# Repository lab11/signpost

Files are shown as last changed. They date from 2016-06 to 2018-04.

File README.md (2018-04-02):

Signpost
========



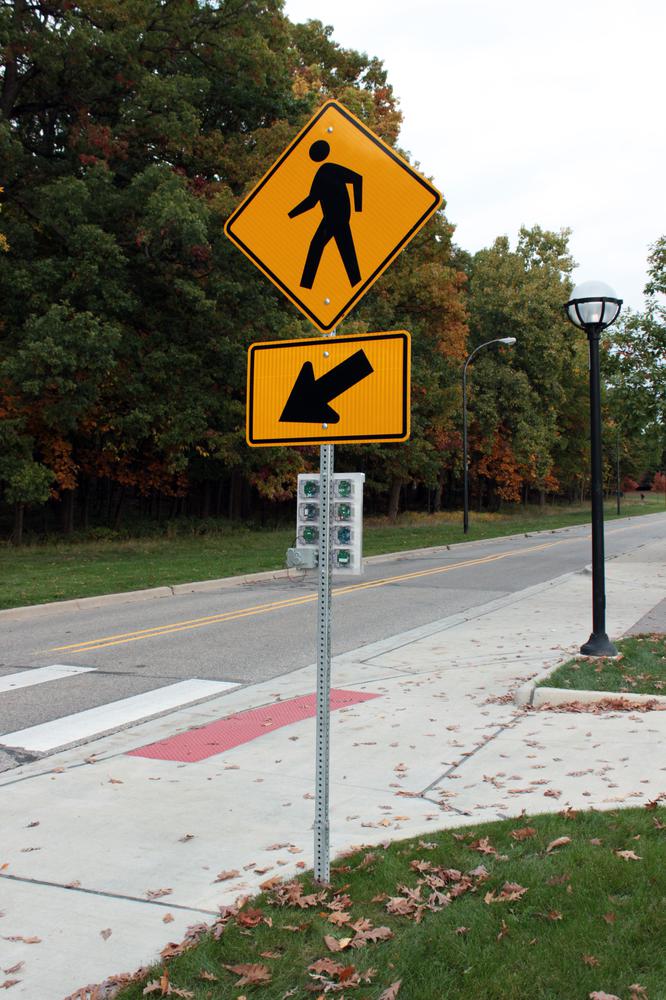
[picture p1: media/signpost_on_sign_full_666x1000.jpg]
Signpost

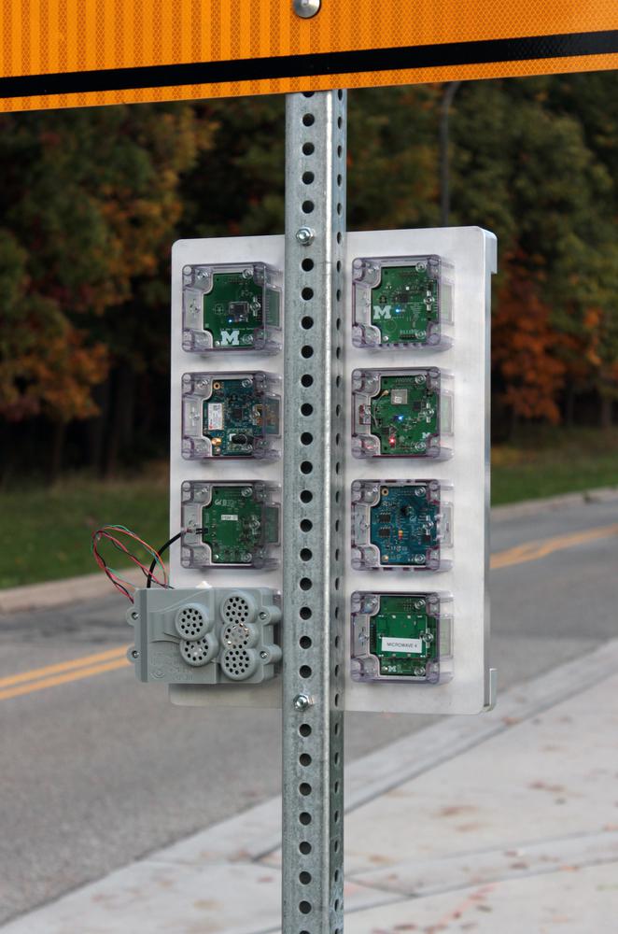
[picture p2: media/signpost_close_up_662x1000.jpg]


The Signpost project is a modular city-scale sensing platform that is designed 
to be installed on existing signposts. It is powered through solar energy harvesting, 
and provides six slots for generic sensing tasks. Modules have access to
a set of shared platform resources including power, communication, gps-based
location and time, storage, and higher-performance computation, and they
use a Signpost-specific software API that enables not only use of these
resources, but also supports the development of inter-module applications.

The project is driven by several core applications, but also strives to be
an upgradeable and adaptable platform that supports new applications
for scientists and cities. Modules can be added and removed from the platform
after deployment without disassembling the installed Signpost, reprogramming
the Signpost, or interrupting the other functions of the Signpost. Additionally,
by providing APIs to modules that support common operations, developing and
deploying a sensing application in a city is significantly streamlined. A focus
of this project is ensuring that domain scientists and researchers interested
in city-scale applications can effectively leverage this platform to accelerate
their projects.

<br />

Hardware Architecture
---------------------

Each Signpost platform includes a power supply that also meters energy usage, a controller that provides
storage and computation and manages the operation of the Signpost, and several module slots that support
extensible sensor modules for city-scale sensing applications. All modules are connected via an I2C bus,
and core system features (e.g. per-module energy metering) are on a SMBus network. For higher bandwidth
communication on the Signpost, each module is also attached to a USB 2.0 host.

Each module can be individually disconnected from the USB host and/or the I2C bus, as well as entirely
powered off.

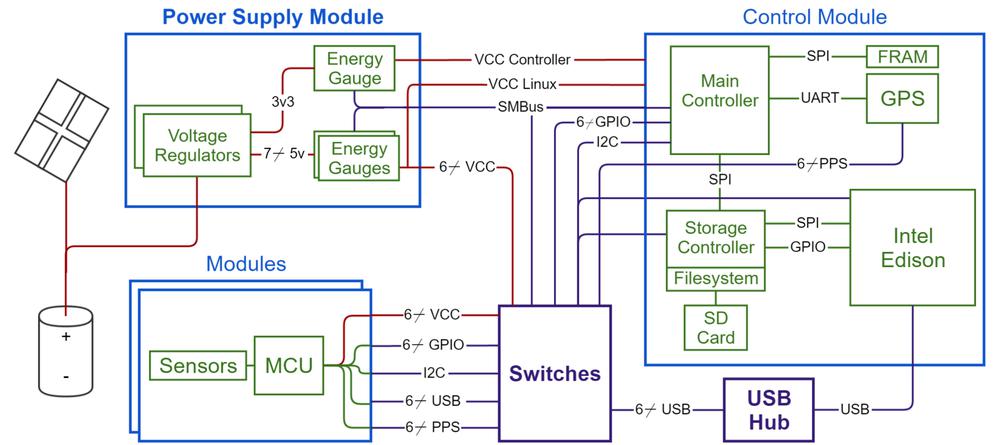
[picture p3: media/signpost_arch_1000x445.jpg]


Software Architecture
--------------------

Signpost sensor modules access platform resources through the Signpost API, which
is a library that sits between the user's applications and the Signpost I2C bus.
The API is easily ported, only requiring I2C master/slave, GPIO, and timers. It
currently is ported [Tock](https://github.com/helena-project/tock) and [ARM MBed-OS](https://mbed.com),
with a port coming soon for Arduino. 
Please see the [Signpost API documentation](https://github.com/lab11/signpost-software/blob/master/ApiGuide.md).

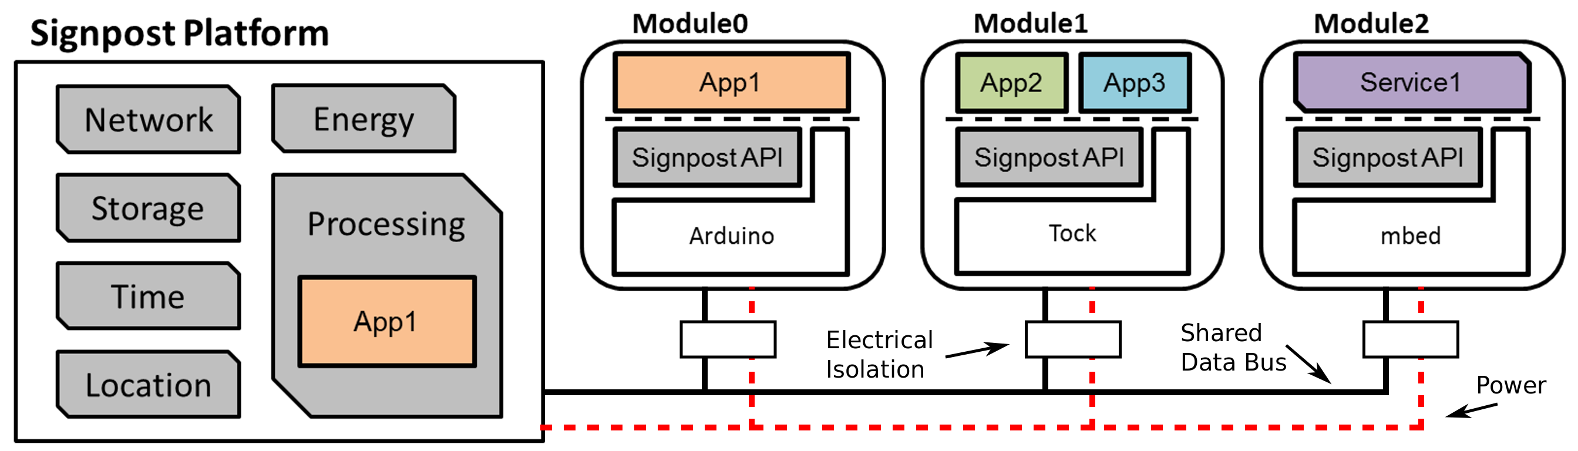
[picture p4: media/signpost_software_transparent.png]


Current Project Status
----------------------

Signposts are currently being deployed on campus at UC Berkeley. We have 5 Signposts
deployed and more than 20 built and awaiting deployment approval. On
these signposts we have modules sensing audio amplitude on seven spectrum bands, 
ambient environmental markers including temperature, pressure, and humidity, RF Spectrum
monitoring from 15-2700 MHz, and a microwave-radar based motion sensor. We are 
working to build applications such as distributed traffic monitoring on the
deployed platforms.

Signpost development kits have been designed to facilitate sensor module
and software development without requiring a full signpost platform. The
development kits have the ability to fully emulate a signpost including
energy metering and a Signpost radio module.

We are working to release version 1.0 of the Signpost Software API. 

Getting Involved
----------------

There are several ways to get involved with the Signpost Project! These
include building and deploying full signpost platforms, deploying new
sensor modules on our existing platforms, or deploying new applications on
existing sensor modules. If you would like to deploy city-scale sensing applications
using Signpost, please email <signpost-admin@eecs.berkeley.edu>.

Below are getting started guides for the Signpost platform.

 - [Creating a Sensor Module](https://github.com/lab11/signpost/blob/master/docs/Creating-Modules.md)
 - [Signpost API Guide](https://github.com/lab11/signpost-software/blob/master/docs/ApiGuide.md)

Roadmap
-------

Developing the Signpost platform is an ongoing effort with several primary
goals:

- Designing a programming model for running applications across a network of
Signposts. This should truly simplify creating interesting and useful applications,
and not discourage development by imposing unnecessary hurdles.
- Creating a HW/SW test framework for accelerating module development.
- Deploying several driving applications on the existing signpost deployment.
- Collaborating with other researchers to serve as a foundation for city-scale sensing
and wireless research.

### History

- **April 2018**: We are presenting the signpost paper and an associated demo at IPSN 2018 in Porto, Portugal.
- **February 2018**: The [signpost paper](https://arxiv.org/pdf/1802.07805.pdf) is released on the arXiv.
- **January 2018**: Signpost accepted to IPSN 2018!
- **November 2017**: Signpost demo at Sensys 2017!
- **Fall 2017**: 20 Signposts were built and deployed for the TerraSwarm Annual Review! 5 of these are still deployed
on UC Berkeley's campus, and we are awaiting approval to deploy the remaining 15 signposts. We successfully
collaborated with researchers from UIUC and UC San Diego to demonstrate audio event detection on Signposts
and high-fidelity data backhaul to a drone deployed upon event detection. Check out the [video](https://www.youtube.com/watch?v=CGQCMqiHP2c).
- **August 2017**: Signpost presentation at the Intel Secure Internet of Things Retreat. A Signpost was transported
and successfully deployed for the 48 hours of the retreat, becoming operational in less that five minutes.
- **Summer 2017**: The first Signposts are being deployed on UC Berkeley's campus!
- **Winter 2017**: Signpost v0.2 released for the
[TerraSwarm Signpost Workshop](https://www.terraswarm.org/urbanheartbeat/wiki/Main/SignpostWorkshop).
This workshop featured the release of the Debug Backplane, initial API
implementations for signpost modules, and tutorials for getting started with
the Signpost platform.
- **Fall 2016**: Signpost v0.1 presented at [TerraSwarm Annual Review](https://www.terraswarm.org/conferences/16/annual/).
The demo included six modules (ambient conditions, 2.4 GHz RF sensing, LoRa/BLE radios,
ambient audio level, microwave radar, and air quality sensing from UCSD), data communication
over LoRa to a gateway, and a real-time UI.
- **Summer 2016**: Discussions on physical design yield a prototype enclosure and module form factor.

Related Projects
----------------

City-scale sensing platforms are a growing area of research with several emerging
approaches:

- Chicago's [Array of Things](https://arrayofthings.github.io/)
- NYC's [SONYC](https://wp.nyu.edu/sonyc/)

We see Signpost as one part of the city-scale sensing ecosystem, and
we hope to eventually deploy dynamic applications that can be distributed
across high granularity energy-harvesting nodes (Signposts) and
powered nodes such as Array of Things. Hopefully applications
such as SONYC can lower the cost of deployment by running on
Signpost platforms.

License
-------

Licensed under either of

 * Apache License, Version 2.0
   ([LICENSE-APACHE](LICENSE-APACHE) or http://www.apache.org/licenses/LICENSE-2.0)
 * MIT license
   ([LICENSE-MIT](LICENSE-MIT) or http://opensource.org/licenses/MIT)

at your option.

### Contribution

Unless you explicitly state otherwise, any contribution intentionally submitted
for inclusion in the work by you, as defined in the Apache-2.0 license, shall be
dual licensed as above, without any additional terms or conditions.

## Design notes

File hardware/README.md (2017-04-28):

Signpost Hardware
=================

This folder collects all of the core hardware that makes up the signpost platform.
For modules made by Lab11, visit the [modules folder](../modules).

SMBus Addresses
---------------
_Private bus for controller / power / backplane_

### Backplane
| Thing | Part Number | Address (bin) | Address (hex) |
|---|---|---|---|
| GPIO Extender Mod0 | MCP23008 | 0100000 | 0x20 |
| GPIO Extender Mod1 | MCP23008 | 0100001 | 0x21 |
| GPIO Extender Mod2 | MCP23008 | 0100010 | 0x22 |
| GPIO Extender USB | MCP23008 | 0100011 | 0x23 |
| GPIO Extender Mod5 | MCP23008 | 0100101 | 0x25 |
| GPIO Extender Mod6 | MCP23008 | 0100110 | 0x26 |
| GPIO Extender Mod7 | MCP23008 | 0100111 | 0x27 |
| EEPROM ID | M24C01 | 1010001 | 0x51 |

### Power
| Thing | Part Number | Address (bin) | Address (hex) |
|---|---|---|---|
| SMBUS Switch 0 | PCA9544A | 1110000 | 0x70 |
| SMBUS Switch 1 | PCA9544A | 1110001 | 0x71 |
| SMBUS Switch 2 | PCA9544A | 1110001 | 0x72 |
| Battery Monitor Addr[000:0FF] | MAX17205 | 0110110 | 0x36 |
| Battery Monitor Addr[100:17F] | MAX17205 | 0001011 | 0x0B |
| Module Coulomb Counter (x8) | LTC2943 | 1100100 | 0x64 |
| Solar Coulomb Counter | LTC2943 | 1100100 | 0x64 |
| EEPROM ID | M24C01 | 1010000 | 0x50 |

Signpost I2C Network
--------------------
_The shared I2C bus that runs to each module_

### Controller
| Thing | Address(es) |
|---|---|
| Controller | 0x20 |
| Storage | 0x21 |

### Modules
| Thing | Address(es) |
|---|---|
| Radio Module | 0x22 |
| Scanner154 Module | 0x31 |
| Ambient Sensing Module | 0x32 |
| Audio Sensing Module | 0x33 |
| Radar Module | 0x34 |
| Air Quality Module (UCSD) | 0x35 |

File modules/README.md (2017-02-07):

Signpost Modules
================

Modules that plug into the signpost to do sensing and other applications.

This directory contains modules developed and supported by Lab11 for the signpost platform:

| Module | Capabilities
|---|---|
| Ambient | Environmental monitoring. Includes pressure, ambient light, humidity, motion detection, and temperature |
| Arduino | An Aruduino clone that allows you to load and run arduino sketches and plug in Ardunio shields |
| Audio Spectrum  | Real-time audio sampling capable of binning by frequency or computing on raw audio data |
| Microwave Radar | Passive motion detection that measure the velocity, proximity, rough size, and material estimation of nearby moving objects |
| RF Spectrum | A wide band spectrum monitor |
| Spectrum 15.4 | Sweeps and monitors all channels defined in the 802.15.4e, reporting the energy present in each channel |

Third-Party Modules
-------------------

| Contact | Module | Capabilities |
|---|---|---|
| [Michael Ostertag](mailto:mosterta@eng.ucsd.edu) | [UCSD Air Quality](https://bitbucket.org/mmenarini/metasensefirmwareble) | Air quality monitor with CO, VOC, NO2, O3 sensors |

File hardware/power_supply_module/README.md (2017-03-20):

Power Supply Module
===================

<!-- XXX A picture would be super nice here XXX _Neal_ XXX -->

The power module monitors and supplies energy for all signpost subsystems.
It tracks the amount of energy collected from the solar panel, the state of the
battery, and monitors the energy consumed by each module. The power module can
be configured to alert (via `!SMBALERT`) when a module or subsystem draws an
excess amount current or energy, however the controller must issue commands to cut
power if needed.  In extreme cases (i.e. shorts), the power module does include
power distribution switches that will limit power output to safe ranges.

Physical Layout
---------------
The Power Module has one header that it uses to interact with the Backplane: a 20-pin header on top.

| Description | Signal | Pin  | Pin  | Signal | Description |
|---|---|---|---|---|---|
| Ground | GND | `01` | `02` | VCC_Cont | VCC for Controller and Storage Master (5V)  |
| SMBus Data Line | SMBData | `03` | `04` | VCC_Linux  | VCC for Linux (5V) |
| SMBus Clock Line | SMBCLK | `05` | `06` | !SMBALERT  | SMBus Alert line |
| VCC for Module 0 (5V) | VCC_MOD0 | `07` | `08` | VCC_MOD1 | VCC for Module 1 (5V) |
| VCC for Module 2 (5V) | VCC_MOD2 | `09` | `10` | VCC_MOD5 | VCC for Module 5 (5V) |
| VCC for Module 6 (5V) | VCC_MOD6 | `11` | `12` | VCC_MOD7 | VCC for Module 7 (5V) |
| VCC for Backplane (3.3V) | VCC_BACK | `13` | `14` | _Reserved_ | |
| | _Reserved_ | `15` | `16` | !WATCHDOG  | Watchdog input (active low) |
| Positive connection from battery | VBATT+ | `17` | `18` | VBATT- | Negative connection from battery |
| Positive connection from solar panel | VSOL+ | `19` | `20` | VSOL- | Negative connection from solar panel |

Requirements / Assumptions
--------------------------

The power supply module expects a maximum battery voltage of 12.6V (three 4.2V
cells) and a lithium ion based chemistry. Subsystem power regulation is able to
handle higher voltages (up to 20V), but the battery monitor and charger are
configured for a 12.6V battery and a solar panel that outputs a maximum of
17.5V. The solar panel and battery monitor and charger circuits can be
reprogrammed with different resistor divider networks to accommodate different
battery and solar panel voltages.

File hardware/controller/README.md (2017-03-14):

Control Module
=================

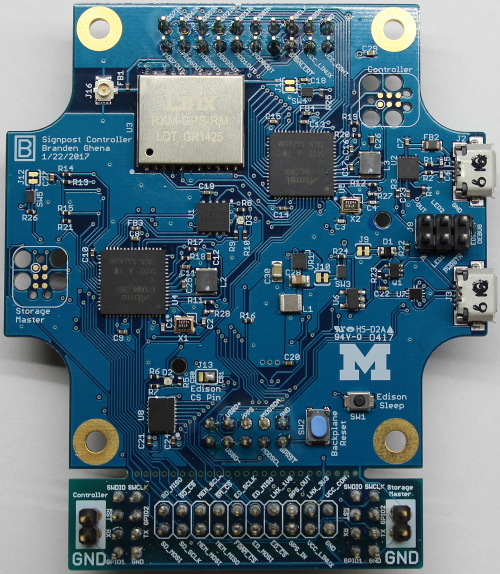
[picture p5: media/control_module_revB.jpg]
Control Module


The Control Module is the brains of the Signpost. It contains two logical
units: the Controller and the Storage Master. The Controller is in charge of
isolation, initialization, energy monitoring and API, and time and location
APIs. The Storage Master is in charge of the SD card and storage API, as well
as managing an Intel Edison also on the Control Module. While the Intel Edison
is highly capable, its energy needs are too great to sustain always-on
operation on the Signpost. Instead, the Edison is thought of as a co-processor,
capable of occasional batch processing of data.

Physical Layout
---------------

### Main Header Signals

The Control Module has two headers that it uses to interact with the Backplane:
a 20-pin header on top and a 10-pin header on bottom.

| Description | Signal | Pin | | Pin | Signal | Description |
|---|---|-----|---|-----|---|---|
| Ground | GND | 1 | | 2 | VCC_CONTROLLER | VCC for Controller and Storage Master (5V)  |
| SMBus Data Line | SMBDATA | 3 | | 4 | VCC_LINUX | VCC for Linux (5V) |
| SMBus Clock Line | SMBCLK | 5 | | 6 | !SMBALERT | SMBus Alert line (active low) |
| Watchdog output (active low) | !WATCHDOG | 7 | | 8 | Reserved | |
| Digital output to Module 0 | MOD0_IN | 9 | | 10  | MOD0_IN | Digital input from Module 0 |
| Digital output to Module 1 | MOD1_IN | 11  | | 12  | MOD1_IN | Digital input from Module 1 |
| Digital output to Module 2 | MOD2_IN | 13  | | 14  | MOD2_IN | Digital input from Module 2 |
| Digital output to Module 5 | MOD5_IN | 15  | | 16  | MOD5_IN | Digital input from Module 5 |
| Digital output to Module 6 | MOD6_IN | 17  | | 18  | MOD6_IN | Digital input from Module 6 |
| Digital output to Module 7 | MOD7_IN | 19  | | 20  | MOD7_IN | Digital input from Module 7 |

| Description | Signal | Pin | | Pin | Signal | Description |
|---|---|-----|---|-----|---|---|
| Ground | GND | 1 | | 2 | !BACKPLANE_RESET | Reset line for Backplane (active low) |
| I²C data line to Modules | MODULES_SDA | 3 | | 4 | MODULES_SCL | I²C clock line to Modules |
| Pulse per second from GPS | PPS | 5 | | 6 | Reserved | |
| USB data+ (to Backplane hub) | USB_D+ | 7 | | 8 | USB_D- | USB data+ (to Backplane hub) |
| | Reserved | 9 | | 10  | Reserved | |

### Debug Header Signals

The Control Module also has two headers used for debugging. These mate with the
Debug Backplane to enable easier development. There are two 8-pin headers: one
on the left for the Controller and one on the right for the Storage Master. The
pinout for each is identical.

| Description | Signal | Pin | | Pin | Signal | Description |
|---|---|-----|---|-----|---|---|
| | GND | 1 | | 2 | GPIO1 | Output line to control LED on development backplane |
| UART data from the module | TX | 3 | | 4 | RX | UART data to the module |
| Output line to control LED on development backplane | GPIO2 | 5 | | 6 | !Reset | Active-low reset for the module microcontroller |
| JTAG line for the module microcontroller | SWDCLK | 7 | | 8 | SWDIO | JTAG line for the module microcontroller |

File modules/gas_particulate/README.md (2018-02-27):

Plans for making a Gas and Particulate Sensor
=============================================

We have been theorizing about making a module that senses key indicators
of outdoor air quality through the duration of the project, and air quality
is a key motivator many of Signpost's potentially 'killer applications'.
These include dynamic rerouting of traffic to shift hot-spots for poor 
air quality and pedestrian routing around these locations along with simpler
long term, highly granular air quality measurement to test the hypothesis
that air quality can change the lives of city residents block-by-bock. 
We also had high particulate counts in Berkeley in the relatively
recent past due to the North Bay fires, and it would be nice to measure
how equally this air quality is impacting the city.

That being said, we have held off on creating an air quality sensor because
they are notoriously difficult to produce with high accuracy. 
[EPA and AQMD reports](http://www.aqmd.gov/aq-spec/sensors)
largely support our skepticism, with many air quality sensors less than $1000-$2000
being very poor indicators of the key metrics in the space. The desire to have
an air quality module hasn't subsided, however, and what follows is a high level
analysis of the potential sensors we can use to create an easy, cheap, and
relatively accurate air quality monitor for the platform. 

## What to Measure?
A survey of outdoor air quality sensors yielded:
 - Particulate (usually PM2.5)
 - Ozone (O<sub>3</sub>)
 - Nitrogen Dioxide (NO<sub>2</sub>)
 - Carbon Monoxide (CO)
 - Sulfur Dioxide (SO<sub>2</sub>)

Of these, EPA reports most focus on particulate matter, 
ozone, and nitrogen dioxide, with carbon monoxide and sulfur dioxide taking
less of a focus. This is not the most concrete scientific evidence for
choosing these gasses, but to effectively implement this module without
too much effort, the sensor should be limited to those which have clear and 
working examples.

### PM2.5 and  Other Particulate

PM2.5 sensors found in most cheaper air quality monitors are produced by
[Shinyei](http://www.shinyei.co.jp/stc/eng/optical/index.html). These
sensors seem to very greatly in accuracy, however some of them
prove to be rather accurate when compared to very expensive reference
sensors. Specifically, the [PPD60PV-T2](http://www.shinyei.co.jp/stc/eng/optical/main_ppd60pv.html)
used in the [AirBeam sensor](http://www.takingspace.org/aircasting/airbeam/)
and the [Air Quality Egg V2](https://airqualityegg.wickeddevice.com/)
has been shown 
[by](http://www.aqmd.gov/docs/default-source/aq-spec/field-evaluations/air-quality-egg-v2_pm---field-evaluation.pdf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) 
[several](https://www.atmos-meas-tech.net/9/5281/2016/amt-9-5281-2016-discussion.html) 
[authors](http://www.aqmd.gov/docs/default-source/aq-spec/field-evaluations/airbeam---field-evaluation.pdf?sfvrsn=4) 
to have a relatively good linear fit to FEM sensors, however it still seems
to be overly sensitive and in need of calibration. The EPA shows
several of the other sensors by Shinyei to perform 
[similarly](https://cfpub.epa.gov/si/si_public_record_report.cfm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).
The PPD42NJ, a similar sensor used in the Air Quality Egg V1 produces 
[embarrassingly bad results](http://www.aqmd.gov/docs/default-source/aq-spec/field-evaluations/air-quality-egg-v1---field-evaluation.pdf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),
and Shinyei has at least one new product out that has not been tested.

While the PPD60PV-T2 would probably fit our purposes well, it does not
fit in the Signpost module case. This isn't an absolute problem - we could
build an external enclosure, but it's not ideal. The new Shinyei sensor
would fit into the case, however we don't want to use an untested sensor given
that Shinyei's quality seems to be shaky.

The only other sensor that seems to disclose that they use an OEM module for
PM2.5 is the [PurpleAir](https://www.purpleair.com/). The purple air uses two
PMS5003 sensors, and performs very well for this class of sensor 
in both 
[field](http://www.aqmd.gov/docs/default-source/aq-spec/field-evaluations/purple-air-pa-ii---field-evaluation.pdf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) and 
[lab](http://www.aqmd.gov/docs/default-source/aq-spec/laboratory-evaluations/purple-air-pa-ii---lab-evaluation.pdf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) testing.
The first version of the PurpleAir used the PMS1003, and also performed well, but not as well as the updated version.

Luckily the PMS5003 is both small, can be ordered for a reasonable price, and has an integrated fan. It
also streams data about many particulate classes over UART, which makes it easy to integrated with an MCU.
This seems like the best option for a Signpost module. The inclusion of two sensors in the PurpleAir does make us
question its reliability, and we may consider the option of stacking two sensors into a module box.

### Ozone

[Several reports](https://www.epa.gov/air-sensor-toolbox/evaluation-emerging-air-pollution-sensor-performance) show that the MICS-2614 and MICS-2610 Ozone sensor perform well
under testing. Additionally, these Metal Oxide sensor are cheap, small and
relatively easy to use because they have a resistive response.

Unfortunately the company that made these sensors, e2v scientific, was acquired
by SGX Sensortech, and SGX stopped producing ozone sensors after the acquisition.

You can find knock-off version of the same sensor from Chinese suppliers, however
their performance is unclear, and after asking for quotes from many of these
suppliers, only one has the sensors in stock.

While we could use an electrochemical ozone sensor, there are not very many
on the market, and their ease of integration is questionable (electrochemical
sensors require analog front ends to convert and amplify the signal). Prebuilt
ozone detection modules that use semiconductor based technologies like the ones from [Aeroqual](http://www.gas-sensing.com/fixed-mount-monitors/aeroqual-sm-50.html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) have [shown to be accurate](https://www.atmos-meas-tech.net/9/5281/2016/amt-9-5281-2016-discussion.html),
however they are very expensive.

We don't have a good recommendation for an available and easy to integrate
ozone sensor at this time.

### Nitrogen Dioxide and Carbon Monoxide

Similar to Ozone, there are existing metal oxide sensors to measure both
[Nitrogen Dioxide and Carbon Monoxide](https://sgx.cdistore.com/Manufacturers/e2v/FP/metaloxide-gas-sensor/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). These have been shown to work pretty well, although not perfectly in 
[several](https://www.epa.gov/air-sensor-toolbox/evaluation-emerging-air-pollution-sensor-performance) 
[different](http://www.aqmd.gov/docs/default-source/aq-spec/field-evaluations/smart-citizen-kit---field-evaluation.pdf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),
scenarios, but the sensors may need to individually calibrated and could drift over time.

This seems like a reasonable choice for a low-cost gas sensor, however it's unclear the
actual impact that these measurements may have due to the potentially
for drifting baselines and low-reliability data.

### Sulfur Dioxide

The only cheaper sulfur dioxide sensor that we can find is the 
SPEC SO<sub>2</sub> sensor. Given the poor performance of the other spec sensors and lack
of testing we don't think it is worth trying to measure sulfur dioxide at this time.

## Conclusions
It seems that building a PM2.5 module out of the PMS5003 sensor could be a good
start to deploying low-cost, medium-reliability particle sensors on the Signpost platform, however
expanding to other sensors begins to go down a path of high difficulty for
potentially limited impact due to unreliable and untrusted data.

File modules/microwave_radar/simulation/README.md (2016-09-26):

Circuit simulation for microwave radar
===============

This folder contains all the files needed to recover the microwave radar simulation under Cadence Pspice. A student version would be sufficient to simulate the circuit.

To start, click on opj file and create a simulation. If you have any questions, please contact haoyifan@umich.edu

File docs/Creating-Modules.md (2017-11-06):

Creating Signpost Modules
=========================

To create a module for the signpost, it must conform to the module specification.

Physical Dimensions
-------------------

All in inches.

<a href="https://raw.githubusercontent.com/lab11/signpost/master/media/module_pcb_dimensions.png">
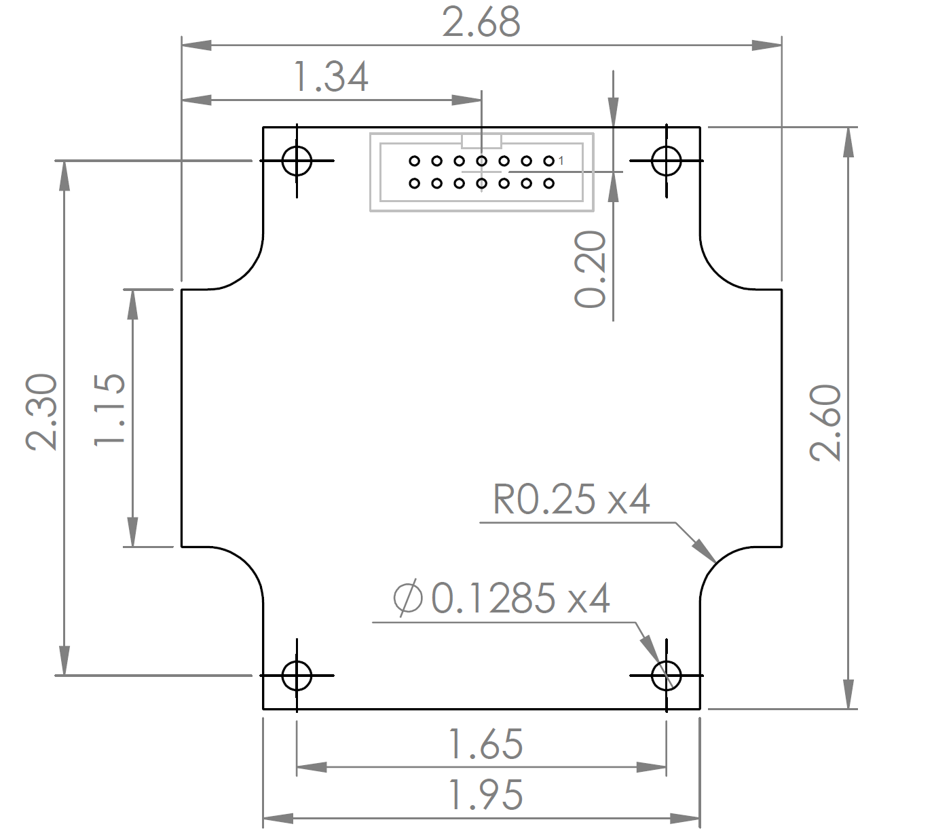
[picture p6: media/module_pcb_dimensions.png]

</a>

Header Signals
--------------

| Description | Signal | Pin | | Pin | Signal | Description |
|---|---|-----|---|-----|---|---|
| | GND | 1 | | 2 | 5V | |
| | Reserved | 3 | | 4 | VCCIO | I/O voltage the module uses. This must be fed by the module to set the I/O voltage. |
| I²C clock line. | SCL | 5 | | 6 | SDA | I²C data line. |
| Pulse per second from GPS. | PPS | 7 | | 8 | MOD_OUT  | Interrupt line to the controller. Allows modules to signal the controller. |
| | Reserved | 9 | | 10  | MOD_IN | GPIO from controller to module. |
| USB Data+ signal. | USB_D+ | 11  | | 12  | USB_D- | USB Data- signal. |
| USB bus voltage (5 V). | USB_VBUS | 13  | | 14  | GND | USB GND. |

Debug Header Signals
-------------------

Modules may choose to implement a Debug header as well. The Debug header will allow for easier interactions with modules while they are connected to the development version of the backplane.

| Description | Signal | Pin | | Pin | Signal | Description |
|---|---|-----|---|-----|---|---|
| | GND | 1 | | 2 | GPIO1 | Output line to control LED on development backplane |
| UART data from the module | TX | 3 | | 4 | RX | UART data to the module |
| Output line to control LED on development backplane | GPIO2 | 5 | | 6 | !Reset | Active-low reset for the module microcontroller |
| JTAG line for the module microcontroller | SWDCLK | 7 | | 8 | SWDIO | JTAG line for the module microcontroller |

Existing Hardware Libraries and References
-----------------------------------------

We have built sensor modules using both KiCAD and EAGLE. Generic
module libraries that include a reference outline and header location
are available in the [Signpost Eagle Library](https://github.com/lab11/signpost/blob/master/hardware/signpost.lbr).

All example sensor modules can be found in the [modules folder](https://github.com/lab11/signpost/tree/master/modules).

Tips 
----

We generally recommend using a processor supported by [Tock](https://github.com/helena-project/tock)
or [ARM Mbed](https://mbed.com).

Holes in the sensor modules that allow it to screw to the signpost
backplane should be plated and tied to ground.

Module Review
-------------

We are happy to provide guidance
on module creation! Feel free to reach out to us either through
an issue or email at <signpost-admin@eecs.berkeley.edu>

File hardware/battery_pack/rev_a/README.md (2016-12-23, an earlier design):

This is a first pass at a signpost battery pack.

It will be simple. Several li-ion cells with a protection IC.

I would like to have OV/UV/OT/UT protection.

In the future we may consider adding active temperature
compensation (such as a pcb heater under the batteries),
but this design will not include that feature.

I am planning on using the TIbq77904. This will protect
series li-ion cells. It will not balance them (and could 
therefore not get optimal pack lifetime) but it is a 
relatively simple first pass.

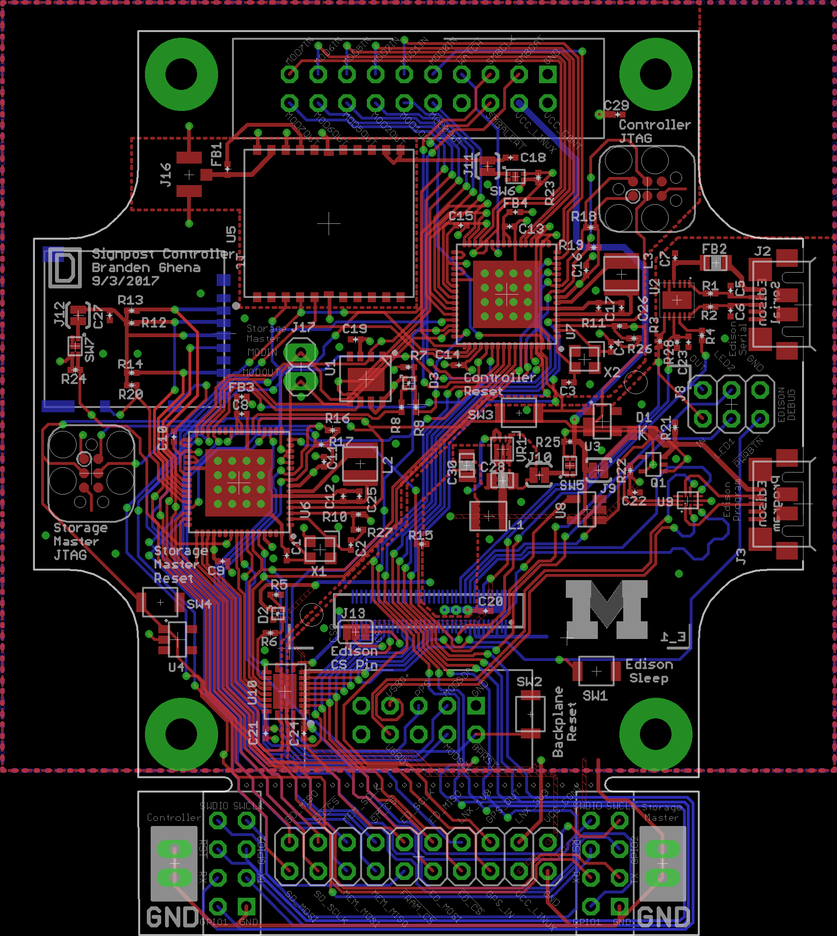
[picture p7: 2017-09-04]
hardware/controller/rev_d/controller_pcb.png

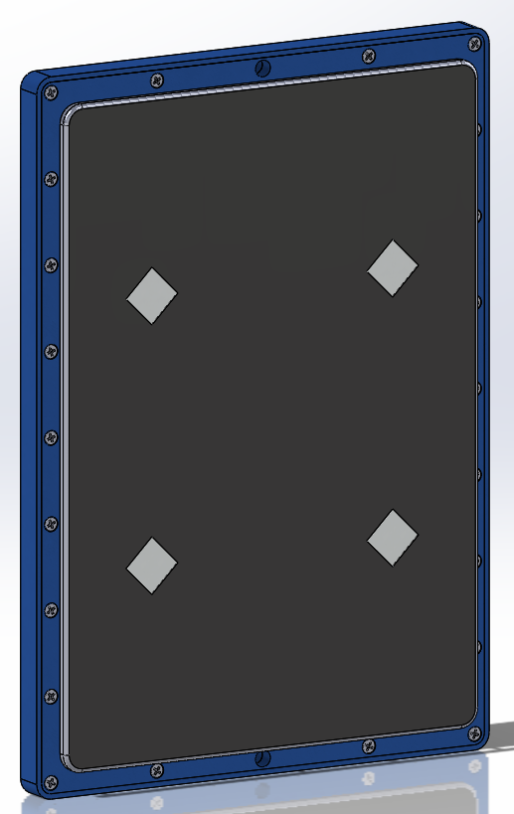
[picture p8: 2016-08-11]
media/signpost_case_with_panel_cad.png

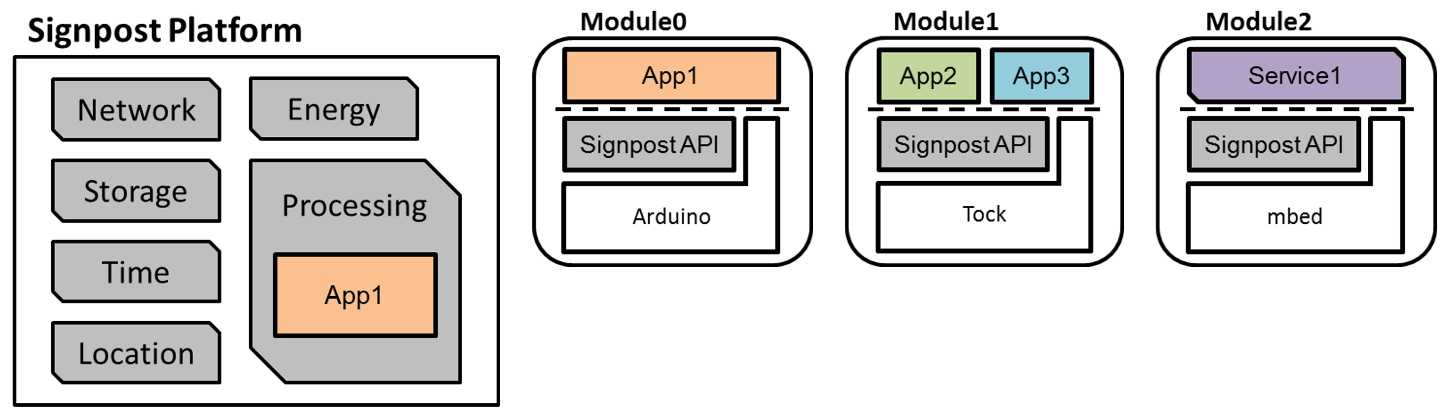
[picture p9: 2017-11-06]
media/signpost_software.png

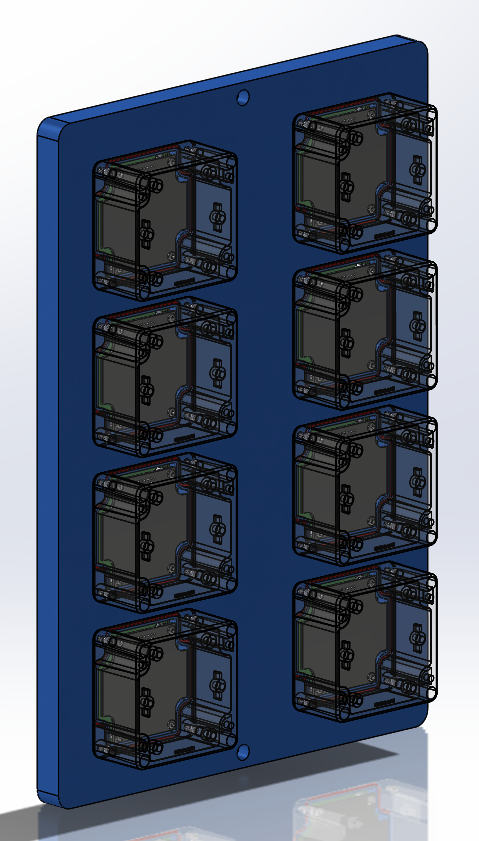
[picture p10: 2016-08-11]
media/signpost_case_cad.png

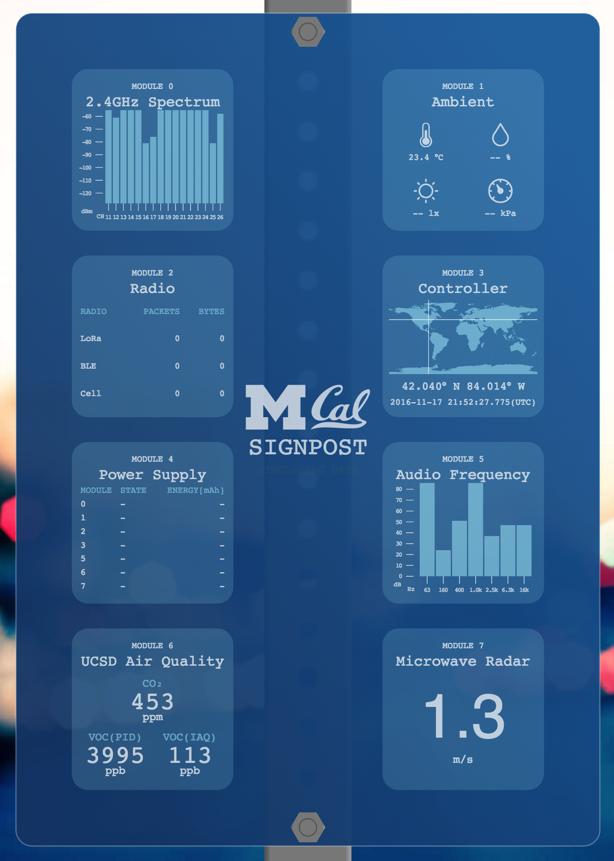
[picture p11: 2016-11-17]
media/signpost_demo_ui_2016.png

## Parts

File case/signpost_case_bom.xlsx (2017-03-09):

Quantity | Part | DigiKey | McMaster Carr | Amazon | Allied | Mouser | Newark | sign bracket store | Number to Order | Notes
1 | Signpost Case Cover
1 | Signpost Case Back
2 | Solar panel Mount
22 | Outside case screw |  | 91771A194 |  |  |  |  |  | 1 | 8-32x1/2 flat
4 | Corner Screw (through solar panel mount) |  | 91771A201 |  |  |  |  |  | 1 | 8-32x1-1/4 flat
20 | Backplane PCB screw |  | 91772A105 |  |  |  |  |  | 1 | 4-40x3/16
6 | Solar panel mount standoffs |  | 93330A435 |  |  |  |  |  | 6 | 4-40x1/2x0.25 OD
6 | Solar panel mount screws |  | 92196A109 |  |  |  |  |  | 1 | 4-40 x 7/16 Socket head cap
2 | Signpost attachment Bolts |  | 90128A636 |  |  |  |  |  | 1 | 3/8-16 x 3 socket head cap
2 | Signpost attachment Nuts |  | 97135A230 |  |  |  |  |  | 1 | 3/8-16 locknut
32 | Module case screw |  | 96710A218 |  |  |  |  |  | 1 | 4-40x3/8 torx
8 | Module case cover and screws | SRB33-TCBC-ND |  | https://www.amazon.com/Serpac-RB33-1TC1BC-Polycarbonate-Plastic-Enclosure/dp/B00DEQCX02 | Serpac RB33 - 1TBC |  |  |  | 8 | Clear plastic module box
5ft | O-ring material |  | 1177N11 |  |  |  |  |  | 5ft | 1/16 O-ring cord
32 | Module standoffs |  | 91780A531 |  |  | 761-2056-440-AL-7 |  |  | 32 | 4-40x7/16,3/16" hex standoff
64 | Module standoff screws |  | 90272A106 |  |  |  |  |  | 64 | 4-40x1/4 ss round head
2 | Waterproof cable entries (heyco) |  |  |  |  | 836-C2058 (http://www.mouser.com/ProductDetail/Heyco/C2058/) |  |  | 2 | 2-5mm waterproof cable entry
1 | battery case cable gland |  |  |  |  |  | 02M0334 (http://www.newark.com/lapp-kabel/52001880/cable-gland-brass-thrd-sz-m8/dp/02M0334)
2 | signpost adapter bracket (if pole is round) |  |  |  |  |  |  | http://www.hooksandlattice.com/street-brackets.html | 2

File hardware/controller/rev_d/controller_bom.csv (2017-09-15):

# Bill of Materials
# Converted from {}
# Generated by bom_to_text.py
#
Qty | Value | Device | Package | Parts | Description | Do Not Insert | Can Substitue? | Manufacturer Part Number | Manufacturer | Distributor | Digikey Part Number | Mouser Part Number | Notes
4 | 8pF; +/- 0.1 pF | CAPACITOR0402_CAP | 0402_CAP | C1, C2, C3, C4 | Capacitor |  | Y | GRM1555C1H8R0BA01D | Murata | Digikey | 490-8230-1-ND |  | Must be +/- 0.1 pF or better
2 | 47pF | CAPACITOR0402_CAP | 0402_CAP | C5, C6 | Capacitor |  | Y | GRM1555C1H470FA01D | Murata | Digikey | 490-6241-1-ND
1 | 10nF | CAPACITOR0402_CAP | 0402_CAP | C7 | Capacitor |  | Y | GRM155R61A103KA01D | Murata | Digikey | 490-6296-1-ND
17 | 100nF | CAPACITOR0402_CAP | 0402_CAP | C8, C9, C10, C11, C12, C13, C14, C15, C16, C17, C18, C19, C20, C21, C22, C23, C24 | Capacitor |  | Y | GRM155R71A104JA01D | Murata | Digikey | 490-10777-1-ND
3 | 4.7uF | CAPACITOR0402_CAP | 0402_CAP | C25, C26, C27 | Capacitor |  | Y | ZRB15XR61A475KE01D | Murata | Digikey | 490-13252-1-ND
1 | 10uF | CAPACITOR0805_CAP | 0805_CAP | C28 | Capacitor |  | N | GRM21BR71A106ME51L | Murata | Digikey | 490-8316-1-ND
1 | 10uF | CAPACITOR0402_CAP | 0402_CAP | C29 | Capacitor |  | Y | GRM155R60J106ME44D | Murata | Digikey | 490-13811-1-ND
1 | 22uF | CAPACITOR0805_CAP | 0805_CAP | C30 | Capacitor |  | N | GRM21BR60J226ME39L | Murata | Digikey | 490-1719-1-ND
1 | DIODE | SCHOTTKY DIODE | 0805_DIODE | D1 |  |  | Y | SD0805S020S1R0 | AVX | Digikey | 478-7800-1-ND |  | Forward Voltage (Max) must be 450mV or less at 1A
2 | SML-LX0404SIUPGUSB | SML-LX0404SIUPGUSB | 1MM_SQ_4PAD | D2, D3 | 1mm^2 RGB LED |  | N | SML-LX0404SIUPGUSB | Lumex Opto/Components | Digikey | 67-2125-1-ND
1 | EDISON_CONNECTOR_SEGMENTED | EDISON_CONNECTOR_SEGMENTED | EDISON_DAUGHTER | E_1 |  |  | N | DF40HC(3.0)-70DS-0.4V(51) | Hirose | Mouser |  | 798-DF40HC3070DS4V51
1 | 300Ohm | FERRITE_BEAD0402 | 0402_CAP | FB1 |  |  | Y | ACML-0402-301-T | Abracon | Digikey | ACML-0402-301-TCT-ND
1 | 600Ohm | FERRITE_BEAD0805 | 0805_CAP | FB2 |  |  | Y | MI0805K601R-10 | Laird Signal Integrity Products | Digikey | 240-2390-1-ND
2 | 1.5kOhm | FERRITE_BEAD0402 | 0402_CAP | FB3, FB4 |  |  | Y | CIM05J152NC | Samsung | Digikey | 1276-6395-1-ND
1 | DM3AT-SF-PEJM5 | DM3AT-SF-PEJM5 | DM3AT-SF-PEJM5 | J1 | CONN MICRO SD R/A PUSH-PUSH SMD |  | Y | DM3AT-SF-PEJM5 | Hirose | Digikey | HR1964CT-ND
2 | MICRO_USB_B_HIROSE_ZX62R-B-5P | MICRO_USB_B_HIROSE_ZX62R-B-5P | USB_MICRO_B-HIROSE-ZX62R-B-5P | J2, J3 | USB Micro B Connector |  | Y | ZX62R-B-5P(30) | Hirose | Digikey | H125274CT-ND
1 | MODULE_CONTROLLER | MODULE_CONTROLLER | MODULE_CONTROLLER | J4 | Controller module for signpost |  | Y | SBH11-PBPC-D10-ST-BK, SBH11-PBPC-D05-ST-BK, PRPC004DFBN-RC, PRPC004DFBN-RC | Sullins | Digikey | S9172-ND , S9169-ND , S2221EC-04-ND , S2221EC-04-ND |  | J4 is four physical parts
3 |  | PINHD-1X2 | 1X02 | J5, J6, J17 | PIN HEADER |  | Y | 5-146261-1 | TE Connectivity | Digikey | 5-146261-1
1 |  | PINHD-2X10 | 2X10 | J7 | PIN HEADER |  | Y | 9-146261-0-10 | TE Connectivity | Digikey | A34268-10-ND
1 |  | PINHD-2X3 | 2X03 | J8 | PIN HEADER |  | Y | 5-146261-3 | TE Connectivity | Digikey | A121473-ND
1 | U.FL-R-SMT | U.FL-R-SMT | U.FL_SMT | J16 | U.FL-R-SMT Antenna Connector |  | Y | U.FL-R-SMT-1(01) | Hirose | Digikey | H122041-ND
1 | 0.47uH | INDUCTORDFE322512C | DFE322512C | L1 | A very specific inductor |  | N | 1277AS-H-R47M=P2 | Murata | Digikey | 490-10596-1-ND | 81-1277AS-H-R47MP2
2 | 22uH | LHQ3NP | 1212 | L2, L3 | LHQ3NP Inductor |  | N | LQH3NPN220MJ0L | Murata | Digikey | 490-5350-1-ND
1 | DMN32D2LDF | DMN32D2LDF | SOT353 | Q1 | Common source dual n-channel mosfet |  | Y | DMN32D2LDF-7 | Diodes Incorporated | Digikey | DMN32D2LDF-7DICT-ND
2 | 27Ohm | RESISTOR0402_RES | 0402_RES | R1, R2 | Resistor |  | Y | RC1005F270CS | Samsung | Digikey | 1276-3907-1-ND
2 | 100Ohm | RESISTOR0402_RES | 0402_RES | R3, R4 | Resistor |  | Y | RC1005F101CS | Samsung | Digikey | 1276-3429-1-ND
5 | 1kOhm | RESISTOR0402_RES | 0402_RES | R5, R6, R7, R8, R9 | Resistor |  | Y | RC1005F102CS | Samsung | Digikey | 1276-3430-1-ND
6 | 10kOhm | RESISTOR0402_RES | 0402_RES | R10, R11, R12, R13, R14, R15 | Resistor |  | Y | RC1005F103CS | Samsung | Digikey | 1276-3431-1-ND
7 | 100kOhm | RESISTOR0402_RES | 0402_RES | R16, R17, R18, R19, R20, R21, R22, R28 | Resistor |  | Y | RC1005F104CS | Samsung | Digikey | 1276-3432-1-ND
3 | 1MOhm | RESISTOR0402_RES | 0402_RES | R23, R24, R25 | Resistor |  | Y | RC1005F105CS | Samsung | Digikey | 1276-3433-1-ND
2 | DNP | RESISTOR0402_RES | 0402_RES | R26, R27 | Resistor | X | - | RC1005F103CS | Samsung | Digikey | 1276-3431-1-ND
4 | B3U-1000P | B3U-1000P | B3U-1000P | SW1, SW2, SW3, SW4 | Switch |  | N | B3U-1000P | Omron | Digikey | SW1020CT-ND
3 | SIP3240X | SIP3240X | TDFN4 | SW5, SW6, SW7 | High power (2.4 A) high-side switch |  | N | SIP32402ADNP-T1GE4 | Vishay | Digikey | SIP32402ADNP-T1GE4CT-ND
1 | FM25CLXXB-DG | FM25CLXXB-DG | TDFN-8 | U1 | Cypress FRAM |  | N | FM25CL64B-DG | Cypress | Digikey | FM25CL64B-DGRA-ND
1 | FTDI234XD | FTDI234XD | DFN-12/3MM | U2 | FTDI234XD USB to UART Bridge in 3x3 DFN Package |  | N | FT234XD-R | FTDI | Digikey | 768-1178-1-ND | 895-FT234XD-R
2 | NCP301LSN30 | NCP301LSN30 | SOT23-5 | U3, U4 | Power-on-reset. LSN30 -> Fixed 3V (for 90% of 3.3V) detector. Fixed ~100us power_on -> deassert reset. 301 -> Open Collector !RST. |  | Y | NCP301LSN30T1G | On Semiconductor | Digikey | NCP301LSN30T1GOSCT-ND |  | Power-on-Reset with Open Collector output - 2.9-3.1V threshold okay
1 | RXM-GPS-RM-T | RXM-GPS-RM-T | RXM-GPS-RM-T | U5 | The RM Series GPS receiver module is a |  | N | RXM-GPS-RM-T | Linx Technologies | Digikey | RXM-GPS-RM-TCT-ND
2 | SAM4LC8BA | SAM4LC8BA | QFN-64-9MM | U6, U7 | SAM4L Microcontroller. 64QFN Package. 512 Flash. |  | N | ATSAM4LC8BA-MUR | Microchip Technology | Digikey | ATSAM4LC8BA-MURCT-ND
1 | SN74LVC1G125DBVR | SN74LVC1G125DBVR | SOT-23-5 | U8 | Single Bus Buffer Gate with 3-state output |  | N | SN74LVC1G125DBVR | Texas Instruments | Digikey | 296-11603-1-nd
1 | TS3USB30E | TS3USB30E | UQFN-10 | U9 | USB Mux with OE control and ESD |  | N | TS3USB30ERSWR | Texas Instruments | Digikey | 296-24684-1-ND
1 | TXS0108EVQFN20 | TXS0108EVQFN20 | R-PVQFN-N20 | U10 | TXS0108E 8-Bit Bi-directional Voltage Translator |  | N | TXS0108ERGYR | Texas Instruments | Digikey | 296-24806-1-ND
1 | TPS62086 | TPS62086 | RLT0007A | VR1 | Buck Switching Regulator IC Positive Fixed 3.3V 1 Output 3A 7-VFDFN |  | N | TPS62086RLTR | Texas Instruments | Digikey | 296-40831-1-ND
2 | 16MHz | FH1600015 | FHXXX | X1, X2 | Pericom Type FH 16 MHz 2.5 x 2.0 mm |  | N | FH1600015 | Diodes Incorporated | Digikey | FH1600015CT-ND
 |  |  |  |  |  |  | Note: Any part marked "Can Substitue" can be substituted for any equal size/value parts

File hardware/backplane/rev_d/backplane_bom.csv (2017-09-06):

# Bill of Materials
# Converted from {}
# Generated by bom_to_text.py
#
Qty | Part Reference | Do Not Insert | Can Substitue? | Value | Package | Description | Footprint | MPN | Manufacturer | DIGIKEY | DIGIKEY2 | MOUSER | NEWARK | NOTES
2 | C1, C2 |  | Y | 22pF, 5% tol | 0603_CAP | SMD Capacitor | SMD | CL10C220JB8NNNC | Samsung | 1276-1023-1-ND |  |  |  | Must be 5% or better
12 | C3, C4, C5, C6, C7, C8, C9, C10, C11, C12, C13, C14 |  | Y | 22pF | 0402_CAP | SMD Capacitor | SMD | GRM1555C1H220JA01D | Murata | 490-5868-1-ND
75 | C15, C16, C17, C18, C19, C20, C21, C22, C23, C24, C25, C26, C27, C28, C29, C30, C31, C32, C33, C34, C35, C36, C37, C38, C39, C40, C41, C42, C43, C44, C45, C46, C47, C48, C49, C50, C51, C52, C53, C54, C55, C56, C57, C58, C59, C60, C61, C62, C63, C64, C65, C66, C67, C68, C69, C70, C71, C72, C73, C74, C75, C76, C77, C78, C79, C80, C81, C82, C83, C84, C85, C86, C87, C88, C89 |  | Y | 100nF | 0603_CAP | SMD Capacitor | SMD | GRM188R71E104KA01D | Murata | 490-1524-1-ND
7 | C90, C91, C92, C93, C94, C95, C96 |  | Y | 4.7uF | 0603_CAP | SMD Capacitor | SMD | CL10B475KQ8NQNC | Samsung | 1276-2087-2-ND
6 | C97, C98, C99, C100, C101, C102 |  | Y | 150uF | C1206 | CAPACITOR, American symbol | SMD | GRM31CR60J157ME11L | Murata | 490-13969-1-ND
4 | D1, D2, D3, D4 |  | N | SN75240-TSSOP | TSSOP-8 | TVS Diodes [suggested for TI USB Hub] (2 array) | 8-TSSOP | SN75240PWR | Texas Instruments | 296-6596-1-ND
6 | J0, J1, J2, J5, J6, J7 |  | N | BACKPLANE_GENERIC_MODULE | BACKPLANE_MODULE_14PIN | Signpost generic module recepticle | PTH 14 pins | SFH11-PBPC-D07-ST-BK | Sullins Connector | S9195-ND
1 | J3 |  | N | BACKPLANE_CONTROLLER_MODULE | BACKPLANE_MODULE_20PIN_10PIN | Signpost controller recepticle | **2 Parts** PTH 20 pins + PTH 10 pins | SFH11-PBPC-D10-ST-BK and SFH11-PBPC-D05-ST-BK | Sullins Connector | S9197-ND | S9194-ND |  |  | J3 is two physical parts
1 | J4 |  | N | BACKPLANE_POWER_MODULE | BACKPLANE_MODULE_20PIN | Signpost power module recepticle | PTH 20 pins | SFH11-PBPC-D10-ST-BK | Sullins Connector | S9197-ND
2 | J8, J9 |  | Y | SCREW-TERMINAL_2_0.100 | CONN_BLOCK_2 | 2x 0.100 in screw terminal block | PTH 2 pins | 1725656 | Phoenix Contact | 277-1273-ND |  | 651-1725656 | 71C4107
18 | LED1001, LED1002, LED1003, LED1004, LED1005, LED1006, LED1007, LED1008, LED1009, LED1010, LED1011, LED1012, LED1013, LED1014, LED1015, LED1016, LED1017, LED1018 | X | - | DNP | LED-0603 | LED |  |  |  | DNP
12 | R1, R2, R3, R4, R5, R6, R7, R8, R9, R10, R11, R12 |  | Y | 27Ω | 0402_RES-HIGH_SPEED | Resistor | SMD | MCR01MRTJ270 | Rohm | RHM27CECT-ND
12 | R13, R14, R15, R16, R17, R18, R19, R20, R21, R22, R23, R24 |  | Y | 50Ω | 0603-RES | Resistor | SMD | MCR03ERTF49R9 | Rohm | RHM49.9CFCT-ND
3 | R25, R26, R27 |  | Y | 1.5kΩ | 0603-RES | Resistor | SMD | MCR03EZPFX1501 | Rohm | RHM1.50KHCT-ND
25 | R28, R29, R30, R31, R32, R33, R34, R35, R36, R37, R38, R39, R40, R41, R42, R43, R44, R45, R46, R47, R48, R49, R50, R51, R52 |  | Y | 10kΩ | 0603-RES | Resistor | SMD | MCR03EZPFX1002 | Rohm | RHM10.0KHCT-ND
14 | R53, R54, R55, R56, R57, R58, R59, R60, R61, R62, R63, R64, R65, R66 |  | Y | 15kΩ | 0603-RES | Resistor | SMD | MCR03ERTF1502 | Rohm | RHM15.0KCFCT-ND
18 | R67, R68, R69, R70, R71, R72, R73, R74, R75, R76, R77, R78, R79, R80, R81, R82, R83, R84 |  | Y | 10MΩ | 0603-RES | Resistor | SMD | ESR03EZPJ106 | Rohm | RHM10MDCT-ND
18 | R1001, R1002, R1003, R1004, R1005, R1006, R1007, R1008, R1009, R1010, R1011, R1012, R1013, R1014, R1015, R1016, R1017, R1018 | X | - | DNP | 0603-RES | Resistor |  |  |  | DNP
6 | S1, S2, S3, S4, S5, S6 |  | N | SIP3240X | TDFN4 | High power (2.4 A) high-side switch | 4-UFDFN Exposed Pad | SIP32402ADNP-T1GE4 | Vishay | SIP32402ADNP-T1GE4CT-ND
6 | S13, S14, S15, S16, S17, S18 |  | N | AP2401MP | MSOP-8EP | USB Power Switch | 8-TSSOP Exposed Pad | AP2401MP-13 | Diodes Incorporated | AP2401MP-13DICT-ND
6 | S7, S8, S9, S10, S11, S12 |  | N | NC7SZ157 | SC70-6 | MUX | 6-TSSOP | NC7SZ157P6X | Fairchild/ON Semiconductor | NC7SZ157P6XCT-ND
61 | TP1, TP2, TP3, TP4, TP5, TP6, TP7, TP8, TP9, TP10, TP11, TP12, TP13, TP14, TP15, TP16, TP17, TP18, TP19, TP20, TP21, TP22, TP23, TP24, TP25, TP26, TP27, TP28, TP29, TP30, TP31, TP32, TP33, TP34, TP35, TP36, TP37, TP38, TP39, TP40, TP41, TP42, TP43, TP1001, TP1002, TP1003, TP1004, TP1005, TP1006, TP1007, TP1008, TP1009, TP1010, TP1011, TP1012, TP1013, TP1014, TP1015, TP1016, TP1017, TP1018 |  | Y | TEST_POINT_0.040IN | TESTPOINT_0.040IN | 0.040in Test Point | PTH 1 pin | 5001 | Keystone Electronics | 5001K-ND
1 | U1 |  | N | TUSB2077A | LQFP-48 | Full Speed USB Hub - 7 Port | 48-LQFP | 296-37871-1-ND | Texas Instruments | 296-37871-1-ND
6 | U2, U3, U4, U5, U6, U7 |  | N | FXMA2102 | UMLP-8 | Dual Supply, 2-Bit Voltage Translator / Buffer / Repeater / Isolator for I2C | 8-UFQFN | FXMA2102UMX | Fairchild/ON Semiconductor | FXMA2102UMXCT-ND
6 | U20, U21, U22, U23, U24, U25 |  | N | TS3USB30E | UQFN-10 | USB Mux with OE control and ESD | 10-UFQFN | TS3USB30ERSWR | Texas Instruments | 296-24684-1-ND
7 | U26, U27, U28, U29, U30, U31, U32 |  | N | MCP23008QFN | QFN-20-4MM | GPIO Extender via I2C - 8 Pin | 20-VFQFN Exposed Pad | MCP23008-E/ML | Microchip | MCP23008-E/ML-ND
1 | U33 |  | Y | NCP301LSN30 | SOT23-5 | Power-on-reset. LSN30 -> Fixed 3V (for 90% of 3.3V) detector. Fixed ~100us power_on -> deassert reset. 301 -> Open Collector !RST. | 5-TSOP | NCP301LSN30T1G | ON Semiconductor | NCP301LSN30T1GOSCT-ND |  |  |  | Power-on-Reset with Open Collector output - 2.9-3.1V threshold okay
1 | U34 |  | N | M24C01WMN | SOIC-8 | 1K I2C™ Serial EEPROM | 8-SOIC | M24C01-WMN6TP | STMicroelectronics | 497-8631-1-ND
12 | U8, U9, U10, U11, U12, U13, U14, U15, U16, U17, U18, U19 |  | N | SN74LVC2T45 | VFSOP-8 | Bidirectional Buffer / Level Converter 2 Circuits | 8-VFSOP | SN74LVC2T45DCUR | Texas Instruments | 296-17014-1-ND
1 | Y1 |  | N | ABMM | ABMM | Low-Profile SMD crystal | SMD | ABMM-6.000MHZ-B2-T | Abracon LLC | 535-10156-1-ND
6 | JP1 JP2 JP3 JP4 JP5 JP6 | X |  |  |  | Fiducials
1 | SJ1 | X |  |  |  | Solder Jumper
 | Note: Any part marked "Can Substitue" can be substituted for any equal size/value parts

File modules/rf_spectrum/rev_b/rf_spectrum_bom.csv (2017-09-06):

Part | Value | Device | Package | Description | DIGIKEY | MANUFACTURER | MPN
A1 | U.FL-R-SMT | U.FL-R-SMT | U.FL_SMT | U.FL-R-SMT Antenna Connector | H122041-ND | Hirose | U.FL-R-SMT-1(01)
A2 | U.FL-R-SMT | U.FL-R-SMT | U.FL_SMT | U.FL-R-SMT Antenna Connector | H122041-ND | Hirose | U.FL-R-SMT-1(01)
A3 | U.FL-R-SMT | U.FL-R-SMT | U.FL_SMT | U.FL-R-SMT Antenna Connector | H122041-ND | Hirose | U.FL-R-SMT-1(01)
ADBG | MOLEX_73251-135X | MOLEX_73251-135X | SMA-J/PCB | SMA JACK SMT 50 OHM | WM9357-ND | Molex | 0732511350
C1 | 4.3pF | CAPACITOR0402_CAP | 0402_CAP | SMD Capacitor | 490-6243-1-ND | Murata | GRM1555C1H4R3BA01D
C2 | 4.3pF | CAPACITOR0402_CAP | 0402_CAP | SMD Capacitor | 490-6243-1-ND | Murata | GRM1555C1H4R3BA01D
C3 | 47pF | CAPACITOR0402_CAP | 0402_CAP | SMD Capacitor | 490-6241-1-ND | Murata | GRM1555C1H470FA01D
C4 | 47pF | CAPACITOR0402_CAP | 0402_CAP | SMD Capacitor | 490-6241-1-ND | Murata | GRM1555C1H470FA01D
C5 | 47pF | CAPACITOR0402_CAP | 0402_CAP | SMD Capacitor | 490-6241-1-ND | Murata | GRM1555C1H470FA01D
C6 | 220pF | CAPACITOR0402_CAP | 0402_CAP | SMD Capacitor | 490-1293-1-ND | Murata | GRM1555C1H221JA01D
C7 | 3.3nF | CAPACITOR0603_CAP | 0603_CAP | SMD Capacitor | 490-1503-1-ND | Murata | GRM188R71H332KA01D
C8 | 10nF | CAPACITOR0402_CAP | 0402_CAP | SMD Capacitor | 490-4516-1-ND | Murata | GRM155R71H103KA88D
C9 | 0.1uF | CAPACITOR0603_CAP | 0603_CAP | SMD Capacitor | 490-1532-1-ND | Murata | GRM188R71C104KA01D
C10 | 100nF | CAPACITOR0402_CAP | 0402_CAP | SMD Capacitor | 490-6328-1-ND | Murata | GRM155R71C104KA88J
C11 | 100nF | CAPACITOR0402_CAP | 0402_CAP | SMD Capacitor | 490-6328-1-ND | Murata | GRM155R71C104KA88J
C12 | 1uF | CAPACITOR0402_CAP | 0402_CAP | SMD Capacitor | 490-1320-1-ND | Murata | GRM155R60J105KE19D
C13 | 4.7uF | CAPACITOR0402_CAP | 0402_CAP | SMD Capacitor | 490-5915-1-ND | Murata | GRM155R60J475ME47D
C14 | 10uF | CAPACITOR0603_CAP | 0603_CAP | SMD Capacitor | 490-6405-1-ND | Murata | GRM188R60J106ME47J
C15 | 22uF | CAPACITOR0603_CAP | 0603_CAP | SMD Capacitor | 490-7611-1-ND | Murata | GRM188R60J226MEA0D
D1 | GREEN | LED0603 | LED-0603 | LED | 160-1446-1-ND | Lite-ON | LTST-C191KGKT
D2 | RED | LED0603 | LED-0603 | LED | 160-1447-1-ND | Lite-On | LTST-C191KRKT
J1 |  | M04PTH | 1X04 | Header 4 | WM8086-ND | Molex | 0901200764
J2 |  | M04PTH | 1X04 | Header 4 | WM8086-ND | Molex | 0901200764
J3 | SIGNPOST_DEBUG_HEADERSMT | SIGNPOST_DEBUG_HEADERSMT | SIGNPOST_DEBUG_HEADER_SMT | The 8 Pin signpost Debug Header | WM17450-ND | Molex | 0015912080
J4 | SIGNPOST_MODULE_HEADER | SIGNPOST_MODULE_HEADER | SIGNPOST_MODULE_HEADER | The 14 pin signpost module header | S9170-ND | Sullins Connector | SBH11-PBPC-D07-ST-BK
J5 | TC2030-JLINK-L | TC2030-JLINK-L | TC2030-IDC
L1 | 2.2uH | INDUCTORIHL | IHL-1212BZ-11 | A very specific inductor | 541-1322-1-ND | Vishay Dale | IHLP1212BZER2R2M11
Q1 | SI223DDS | SI223DDS | SOT23-3 | 6A SOT-23 P Fet | SI2333DDS-T1-GE3CT-ND | Vishay Siliconix | SI2333DDS-T1-GE3
R1 | DNP - 0 | RESISTOR0402_RES | 0402_RES | Resistor | 311-0.0JRCT-ND | Yageo | RC0402JR-070RL
R2 | 1k | RESISTOR0402_RES | 0402_RES | Resistor | 311-1.0KJRCT-ND | Yageo | RC0402JR-071KL
R3 | 1k | RESISTOR0402_RES | 0402_RES | Resistor | 311-1.0KJRCT-ND | Yageo | RC0402JR-071KL
R4 | 1k | RESISTOR0402_RES | 0402_RES | Resistor | 311-1.0KJRCT-ND | Yageo | RC0402JR-071KL
R5 | 10k | RESISTOR0402_RES | 0402_RES | Resistor | 311-1.0KJRCT-ND | Yageo | RC0402JR-071KL
R6 | 100k | RESISTOR0402_RES | 0402_RES | Resistor | 311-100KLRCT-ND | Yageo | RC0402FR-07100KL
R7 | 100k | RESISTOR0402_RES | 0402_RES | Resistor | 311-100KLRCT-ND | Yageo | RC0402FR-07100KL
R8 | 100k | RESISTOR0402_RES | 0402_RES | Resistor | 311-100KLRCT-ND | Yageo | RC0402FR-07100KL
R9 | 100k | RESISTOR0603_RES | 0603-RES | Resistor | 311-100KGRCT-ND | Yageo | RC0603JR-07100KL
R10 | 240k | RESISTOR0603_RES | 0603-RES | Resistor | 311-240KGRCT-ND | Yageo | RC0603JR-07240KL
R11 | 750k | RESISTOR0603_RES | 0603-RES | Resistor | 311-750KGRCT-ND | Yageo | 311-750KGRCT-ND
S1 | B3U-1000P | B3U-1000P | B3U-1000P | Switch | SW1020CT-ND | Omron | B3U-1000P
U1 | MWSUB3G | MWSUB3G | MWSUB3G | An RF Spectrum analyzer module |  | RFExplorer | MWSUB3G
U2 | SKY13317 | SKY13317 | XDFN-8 | 20-6000 MHZ SP3T RF Switch | 863-1056-1-ND | Skworks Solutions | SKY13317-373LF
U3 | STM32L432KC | STM32L432KC | UQFN-32 | Simple STM32 Cortex M4. Features include a fast 32bit timer, 2 spi, 2 i2c, 2usart, hardware aes and more. | 497-16578-ND | STMicroelectronics | STM32L432KCU6
U4 | TLV62130 | TLV62130 | TQFN-16/3MM | High Efficient 3A switching step-down regulator. 1V-5V out, 4V-17V in. | 296-35978-1-ND | Texas Instruments | TLV62130RGTR
X1 | ABS05-32.768KHZ-T | ABS05-32.768KHZ-T | ABS05 | 32.768kHz Crystal | 535-11899-1-ND | Abracon | ABS05-32.768KHZ-T

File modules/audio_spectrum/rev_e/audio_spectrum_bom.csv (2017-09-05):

Part | Value | Device | Package | Description | DIGIKEY | MANUFACTURER | MOUSER | MPN | NEWARK
!CS | TEST_POINT_0.040IN | TEST_POINT_0.040IN | TESTPOINT_0.040IN | 0.040in Test Point | 5001K-ND
C1 | 8pF | CAPACITOR0402_CAP | 0402_CAP | SMD Capacitor | 490-8230-1-ND | Murata |  | GRM1555C1H8R0BA01D
C2 | 8pF | CAPACITOR0402_CAP | 0402_CAP | SMD Capacitor | 490-8230-1-ND | Murata |  | GRM1555C1H8R0BA01D
C3 | 33pF | CAPACITOR0603_CAP | 0603_CAP | SMD Capacitor | 490-1415-1-ND | Murata |  | GRM1885C1H330JA01D
C4 | 33pF | CAPACITOR0603_CAP | 0603_CAP | SMD Capacitor | 490-1415-1-ND | Murata |  | GRM1885C1H330JA01D
C5 | 100pF | CAPACITOR0603_CAP | 0603_CAP | SMD Capacitor | 490-1427-1-ND | Murata |  | GRM1885C1H101JA01D
C6 | 100pF | CAPACITOR0603_CAP | 0603_CAP | SMD Capacitor | 490-1427-1-ND | Murata |  | GRM1885C1H101JA01D
C7 | 360pF | CAPACITOR0603_CAP | 0603_CAP | SMD Capacitor | 490-1440-1-ND | Murata |  | GRM1885C1H361JA01D
C8 | 360pF | CAPACITOR0603_CAP | 0603_CAP | SMD Capacitor | 490-1440-1-ND | Murata |  | GRM1885C1H361JA01D
C9 | 1nF | CAPACITOR0603_CAP | 0603_CAP | SMD Capacitor | 490-1494-1-ND | Murata |  | GRM188R71H102KA01D
C10 | 1nF | CAPACITOR0603_CAP | 0603_CAP | SMD Capacitor | 490-1494-1-ND | Murata |  | GRM188R71H102KA01D
C11 | 1nF | CAPACITOR0603_CAP | 0603_CAP | SMD Capacitor | 490-1494-1-ND | Murata |  | GRM188R71H102KA01D
C12 | 1.2nF | CAPACITOR0603_CAP | 0603_CAP | SMD Capacitor | 490-13298-1-ND | Murata |  | GCM1885C1H122JA16D
C13 | 1.2nF | CAPACITOR0603_CAP | 0603_CAP | SMD Capacitor | 490-13298-1-ND | Murata |  | GCM1885C1H122JA16D
C14 | 3.3nF | CAPACITOR0603_CAP | 0603_CAP | SMD Capacitor | 490-1503-1-ND | Murata |  | GRM188R71H332KA01D
C15 | 0.1uF | CAPACITOR0603_CAP | 0603_CAP | SMD Capacitor | 490-1532-1-ND | Murata |  | GRM188R71C104KA01D
C16 | 0.1uF | CAPACITOR0603_CAP | 0603_CAP | SMD Capacitor | 490-1532-1-ND | Murata |  | GRM188R71C104KA01D
C17 | 0.1uF | CAPACITOR0603_CAP | 0603_CAP | SMD Capacitor | 490-1532-1-ND | Murata |  | GRM188R71C104KA01D
C18 | 0.1uF | CAPACITOR0603_CAP | 0603_CAP | SMD Capacitor | 490-1532-1-ND | Murata |  | GRM188R71C104KA01D
C19 | 0.1uF | CAPACITOR0603_CAP | 0603_CAP | SMD Capacitor | 490-1532-1-ND | Murata |  | GRM188R71C104KA01D
C20 | 100nF | CAPACITOR0402_CAP | 0402_CAP | SMD Capacitor | 490-10777-1-ND | Murata |  | GRM155R71A104JA01D
C21 | 100nF | CAPACITOR0603_CAP | 0603_CAP | SMD Capacitor | 490-1532-1-ND | Murata |  | GRM188R71C104KA01D
C22 | 100nF | CAPACITOR0603_CAP | 0603_CAP | SMD Capacitor | 490-1532-1-ND | Murata |  | GRM188R71C104KA01D
C23 | 100nF | CAPACITOR0603_CAP | 0603_CAP | SMD Capacitor | 490-1532-1-ND | Murata |  | GRM188R71C104KA01D
C24 | 100nF | CAPACITOR0603_CAP | 0603_CAP | SMD Capacitor | 490-1532-1-ND | Murata |  | GRM188R71C104KA01D
C25 | 1uF | CAPACITOR0603_CAP | 0603_CAP | SMD Capacitor | 490-1536-1-ND | Murata |  | GRM188R61C105KA93D
C26 | 1uF | CAPACITOR0603_CAP | 0603_CAP | SMD Capacitor | 490-1536-1-ND | Murata |  | GRM188R61C105KA93D
C27 | 1uF | CAPACITOR0603_CAP | 0603_CAP | SMD Capacitor | 490-1536-1-ND | Murata |  | GRM188R61C105KA93D
C28 | 1uF | CAPACITOR0603_CAP | 0603_CAP | SMD Capacitor | 490-1536-1-ND | Murata |  | GRM188R61C105KA93D
C29 | 1uF | CAPACITOR0603_CAP | 0603_CAP | SMD Capacitor | 490-1536-1-ND | Murata |  | GRM188R61C105KA93D
C30 | 4.7uF | CAPACITOR0603_CAP | 0603_CAP | SMD Capacitor | 490-3297-1-ND | Murata |  | GRM188R60J475KE19D
C31 | 4.7uF | CAPACITOR0603_CAP | 0603_CAP | SMD Capacitor | 490-3297-1-ND | Murata |  | GRM188R60J475KE19D
C32 | 6.8uF | CAPACITOR0603_CAP | 0603_CAP | SMD Capacitor | 445-7484-1-ND | TDk |  | C1608X5R1A685K080AC
C33 | 10uF | CAPACITOR0603_CAP | 0603_CAP | SMD Capacitor | 490-6405-1-ND | Murata |  | GRM188R60J106ME47J
C34 | 22uF | CAPACITOR0603_CAP | 0603_CAP | SMD Capacitor | 490-13241-1-ND | Murata |  | GRM186R60J226ME15D
FB1 | 1.5k | FERRITE_BEAD0402 | 0402_CAP |  | 490-5216-1-ND | Murata |  | BLM18HE152SN1D
J1 | AUDIO-JACK-VERTICAL | AUDIO-JACK-VERTICAL | AUDIO-JACK-VERTICAL | A vertical audio jack |  | Kycon | 806-STX-3790-5N | STX-3790-5N
J2 | SIGNPOST_DEBUG_HEADER | SIGNPOST_DEBUG_HEADER | SIGNPOST_DEBUG_HEADER | The 8 Pin signpost Debug Header | S2221EC-04-ND | Sullins Connector |  | PRPC004DFBN-RC
J3 | SIGNPOST_MODULE_HEADER | SIGNPOST_MODULE_HEADER | SIGNPOST_MODULE_HEADER | The 14 pin signpost module header | S9170-ND | Sullins Connector |  | SBH11-PBPC-D07-ST-BK
J4 | TC2030-JLINK-L | TC2030-JLINK-L | TC2030-IDC
L1 | 2.2uH | INDUCTORIHL | IHL-1212BZ-11 | A very specific inductor | 541-1322-1-ND | Vishay Dale |  | IHLP1212BZER2R2M11
L2 | 22uH | LHQ3NP | 1212 | LHQ3NP Inductor | 490-5350-1-ND | Murata |  | LQH3NPN220MJ0L
LED1 | LED0603 | LED0603 | LED-0603 | LED | 160-1446-1-ND | Lite-On |  | LTST-C191KGKT
LED2 | LED0603 | LED0603 | LED-0603 | LED | 160-1447-1-ND | Lite-On |  | LTST-C191KRKT
LED3 | LED0603 | LED0603 | LED-0603 | LED | 160-1446-1-ND | Lite-On |  | LTST-C191KGKT
LED4 | LED0603 | LED0603 | LED-0603 | LED | 160-1447-1-ND | Lite-On |  | LTST-C191KRKT
P1 | 4k-200k | POTTC33X | TC33X-2 | Potentiometer | TC33X-2-204ECT-ND
P2 | 4k-200k | POTTC33X | TC33X-2 | Potentiometer | TC33X-2-204ECT-ND
Q1 | NX3008PBK | NX3008PBK | SOT23-3 | MOSFET - P Channel | 568-10499-1-ND | Nexperia | 771-NX3008PBK,215 | NX3008PBK,215 | 74T4665
Q2 | NX3008PBK | NX3008PBK | SOT23-3 | MOSFET - P Channel | 568-10499-1-ND | Nexperia | 771-NX3008PBK,215 | NX3008PBK,215 | 74T4665
R1 | DNP - 0 | RESISTOR0603_RES | 0603-RES | Resistor | 1276-3431-1-ND | Samsung |  | RC1005F103CS
R2 | 1k | RESISTOR0603_RES | 0603-RES | Resistor | RHM1.0KDCT-N | Murata |  | ESR03EZPJ102
R3 | 1k | RESISTOR0603_RES | 0603-RES | Resistor | RHM1.0KDCT-ND | Murata |  | ESR03EZPJ102
R4 | 1k | RESISTOR0603_RES | 0603-RES | Resistor | RHM1.0KDCT-ND | Murata |  | ESR03EZPJ102
R5 | 1k | RESISTOR0603_RES | 0603-RES | Resistor | RHM1.0KDCT-ND | Murata |  | ESR03EZPJ102
R6 | 1.5k | RESISTOR0603_RES | 0603-RES | Resistor | RHM1.5KCGCT-ND | Rohm |  | MCR03ERTJ152
R7 | 1.5k | RESISTOR0603_RES | 0603-RES | Resistor | RHM1.5KCGCT-ND | Rohm |  | MCR03ERTJ152
R8 | 1.5k | RESISTOR0603_RES | 0603-RES | Resistor | RHM1.5KCGCT-ND | Rohm |  | MCR03ERTJ152
R9 | 1.5k | RESISTOR0603_RES | 0603-RES | Resistor | RHM1.5KCGCT-ND | Rohm |  | MCR03ERTJ152
R10 | 10k | RESISTOR0603_RES | 0603-RES | Resistor | RHM10.0KHCT-ND | Rohm |  | MCR03EZPFX1002
R11 | 10k | RESISTOR0603_RES | 0603-RES | Resistor | RHM10.0KHCT-ND | Rohm |  | MCR03EZPFX1002
R12 | 10k | RESISTOR0603_RES | 0603-RES | Resistor | RHM10.0KHCT-ND | Rohm |  | MCR03EZPFX1002
R13 | 10k | RESISTOR0603_RES | 0603-RES | Resistor | RHM10.0KHCT-ND | Rohm |  | MCR03EZPFX1002
R14 | 10k | RESISTOR0603_RES | 0603-RES | Resistor | RHM10.0KHCT-ND | Rohm |  | MCR03EZPFX1002
R15 | 19k | RESISTOR0603_RES | 0603-RES | Resistor | RHM19.1KCFCT-ND | Rohm |  | MCR03ERTF1912
R16 | 19k | RESISTOR0603_RES | 0603-RES | Resistor | RHM19.1KCFCT-ND | Rohm |  | MCR03ERTF1912
R17 | 20k | RESISTOR0603_RES | 0603-RES | Resistor | RHM20KCGCT-ND | Rohm |  | MCR03ERTJ203
R18 | 20k | RESISTOR0603_RES | 0603-RES | Resistor | RHM20KCGCT-ND | Rohm |  | MCR03ERTJ203
R19 | 20k | RESISTOR0603_RES | 0603-RES | Resistor | RHM20KCGCT-ND | Rohm |  | MCR03ERTJ203
R20 | 20k | RESISTOR0603_RES | 0603-RES | Resistor | RHM20KCGCT-ND | Rohm |  | MCR03ERTJ203
R21 | 20k | RESISTOR0603_RES | 0603-RES | Resistor | RHM20KCGCT-ND | Rohm |  | MCR03ERTJ203
R22 | 20k | RESISTOR0603_RES | 0603-RES | Resistor | RHM20KCGCT-ND | Rohm |  | MCR03ERTJ203
R23 | 20k | RESISTOR0603_RES | 0603-RES | Resistor | RHM20KCGCT-ND | Rohm |  | MCR03ERTJ203
R24 | 20k | RESISTOR0603_RES | 0603-RES | Resistor | RHM20KCGCT-ND | Rohm |  | MCR03ERTJ203
R25 | 60k | RESISTOR0603_RES | 0603-RES | Resistor | RHM60.4KCLCT-ND | Rohm |  | MCR03ERTF6042
R26 | 100k | RESISTOR0603_RES | 0603-RES | Resistor | RHM100KCGCT-ND | Rohm |  | MCR03ERTJ104
R27 | 100k | RESISTOR0603_RES | 0603-RES | Resistor | RHM100KCGCT-ND | Rohm |  | MCR03ERTJ104
R28 | 100k | RESISTOR0603_RES | 0603-RES | Resistor | RHM100KCGCT-ND | Rohm |  | MCR03ERTJ104
R29 | 100k | RESISTOR0603_RES | 0603-RES | Resistor | RHM100KCGCT-ND | Rohm |  | MCR03ERTJ104
R30 | 100k | RESISTOR0603_RES | 0603-RES | Resistor | RHM100KCGCT-ND | Rohm |  | MCR03ERTJ104
R31 | 100k | RESISTOR0603_RES | 0603-RES | Resistor | RHM100KCGCT-ND | Rohm |  | MCR03ERTJ104
R32 | 200k | RESISTOR0603_RES | 0603-RES | Resistor | RHM200KCFCT-ND | Rohm |  | MCR03ERTF2003
R33 | 200k | RESISTOR0603_RES | 0603-RES | Resistor | RHM200KCFCT-ND | Rohm |  | MCR03ERTF2003
R34 | 240k | RESISTOR0603_RES | 0603-RES | Resistor | RHM240KCFCT-ND | Rohm |  | RHM240KCFCT-ND
R35 | 750k | RESISTOR0603_RES | 0603-RES | Resistor | RHM750KCFCT-ND | Rohm |  | MCR03ERTF7503
S1 | B3U-1000P | B3U-1000P | B3U-1000P | Switch | SW1020CT-ND | Omron |  | B3U-1000P
SCLK | TEST_POINT_0.040IN | TEST_POINT_0.040IN | TESTPOINT_0.040IN | 0.040in Test Point | 5001K-ND
SI | TEST_POINT_0.040IN | TEST_POINT_0.040IN | TESTPOINT_0.040IN | 0.040in Test Point | 5001K-ND
SO | TEST_POINT_0.040IN | TEST_POINT_0.040IN | TESTPOINT_0.040IN | 0.040in Test Point | 5001K-ND
TP1 | TEST_POINT_0.040IN | TEST_POINT_0.040IN | TESTPOINT_0.040IN | 0.040in Test Point | 5001K-ND
TP2 | TEST_POINT_0.040IN | TEST_POINT_0.040IN | TESTPOINT_0.040IN | 0.040in Test Point | 5001K-ND
TP3 | TEST_POINT_0.040IN | TEST_POINT_0.040IN | TESTPOINT_0.040IN | 0.040in Test Point | 5001K-ND
TP4 | TEST_POINT_0.040IN | TEST_POINT_0.040IN | TESTPOINT_0.040IN | 0.040in Test Point | 5001K-ND
TP5 | TEST_POINT_0.040IN | TEST_POINT_0.040IN | TESTPOINT_0.040IN | 0.040in Test Point | 5001K-ND
TP6 | TEST_POINT_0.040IN | TEST_POINT_0.040IN | TESTPOINT_0.040IN | 0.040in Test Point | 5001K-ND
TP7 | TEST_POINT_0.040IN | TEST_POINT_0.040IN | TESTPOINT_0.040IN | 0.040in Test Point | 5001K-ND
TP8 | TEST_POINT_0.040IN | TEST_POINT_0.040IN | TESTPOINT_0.040IN | 0.040in Test Point | 5001K-ND
TP9 | TEST_POINT_0.040IN | TEST_POINT_0.040IN | TESTPOINT_0.040IN | 0.040in Test Point | 5001K-ND
TP10 | TEST_POINT_0.040IN | TEST_POINT_0.040IN | TESTPOINT_0.040IN | 0.040in Test Point | 5001K-ND
U1 | AT45DB641EUDFN | AT45DB641EUDFN | UDFN-8-5MMX6MM | 64 Mbit flash memory | AT45DB641E-MHN-TCT-ND | Adesto |  | AT45DB641E-MHN-T
U2 | MP23AB02B | MP23AB02B | MP23AB02B | A pretty normal mems microphone | 497-14947-1-ND | STMicroelectronics |  | MP23AB02BTR
U3 | MSGEQ7 | MSGEQ7 | DIP-8 | A CMOS spectrum analyzer | 1568-1335-ND | Sparkfun Electronics |  | COM-10468
U4 | MSGEQ7 | MSGEQ7 | DIP-8 | A CMOS spectrum analyzer | 1568-1335-ND | Sparkfun Electronics |  | COM-10468
U5 | OPA344 | OPA344 | SOT23-5 | Single gate rail-to-rail output op-amp. Inputs extend 300mV past rails. | OPA344NACT-ND | Texax Instruments |  | OPA344NA/250
U6 | OPA344 | OPA344 | SOT23-5 | Single gate rail-to-rail output op-amp. Inputs extend 300mV past rails. | OPA344NACT-ND | Texax Instruments |  | OPA344NA/250
U7 | OPA344 | OPA344 | SOT23-5 | Single gate rail-to-rail output op-amp. Inputs extend 300mV past rails. | OPA344NACT-ND | Texax Instruments |  | OPA344NA/250
U8 | OPA344 | OPA344 | SOT23-5 | Single gate rail-to-rail output op-amp. Inputs extend 300mV past rails. | OPA344NACT-ND | Texax Instruments |  | OPA344NA/250
U9 | SAM4LC8BA | SAM4LC8BA | QFN-64-9MM | SAM4L Microcontroller. 64QFN Package. 512 Flash. | ATSAM4LC8BA-MURCT-ND | Microchip |  | ATSAM4LC8BA-MUR
U10 | TLV62130 | TLV62130 | TQFN-16/3MM | High Efficient 3A switching step-down regulator. 1V-5V out, 4V-17V in. | 296-35978-1-ND | Texas Instruments |  | TLV62130RGTR
X1 | 16MHz | FH1600015 | FHXXX | Pericom Type FH 16 MHz 2.5 x 2.0 mm | FH1600015CT-ND | Diodes Incorporated |  | FH1600015

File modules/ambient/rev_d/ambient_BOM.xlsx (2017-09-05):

Ref | Do Not Populate | Can Substitue? | Qty | Val | Value | Footprint | Vendor 1 | Vendor 1 Part Number | MPN
C3 C5 C9 C6 C4 C16 C14 C13 C17 |  | Y | 9 | 0.1uF | C_0.1u_0402_10V_10%_JB | Capacitors_SMD:C_0402 | Digikey | 445-10894-1-ND | C1005JB1A104K050BA
C10 C11 |  | Y | 2 | 8pF | GENERIC_C_0402 | Capacitors_SMD:C_0402 | Digikey | 490-8230-1-ND | GRM1555C1H8R0BA01D
C2 |  | Y | 1 | 22uF | GENERIC_C_0805 | Capacitors_SMD:C_0805_HandSoldering | Digikey | 490-1719-1-ND | GRM21BR60J226ME39L
C1 |  | Y | 1 | 10uF | GENERIC_C_0805 | Capacitors_SMD:C_0805_HandSoldering | Digikey | 490-8316-1-ND | GRM21BR71A106ME51L
C7 |  | Y | 1 | 10nF | GENERIC_C_0402 | Capacitors_SMD:C_0402 | Digikey | 490-5922-6-ND | GRM1555C1H101JA01D
C8 |  | Y | 1 | 6.8uF | GENERIC_C_0603 | Capacitors_SMD:C_0603 | Digikey | 445-7484-1-ND | C1608X5R1A685K080AC
C12 |  | Y | 1 | 10uF | C_10u_0603_10V_10%_JB | Capacitors_SMD:C_0603 | Digikey | 445-11201-1-ND | C1608JB1A106K080AC
D1 D2 D3 |  | Y | 3 | Blue | LED | Diodes_SMD:D_0603 | Digikey | 475-2816-1-ND | LB Q39G-L2OO-35-1
L2 |  | Y | 1 |  | 1.5k Ohm | Capacitors_SMD:C_0603_HandSoldering | Digikey | 490-5216-1-ND | BLM18HE152SN1D
L3 |  | N | 1 |  | 22uH | lab11-passives:1212 | Digikey | 490-5350-1-ND | LQH3NPN220MJ0L
L1 |  | N | 1 |  | .47 uH | lab11-passives:DFE322512C | Digikey | 490-10596-1-ND | 1277AS-H-R47M=P2
P3 |  | Y | 1 |  | CONN_01X03 | Connect:PINHEAD1-3 | Digikey | 732-5316-ND | 61300311121
P6 |  | Y | 1 |  | CONN_01X06 | Connect:PINHEAD1-6 | Digikey | 732-5319-ND | 61300611121
P1 |  | Y | 1 |  | SIGNPOST_MODULE_GENERIC | lab11-connectors:SIGNPOST_MODULE_GENERIC | Digikey | S9170-ND | SBH11-PBPC-D07-ST-BK
P4 | X |  | 1 |  | JLINK-TC | lab11-connectors:TC2030-IDC | - | - | -
P2 |  | Y | 1 |  | CONN_02X04 | lab11-connectors:PINHEAD2-4 | Digikey | 732-5395-ND | 61200821621
R9 R6 R5 |  | Y | 3 | 10k | R_10k_0402_1% | 100ppm/c | Digikey | RHM10.0KCDCT-ND | MCR01MRTF1002
R1 R2 R3 R16 R17 |  | Y | 5 | 100K | R_100K_0402_0.5% | 25ppm/c | Digikey | RR05P100KDCT-ND | RR0510P-104-D
R4 |  | Y | 1 | 10 | GENERIC_R_0402 | Resistors_SMD:R_0402 | Digikey | P10JCT-ND | ERJ-2GEJ100X
R11 R12 R13 |  | Y | 3 | 1K | R_1K_0402_1% | 100ppm/c | Digikey | P17224CT-ND | ERJ-PA2F1001X
R10 | X |  | 1 |  | R_0_0402_.1W | Resistors_SMD:R_0402 | Digikey | P0.0JCT-ND | ERJ-2GE0R00X
R7 R8 |  | Y | 2 | 39 | R_39_0402_1% | 100ppm/c | Digikey | P39.0LCT-ND | ERJ-2RKF39R0X
SW1 |  | Y | 1 |  | BSU-1000P | lab11-switches:B3U-1000p | Digikey | SW1020CT-ND | B3U-1000P
U2 |  | N | 1 |  | SAM4LC8A | Housings_DFN_QFN:QFN-48-1EP_7x7mm_Pitch0.5mm | Digikey | 1611-ATSAM4LC8AA-MU-ND | ATSAM4LC8AA-MU
U1 |  | N | 1 |  | TPS62086 | regulators:RLT0007A | Digikey | 296-40831-1-ND | TPS62086RLTR
U4 |  | N | 1 |  | ISL29035 | lab11-ic:L6_1.5x1.6mm | Digikey | ISL29035IROZ-T7CT-ND | ISL29035IROZ-T7
U5 |  | N | 1 |  | Si7021 | lab11-ic:DFN_3x3mm_1mm | Digikey | 336-3140-5-ND | SI7021-A20-GM
U3 |  | N | 1 |  | LPS25HB | lab11-ic:HLGA-10L_2.5x2.5mm | Digikey | 497-15070-1-ND | LPS25HBTR
U7 |  | N | 1 |  | EKMB1101111 | lab11-ic:EKMB1101111 | Digikey | 255-3065-ND | EKMB1101111
Y1 |  | N | 1 |  | FH1600015 | crystals:FHXXX | Digikey | FH1600015CT-ND | FH1600015
BOM made with KICAD_BOM_WIZARD (https://github.com/HashDefineElectronics/KiCad_BOM_Wizard.git)
Generated Monday | September 04 |  |  |  | 2017 'PMt' 04:30:08 PM

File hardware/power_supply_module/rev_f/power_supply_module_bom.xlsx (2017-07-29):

Qty | Value | Device | Package | Parts | Description | DESCRIPTION | DIGIKEY | MANUFACTURER | MOUSER | MPN
1 |  | DIODE_SCHOTTKYSOD323 | SOD323 | D3 |  | DIODE SCHOTTKY 40V 200MA SOD323 | CMDSH2-4L CT-ND | Central Semiconductor |  | CMDSH2-4L TR
1 | 0.010 Ω | RESISTOR0805_RES | 0805_RES | R1 | Resistor | RES SMD 0.01 OHM 1% 1/2W 0805 | WSLPB-.01CT-ND | Vishay Dale |  | WSLP0805R0100FEB
8 | 0.017 Ω | RESISTOR0805_RES | 0805_RES | R2, R3, R4, R5, R6, R7, R8, R9 | Resistor | RES SMD 0.017 OHM 1% 1/2W 0805 | WSLPB-.017CT-ND | Vishay Dale |  | WSLP0805R0170FEB
2 | 0.05 Ω | RESISTOR0805_RES | 0805_RES | R10, R11 | Resistor | RES SMD 0.05 OHM 1% 1/2W 0805 | WSLPB-.05CT-ND | Vishay Dale |  | WSLP0805R0500FEB
23 | 0.1 uF | CAPACITOR0402_CAP | 0402_CAP | C1, C2, C3, C4, C5, C6, C7, C8, C9, C10, C11, C12, C13, C14, C15, C16, C17, C18, C19, C20, C21, C22, C23 | SMD Capacitor | CAP CER 0.1UF 25V X5R 0402 | 490-5920-1-ND | Murata |  | GRM155R61E104KA87D
3 | 0.47 uF | CAPACITOR0402_CAP | 0402_CAP | C24, C25, C26 | SMD Capacitor | CAP CER 0.47UF 6.3V X5R 0402 | 490-3266-1-ND | Murata |  | GRM155R60J474KE19D
1 | 0.82 uF | CAPACITOR0402_CAP | 0402_CAP | C27 | SMD Capacitor | CAP CER 0.82UF 6.3V X6S 0402 | 490-10440-1-ND | Murata |  | GRM155C80J824KE15D
2 | 1 MΩ | RESISTOR0402_RES | 0402_RES | R15, R16 | Resistor | RES SMD 1M OHM 1% 1/10W 0402 | P1.00MLCT-ND | Panasonic |  | ERJ-2RKF1004X
3 | 1 kΩ | RESISTOR0402_RES | 0402_RES | R12, R13, R66 | Resistor | RES SMD 1K OHM 5% 1/10W 0402 | P1.0KJCT-ND | Panasonic |  | ERJ-2GEJ102X
1 | 1 uF | CAPACITOR0603_CAP | 0603_CAP | C28 | SMD Capacitor | CAP CER 1UF 10V X5R 0603 | 490-1543-1-ND | Murata |  | GRM188R61A105KA61D
7 | 10 uF | CAPACITOR0805_CAP | 0805_CAP | C34, C35, C36, C37, C38, C39, C40 | SMD Capacitor | CAP CER 10UF 25V 10% X5R 0805 | 490-5523-1-ND | Murata |  | GRM21BR61E106KA73L
5 | 100 kΩ | RESISTOR0402_RES | 0402_RES | R45, R46, R47, R48, R49 | Resistor | RES SMD 100K OHM 5% 1/10W 0402 | P100KJCT-ND | Panasonic |  | ERJ-2GEJ104X
4 | 130 kΩ | RESISTOR0402_RES | 0402_RES | R50, R51, R52, R53 | Resistor | RES SMD 130K OHM 1% 1/10W 0402 | P130KLCT-ND | Panasonic |  | ERJ-2RKF1303X
3 | 150 Ω | RESISTOR0402_RES | 0402_RES | R54, R55, R70 | Resistor | RES SMD 150 OHM 1% 1/10W 0402 | P150LCT-ND | Panasonic |  | ERJ-2RKF1500X
27 | 2 kΩ | RESISTOR0402_RES | 0402_RES | R17, R18, R19, R20, R21, R22, R23, R24, R25, R26, R27, R28, R29, R30, R31, R32, R33, R34, R35, R36, R37, R38, R39, R40, R41, R42, R43 | Resistor | RES SMD 2K OHM 1% 1/10W 0402 | P2.00KLCT-ND | Panasonic |  | ERJ-2RKF2001X
5 | 2.2 uH | INDUCTORIHL | IHL-1212BZ-11 | L1, L2, L3, L4, L5 | A very specific inductor |  | 541-1322-1-ND | Vishay Dale |  | IHLP1212BZER2R2M11
10 | 22 uF | CAPACITOR0603_CAP | 0603_CAP | C41, C42, C43, C44, C45, C46, C47, C48, C49, C50 | SMD Capacitor | CAP CER 22UF 6.3V X5R 0603 | 1276-1193-1-ND | Samsung |  | CL10A226MQ8NRNC
1 | 23.2 kΩ | RESISTOR0805_RES | 0805_RES | R44 | Resistor | RES SMD 23.2K OHM 0.1% 1/8W 0805 | P23.2KDACT-ND | Panasonic |  | ERA6AEB2322V
1 | 240 kΩ | RESISTOR0402_RES | 0402_RES | R56 | Resistor | RES SMD 240K OHM 1% 1/10W 0402 | P240KLCT-ND | Panasonic |  | ERJ-2RKF2403X
5 | 3.3 nF | CAPACITOR0402_CAP | 0402_CAP | C29, C30, C31, C32, C33 | SMD Capacitor | CAP CER 3300PF 50V 10% X7R 0402 | 490-3248-1-ND | Murata |  | GRM155R71H332KA01D
1 | 3.3V | TILM34803.3V | SOT-23 | U28 | Very simple LDO 100ma 3v3 | IC REG LDO 3.3V 50MA SOT23-3 | ZMR330FCT-ND | Diodes Inc. |  | ZMR330FTA
1 | 301 kΩ | RESISTOR0805_RES | 0805_RES | R57 | Resistor | RES SMD 301K OHM 0.1% 1/8W 0805 | P301KDACT-ND | Panasonic |  | ERA-6AEB3013V
1 | 340 kΩ | RESISTOR0805_RES | 0805_RES | R58 | Resistor | RES SMD 340K OHM 0.1% 1/8W 0805 | P340KDACT-ND | Panasonic |  | ERA-6AEB3403V
1 | 6.8uH | INDUCTORIHL2525CZ | IHL-2525CZ | L6 | A very specific inductor | FIXED IND 6.8UH 5.5A 46.8 MOHM | 541-2582-1-ND | Vishay Dale |  | IHLP2525CZER6R8M11
4 | 680 kΩ | RESISTOR0402_RES | 0402_RES | R59, R60, R61, R62 | Resistor | RES SMD 680K OHM 1% 1/10W 0402 | P680KLCT-ND | Panasonic |  | ERJ-2RKF6803X
1 | 750 kΩ | RESISTOR0402_RES | 0402_RES | R63 | Resistor | RES SMD 750K OHM 5% 1/10W 0402 | P750KJCT-ND | Panasonic |  | ERJ-2GEJ754X
1 | 953 kΩ | RESISTOR0805_RES | 0805_RES | R64 | Resistor | RES SMD 953K OHM 0.1% 1/8W 0805 | P953KDACT-ND | Panasonic |  | ERA-6AEB9533V
5 | AP22814 | AP22814 | U-DFN2020-6 | U20, U21, U22, U23, U24 | SINGLE CHANNEL POWER DISTRIBUTION LOAD SWITCH |  | AP22814ASN-7DICT-ND | Diodes Inc. |  | AP22814ASN-7
1 | DIODE_SCHOTTKYSOT-23F | DIODE_SCHOTTKYSOT-23F | SOT-23F | D1 |  | DIODE SCHOTTKY 40V 1.75A SOT23F | CMPSH1-4 CT-ND | Central Semiconductor |  | CMPSH1-4 TR
1 | DIODE_ZENERSOT323 | DIODE_ZENERSOT323 | SOD323 | D2 |  | DIODE ZENER 3.6V 400MW SOD323 | 1727-5151-1-ND | NXP Semiconductors |  | PDZ3.6B,115
1 | ESDR0502N | ESDR0502N | UDFN-6 | U19 |  |  | ESDR0502NMUTBGOSCT-ND | ON Semiconductor |  | ESDR0502NMUTBG
1 | LM234 | LM234 | SOIC-8 | U17 | 3-terminal temperature sensor |  | 497-1549-1-ND | STMicroelectronics |  | LM234DT
1 | LT3652 | LT3652 | DFN-12/3MM | U16 | Solar power tracking 2A battery charger |  | LT3652EDD#PBF-ND | Linear Technology |  | LT3652EDD#PBF
1 | LTC2941 | LTC2941 | DFN-6-2MMX3MM | U8 | I2C Battery Gas Gauge |  | LTC2941IDCB#TRMPBFCT-ND | Linear Technology |  | LTC2941IDCB#TRMPBF
8 | LTC2943 | LTC2943 | DFN-8 | U9, U10, U11, U12, U13, U14, U15, U26 | Multicell Battery Gas Gauge |  | LTC2943IDD#PBF-ND | Linear Technology |  | LTC2943IDD#PBF
1 | M24C01WMN | M24C01WMN | SOIC-8 | U29 | 1K I2C™ Serial EEPROM |  | 497-8631-1-ND | STMicroelectronics |  | M24C01-WMN6TP
1 | MAX17205 | MAX17205 | 14-TDFN | U18 | Stand-Alone ModelGauge m5 Fuel Gauge |  | MAX17205G+00E-ND | Maxim Integrated | 700-MAX17205G+00E | MAX17205G+00E
1 | MAX6746 | MAX6746 | SOT-23-8 | U27 | A simple watchdog timer with adjustable timeouts and reset time |  | MAX6746KA29+TCT-ND | Maxim Integrated |  | MAX6746KA29+T
1 | MODULE_POWER | MODULE_POWER | MODULE_POWER | J1 | Header for power module for signpost |  | S9172-ND | Sullins Connector Solutions |  | SBH11-PBPC-D10-ST-BK
1 | MOSFET-NCHANNELSMD | MOSFET-NCHANNELSMD | SOT23-3 | Q1 | Generic NMOS footprint | MOSFET N-CH 60V 0.115A SOT-23 | 2N7002LT1GOSCT-ND | ON Semiconductor |  | 2N7002LT1G
3 | PCA9544AQFN-N20 | PCA9544AQFN-N20 | QFN-N20 | U6, U7, U25 | 1-4 I2C/SMBUS Multiplexer with interrupt for power supply coulomb counters |  | 296-20960-1-ND | Texas Instruments |  | PCA9544ARGYR
1 | PTS810SJ | PTS810SJ | PTS810SJ | S2 | PTS810SJ Push Button Switch |  | CKN10504CT-ND | C&K |  | PTS810 SJG 250 SMTR LFS
1 | SN74AUP1T14DCKR | SN74AUP1T14DCKR | SC70 | U30 | LOW POWER, 1.8/2.5/3.3-V INPUT, 3.3-V CMOS OUTPUT, SINGLE |  | 296-27392-1-ND | Texas Instruments |  | SN74AUP1T14DCKR
1 | TE_SSA12/SPDT | TE_SSA12/SPDT | TE_SSA12/SPDT | S1 | SWITCH SLIDE SPDT 2POS SSA SER |  | 450-1602-ND | TE Connectivity |  | SSA12
5 | TLV62130 | TLV62130 | TQFN-16/3MM | U1, U2, U3, U4, U5 | High Efficient 3A switching step-down regulator. 1V-5V out, 4V-17V in. |  | 296-35978-1-ND | Texas Instruments |  | TLV62130RGTR

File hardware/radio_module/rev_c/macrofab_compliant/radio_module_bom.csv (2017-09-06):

Part | Value | Device | Package | Description | DESCRIPTION | DIGIKEY | MANUFACTURER | MOUSER | MPN | RICHARDSON_RFPD
A1 | FRACTUS-2.4GHZ-FR05-S1-N-0-102 | FRACTUS-2.4GHZ-FR05-S1-N-0-102 | FRACTUS-ANTENNA-FR05-S1-N-0-102 | Fractus Compact Reach XtendTM chip antenna is engineered specifically for Bluetooth, |  |  | Fractus |  | FR05-S1-N-0-102 | FR05-S1-N-0102B
B1 | BAL-NRF01D3 | BAL-NRF01D3 | BAL-NRF01D3 | 50 ohm nominal input / conjugate match balun to nRF51422-QFAA, |  | 497-13637-1-ND |  | 511-BAL-NRF01D3
C1 | 0.8pF | CAPACITOR0402_CAP | 0402_CAP | SMD Capacitor | CAP CER 0.8PF 50V C0G/NP0 0402 | 490-6269-1-ND | Murata |  | GRM1555C1HR80BA01D
C2 | 8pF | CAPACITOR0402_CAP | 0402_CAP | SMD Capacitor | CAP CER 8PF 50V C0G/NP0 0402 | 490-8230-1-ND | Murata |  | GRM1555C1H8R0BA01D
C3 | 8pF | CAPACITOR0402_CAP | 0402_CAP | SMD Capacitor | CAP CER 8PF 50V C0G/NP0 0402 | 490-8230-1-ND | Murata |  | GRM1555C1H8R0BA01D
C4 | 12pF | CAPACITOR0402_CAP | 0402_CAP | SMD Capacitor | CAP CER 12PF 50V C0G/NP0 0402 | 490-6197-1-ND | Murata |  | GRM1555C1H120GA01D
C5 | 12pF | CAPACITOR0402_CAP | 0402_CAP | SMD Capacitor | CAP CER 12PF 50V C0G/NP0 0402 | 490-6197-1-ND | Murata |  | GRM1555C1H120GA01D
C6 | 12pF | CAPACITOR0402_CAP | 0402_CAP | SMD Capacitor | CAP CER 12PF 50V C0G/NP0 0402 | 490-6197-1-ND | Murata |  | GRM1555C1H120GA01D
C7 | 12pF | CAPACITOR0402_CAP | 0402_CAP | SMD Capacitor | CAP CER 12PF 50V C0G/NP0 0402 | 490-6197-1-ND | Murata |  | GRM1555C1H120GA01D
C8 | 33pF | CAPACITOR0603_CAP | 0603_CAP | SMD Capacitor | CAP CER 33PF 250V C0G/NP0 0603 | 712-1342-1-ND | Johanson |  | 251R14S330JV4T
C9 | 47pF | CAPACITOR0402_CAP | 0402_CAP | SMD Capacitor | CAP CER 47PF 50V C0G/NP0 0402 | 490-6241-1-ND | Murata |  | GRM1555C1H470FA01D
C10 | 47pF | CAPACITOR0402_CAP | 0402_CAP | SMD Capacitor | CAP CER 47PF 50V C0G/NP0 0402 | 490-6241-1-ND | Murata |  | GRM1555C1H470FA01D
C11 | 47pF | CAPACITOR0402_CAP | 0402_CAP | SMD Capacitor | CAP CER 47PF 50V C0G/NP0 0402 | 490-6241-1-ND | Murata |  | GRM1555C1H470FA01D
C12 | 47pF | CAPACITOR0402_CAP | 0402_CAP | SMD Capacitor | CAP CER 47PF 50V C0G/NP0 0402 | 490-6241-1-ND | Murata |  | GRM1555C1H470FA01D
C13 | 56pF | CAPACITOR0402_CAP | 0402_CAP | SMD Capacitor | CAP CER 56PF 50V C0G/NP0 0402 | 490-1288-1-ND | Murata |  | GRM1555C1H560JA01D
C14 | 1nF | CAPACITOR0402_CAP | 0402_CAP | SMD Capacitor | CAP CER 1000PF 50V X7R 0402 | 490-1303-1-ND | Murata |  | GRM155R71H102KA01D
C15 | 1nF | CAPACITOR0402_CAP | 0402_CAP | SMD Capacitor | CAP CER 1000PF 50V X7R 0402 | 490-1303-1-ND | Murata |  | GRM155R71H102KA01D
C16 | 2.2nF | CAPACITOR0402_CAP | 0402_CAP | SMD Capacitor | CAP CER 2200PF 25V 10% X7R 0402 | 490-5419-1-ND | Murata |  | GRM155R71E222KA01D
C17 | 3.3nF | CAPACITOR0402_CAP | 0402_CAP | SMD Capacitor | CAP CER 3300PF 50V 10% X7R 0402 | 490-3248-1-ND | Murata |  | GRM155R71H332KA01D
C18 | 3.3nF | CAPACITOR0402_CAP | 0402_CAP | SMD Capacitor | CAP CER 3300PF 50V 10% X7R 0402 | 490-3248-1-ND | Murata |  | GRM155R71H332KA01D
C19 | 10nF | CAPACITOR0402_CAP | 0402_CAP | SMD Capacitor | CAP CER 10000PF 50V 10% X7R 0402 | 490-4516-1-ND | Murata |  | GRM155R71H103KA88D
C20 | 47nF | CAPACITOR0402_CAP | 0402_CAP | SMD Capacitor | CAP CER 0.047UF 25V X7R 0402 | 490-3254-1-ND | Murata |  | GRM155R71E473KA88D
C21 | 100nF | CAPACITOR0402_CAP | 0402_CAP | SMD Capacitor | CAP CER 0.1UF 10V X7R 0402 | 490-10777-1-ND | Murata |  | GRM155R71A104JA01D
C22 | 100nF | CAPACITOR0402_CAP | 0402_CAP | SMD Capacitor | CAP CER 0.1UF 10V X7R 0402 | 490-10777-1-ND | Murata |  | GRM155R71A104JA01D
C23 | 100nF | CAPACITOR0402_CAP | 0402_CAP | SMD Capacitor | CAP CER 0.1UF 10V X7R 0402 | 490-10777-1-ND | Murata |  | GRM155R71A104JA01D
C24 | 100nF | CAPACITOR0402_CAP | 0402_CAP | SMD Capacitor | CAP CER 0.1UF 10V X7R 0402 | 490-10777-1-ND | Murata |  | GRM155R71A104JA01D
C25 | 100nF | CAPACITOR0402_CAP | 0402_CAP | SMD Capacitor | CAP CER 0.1UF 10V X7R 0402 | 490-10777-1-ND | Murata |  | GRM155R71A104JA01D
C26 | 100nF | CAPACITOR0402_CAP | 0402_CAP | SMD Capacitor | CAP CER 0.1UF 10V X7R 0402 | 490-10777-1-ND | Murata |  | GRM155R71A104JA01D
C27 | 100nF | CAPACITOR0402_CAP | 0402_CAP | SMD Capacitor | CAP CER 0.1UF 10V X7R 0402 | 490-10777-1-ND | Murata |  | GRM155R71A104JA01D
C28 | 100nF | CAPACITOR0402_CAP | 0402_CAP | SMD Capacitor | CAP CER 0.1UF 10V X7R 0402 | 490-10777-1-ND | Murata |  | GRM155R71A104JA01D
C29 | 100nF | CAPACITOR0402_CAP | 0402_CAP | SMD Capacitor | CAP CER 0.1UF 10V X7R 0402 | 490-10777-1-ND | Murata |  | GRM155R71A104JA01D
C30 | 1uF | CAPACITOR0402_CAP | 0402_CAP | SMD Capacitor | CAP CER 1UF 6.3V X5R 0402 | 490-1320-1-ND | Murata |  | GRM155R60J105KE19D
C31 | 4.7uF | CAPACITOR0402_CAP | 0402_CAP | SMD Capacitor | CAP CER 4.7UF 10V X5R 0402 | 490-13252-1-ND | Murata |  | ZRB15XR61A475KE01D
C32 | 6.8uF | CAPACITOR0402_CAP | 0402_CAP | SMD Capacitor | CAP CER 4.7UF 10V X5R 0402 | 490-13252-1-ND | Murata |  | ZRB15XR61A475KE01D
C33 | 10uF | CAPACITOR0402_CAP | 0402_CAP | SMD Capacitor | CAP CER 10UF 6.3V X6S 0402 | 490-13233-1-ND | Murata |  | GRM155C80J106ME11D
C34 | 10uF | CAPACITOR0402_CAP | 0402_CAP | SMD Capacitor | CAP CER 10UF 6.3V X6S 0402 | 490-13233-1-ND | Murata |  | GRM155C80J106ME11D
C35 | 10uF | CAPACITOR0402_CAP | 0402_CAP | SMD Capacitor | CAP CER 10UF 6.3V X6S 0402 | 490-13233-1-ND | Murata |  | GRM155C80J106ME11D
C36 | 22uF | CAPACITOR0402_CAP | 0402_CAP | SMD Capacitor | CAP CER 22UF 6.3V X5R 0402 | 1276-6834-1-ND | Samsung |  | CL05A226MQ5QUNC
C37 | 22uF | CAPACITOR0402_CAP | 0402_CAP | SMD Capacitor | CAP CER 22UF 6.3V X5R 0402 | 1276-6834-1-ND | Samsung |  | CL05A226MQ5QUNC
C38 | 100uF | CAPACITOR0805_CAP | 0805_CAP | SMD Capacitor | CAP CER 100UF 6.3V X5R 0805 | 490-13981-1-ND | Murata |  | GRM21BR60J107ME15L
C39 | 220uF | CAPACITOR1210_CAP | 1210_CAP | SMD Capacitor | CAP CER 220UF 6.3V X5R 1210 | 1276-3375-1-ND | Samsung |  | CL32A227MQVNNNE
D1 | 14V | DIODE_ZENER0402 | 0402_DIODE |  |  | PESD0402-140CT-ND | Littlefuse |  | PESD0402-140
D2 | 14V | DIODE_ZENER0402 | 0402_DIODE |  |  | PESD0402-140CT-ND | Littlefuse |  | PESD0402-140
D3 | 14V | DIODE_ZENER0402 | 0402_DIODE |  |  | PESD0402-140CT-ND | Littlefuse |  | PESD0402-140
D4 | 14V | DIODE_ZENER0402 | 0402_DIODE |  |  | PESD0402-140CT-ND | Littlefuse |  | PESD0402-140
FB1 | 1.5k | FERRITE_BEAD0402 | 0402_CAP |  | FERRITE BEAD 1.5 KOHM 0402 1LN | 445-2158-1-ND | TDK |  | MMZ1005Y152CT000
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

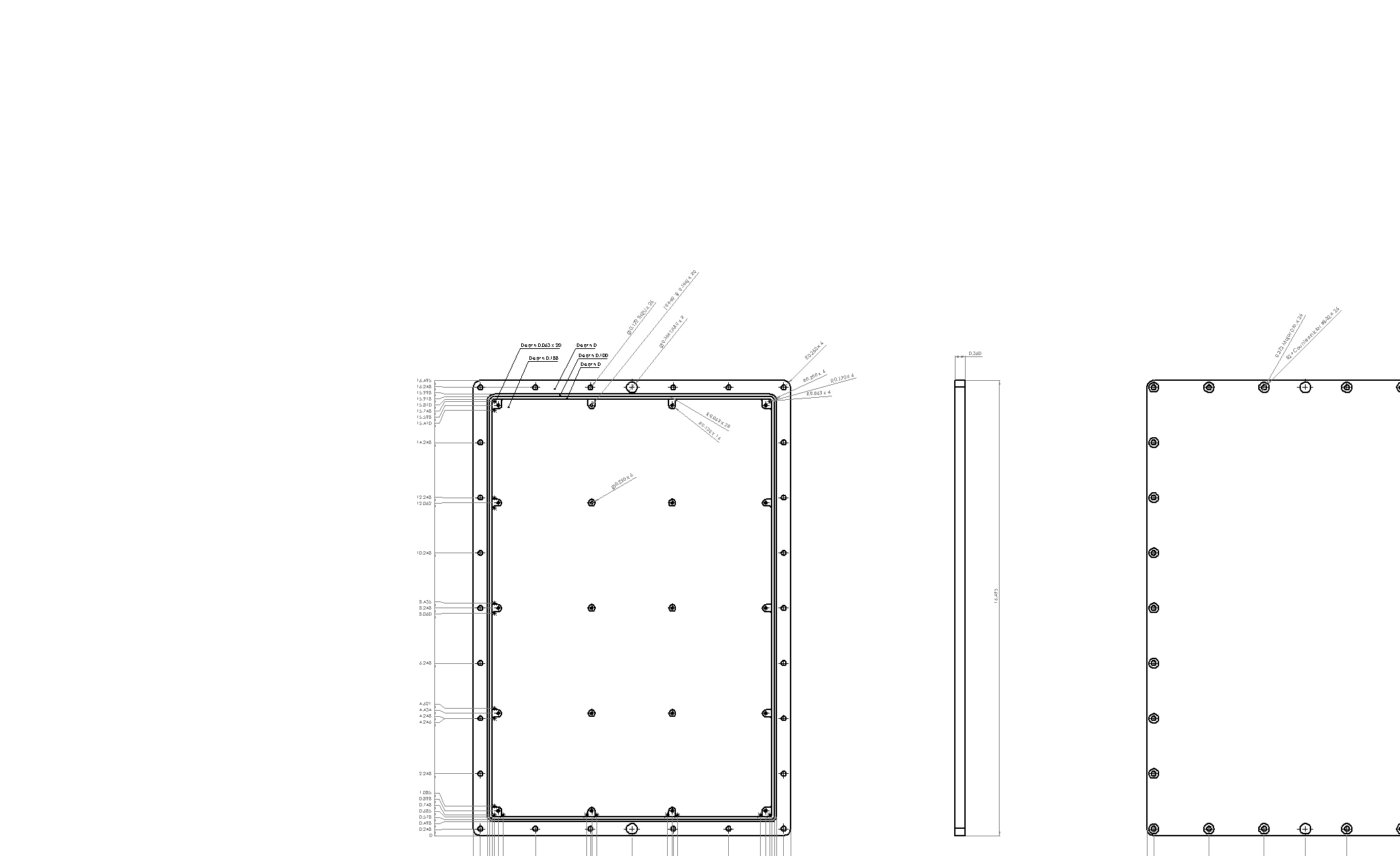
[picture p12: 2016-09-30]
case/parts/For_UM_Machine_Shop/back_panel/2D/back_panel.JPG

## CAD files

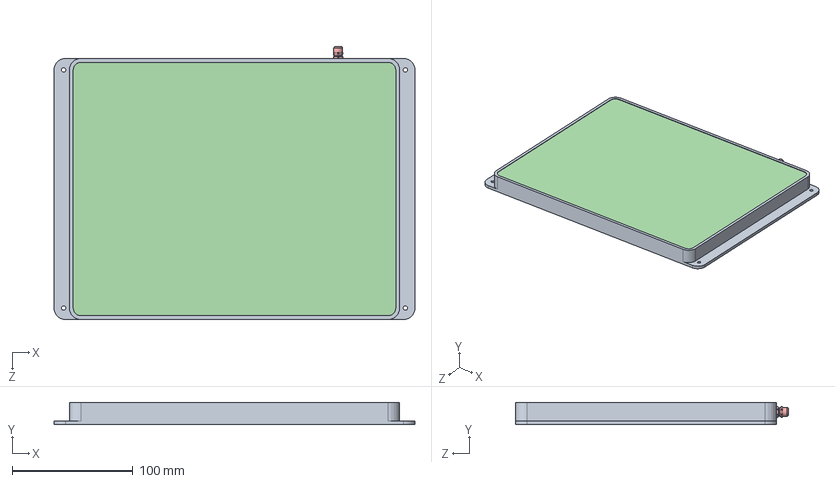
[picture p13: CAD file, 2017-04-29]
case/battery_case.SLDASM
298.5 x 18.5 x 225.8 mm
battery_case_back
batter_pack_pcb
battery_cell x 3
battery_case_top
8183K500_SUBMERSIBLE LIQUID-TIGHT CORD GRIP

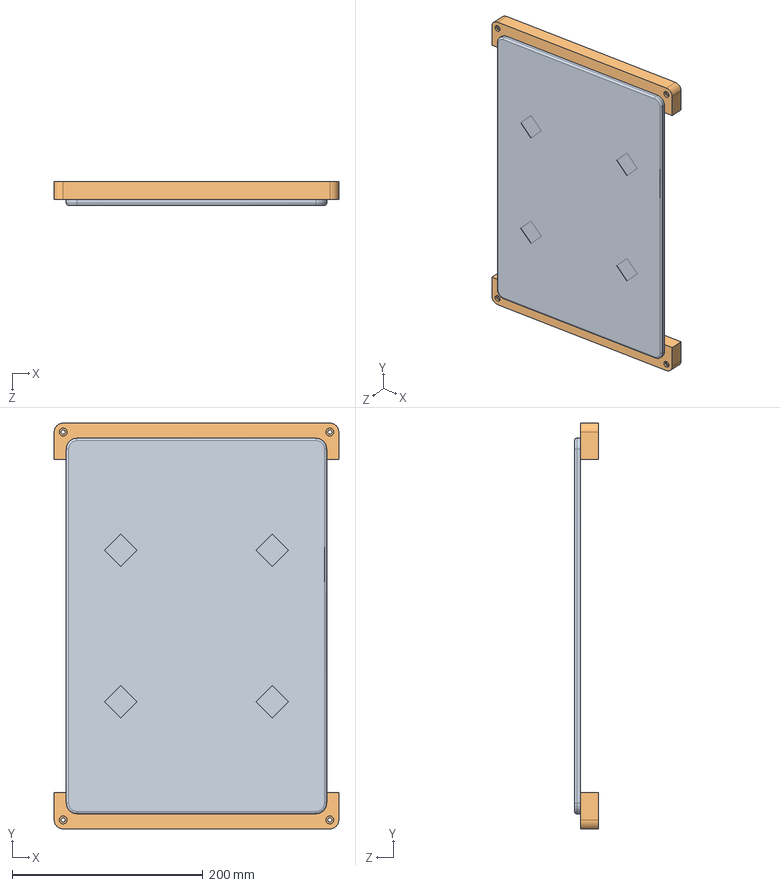
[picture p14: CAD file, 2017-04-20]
case/solar_panel_mounted.SLDASM
298.5 x 425.5 x 25.4 mm
17W Panel
solar_mount_top x 2
93330A571_ALUM FEM THRDED ROUND STANDOFF x 6
92196A109_18-8 STAINLESS STEEL SOCKET HEAD CAP SCREW x 6

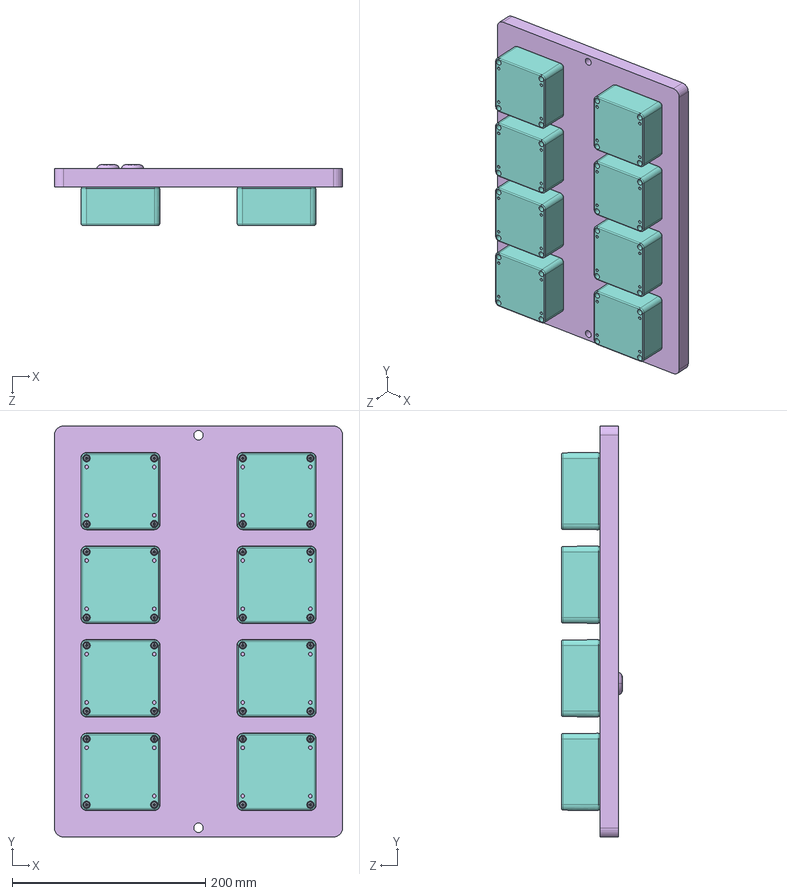
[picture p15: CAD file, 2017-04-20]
case/backplane_assembly.SLDASM
298.5 x 425.5 x 63.2 mm
back_panel
pcb
91772A107_18-8 SS PAN HEAD PHILLIPS MACHINE SCREW x 20
keystone_1892_0375_#4_standoff x 32
91772A106_18-8 SS PAN HEAD PHILLIPS MACHINE SCREW x 64
back_panel_cover
o_ring x 8
box_top x 8
96710A218_18-8 SS PAN HEAD TORX MACHINE SCREW x 32
91771A196_18-8 SS FLAT HEAD PHILLIPS MACHINE SCREW x 22
module_pcb x 8
back_panel_oring
C2058_QUILT_1 x 2
C2058_QUILT_2 x 2

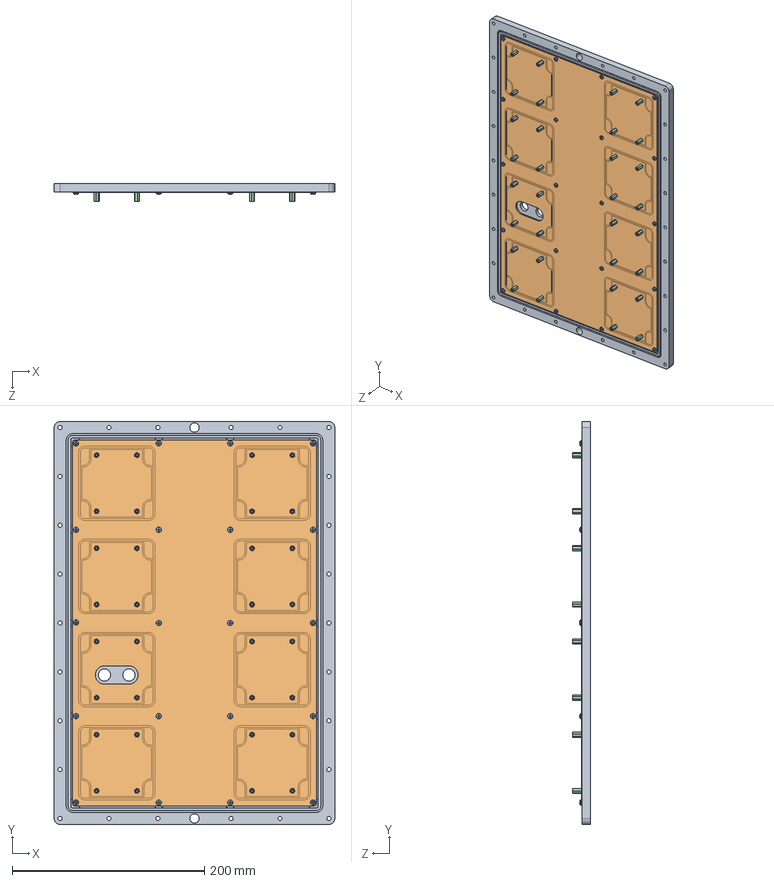
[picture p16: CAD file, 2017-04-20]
case/back_panel_assem.SLDASM
292.0 x 419.0 x 19.1 mm
back_panel
pcb
91772A107_18-8 SS PAN HEAD PHILLIPS MACHINE SCREW x 20
keystone_1892_0375_#4_standoff x 32
91772A106_18-8 SS PAN HEAD PHILLIPS MACHINE SCREW x 32

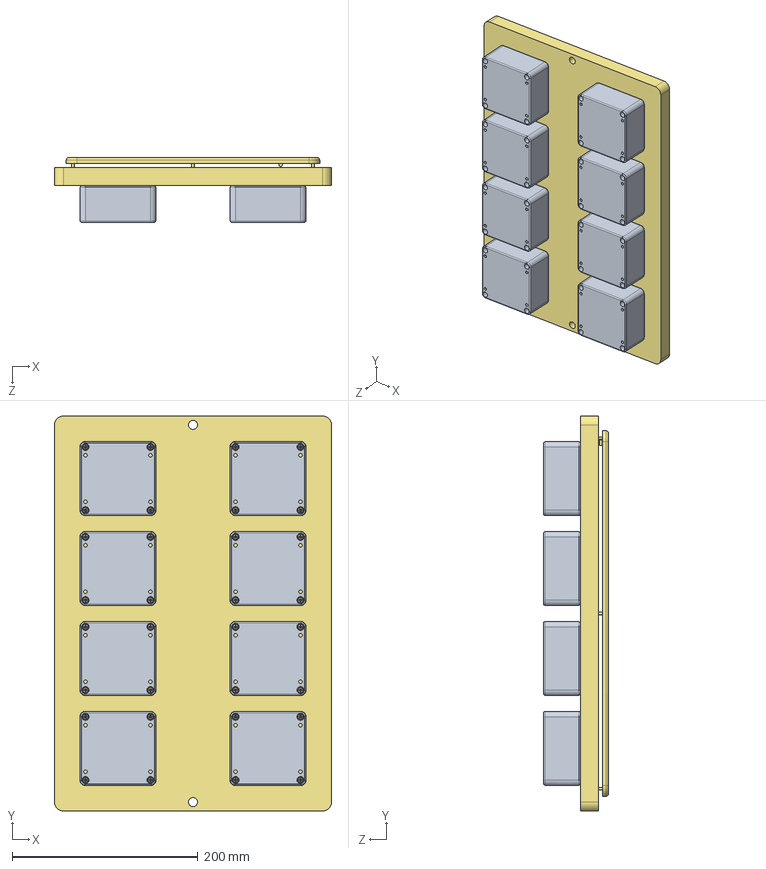
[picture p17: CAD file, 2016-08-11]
case/back_panel_assem_solarpanel.SLDASM
298.5 x 425.5 x 70.1 mm
back_panel
pcb
91780A521_ALUM FEM THRDED HEX STANDOFF x 20
91772A107_18-8 SS PAN HEAD PHILLIPS MACHINE SCREW x 20
keystone_1892_0375_#4_standoff x 32
91772A106_18-8 SS PAN HEAD PHILLIPS MACHINE SCREW x 64
back_panel_cover
o_ring x 8
box_top x 8
96710A218_18-8 SS PAN HEAD TORX MACHINE SCREW x 32
91771A196_18-8 SS FLAT HEAD PHILLIPS MACHINE SCREW x 22
module_pcb_oring x 8
module_pcb x 8
back_panel_oring
17W Panel

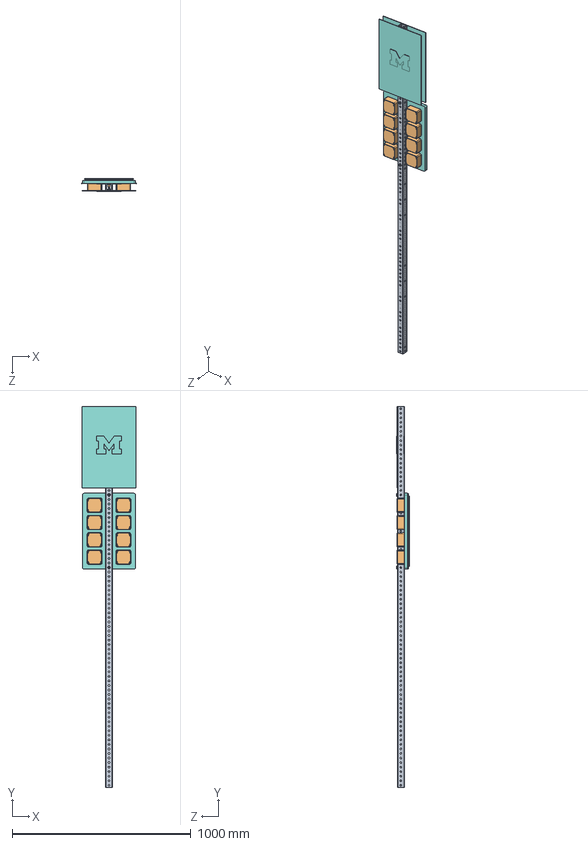
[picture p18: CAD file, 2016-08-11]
case/solar_panel_on_signpost.SLDASM
304.8 x 2133.6 x 75.3 mm
post
back_panel
pcb
91780A521_ALUM FEM THRDED HEX STANDOFF x 20
91772A107_18-8 SS PAN HEAD PHILLIPS MACHINE SCREW x 20
keystone_1892_0375_#4_standoff x 32
91772A106_18-8 SS PAN HEAD PHILLIPS MACHINE SCREW x 64
back_panel_cover
o_ring x 8
box_top x 8
96710A218_18-8 SS PAN HEAD TORX MACHINE SCREW x 32
91771A196_18-8 SS FLAT HEAD PHILLIPS MACHINE SCREW x 22
module_pcb_oring x 8
module_pcb x 8
back_panel_oring
gold_sign x 2
17W Panel
90765A634_ALLOY 20 HEX HEAD CAP SCREW x 2
90101A243_TYPE 18-8 SS THIN NYLON-INSERT LOCKNUT x 2

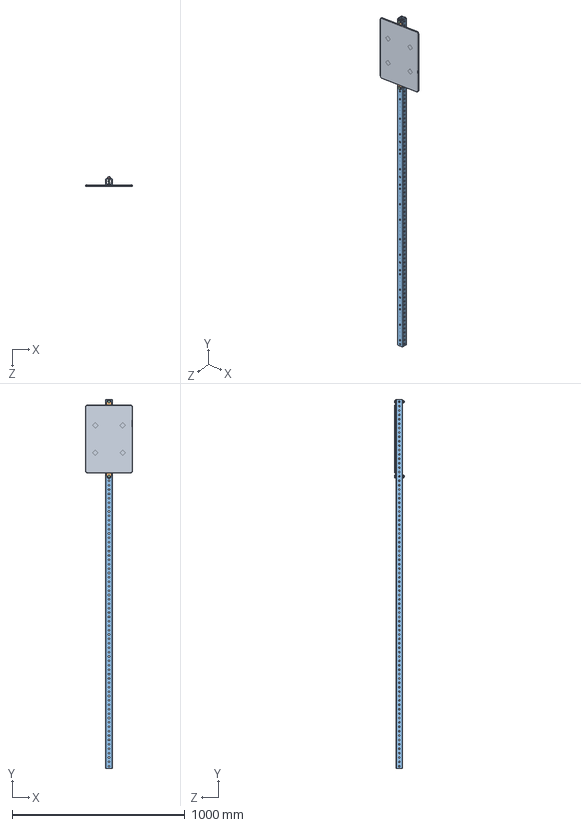
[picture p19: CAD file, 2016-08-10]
case/voltaic_17w_panel_signpost.SLDASM
273.1 x 2133.6 x 57.2 mm
17W Panel
voltaic_17w_solar_panel_mount x 2
post
93190A632_TYPE 316 STAINLESS STEEL HEX HEAD CAP SCREW x 2
91845A031_TYPE 18-8 STAINLESS STEEL HEX NUT x 2

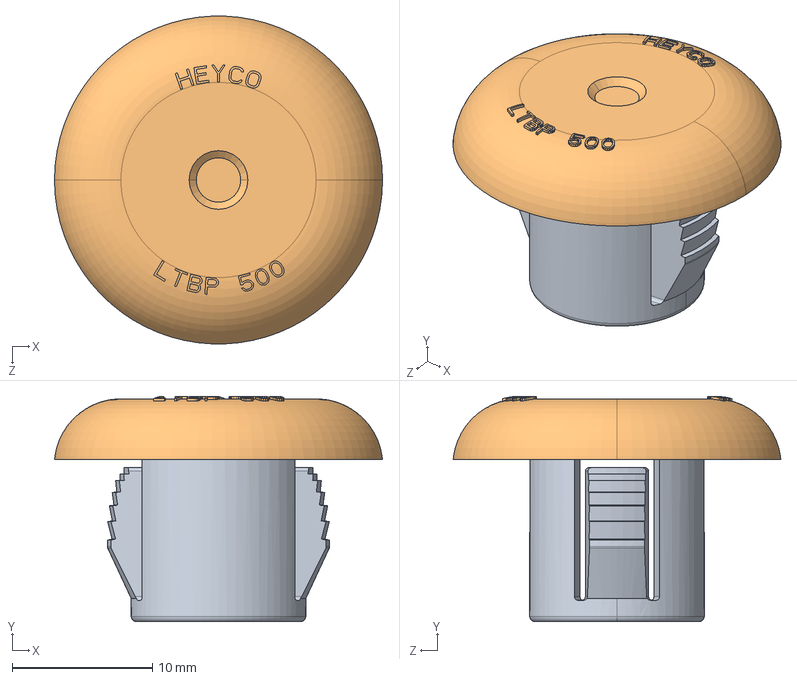
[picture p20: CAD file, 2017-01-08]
case/parts/COTS_hardware/heyco-c2508.SLDASM
23.4 x 16.1 x 23.3 mm
C2058_QUILT_1
C2058_QUILT_2

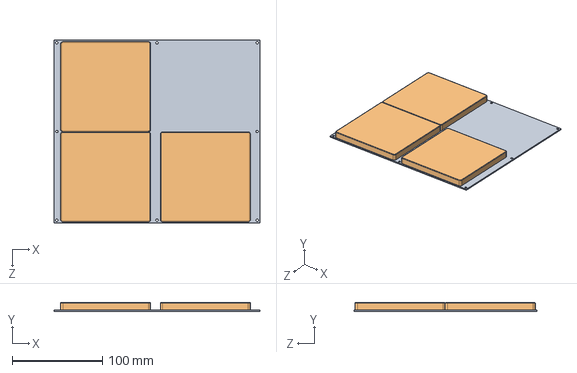
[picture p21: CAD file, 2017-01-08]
case/parts/battery_pcb.SLDASM
228.6 x 10.2 x 203.2 mm
batter_pack_pcb
battery_cell x 3

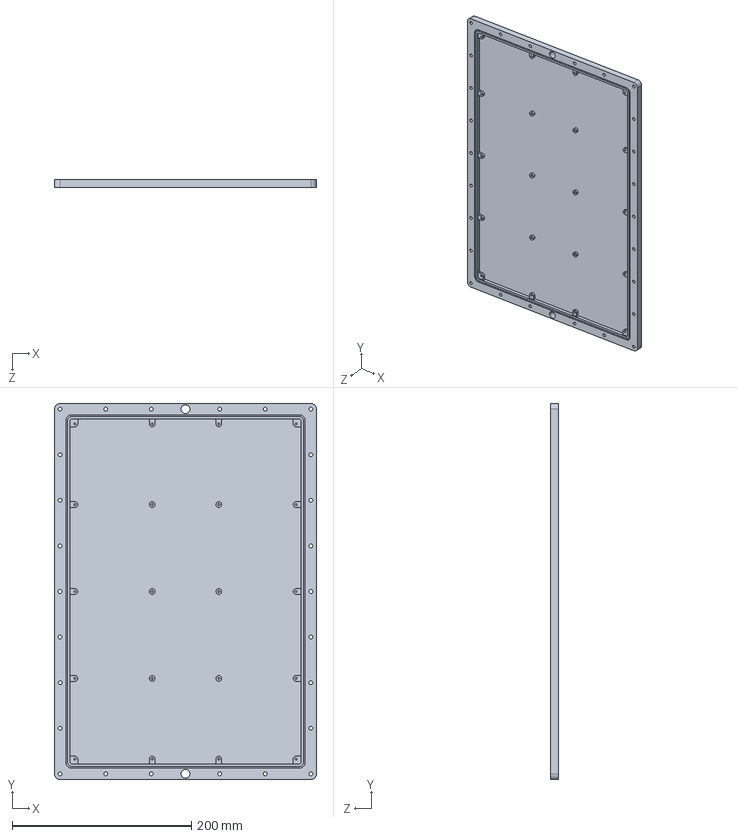
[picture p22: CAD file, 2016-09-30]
case/parts/For_UM_Machine_Shop/back_panel/3D/back_panel.STEP
292.0 x 419.0 x 9.14 mm

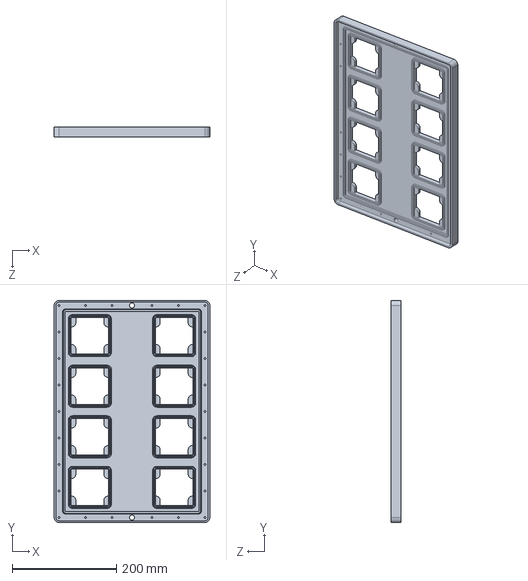
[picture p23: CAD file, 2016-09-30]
case/parts/For_UM_Machine_Shop/back_panel_cover/3D/back_panel_cover.STEP
298.4 x 425.4 x 19.1 mm

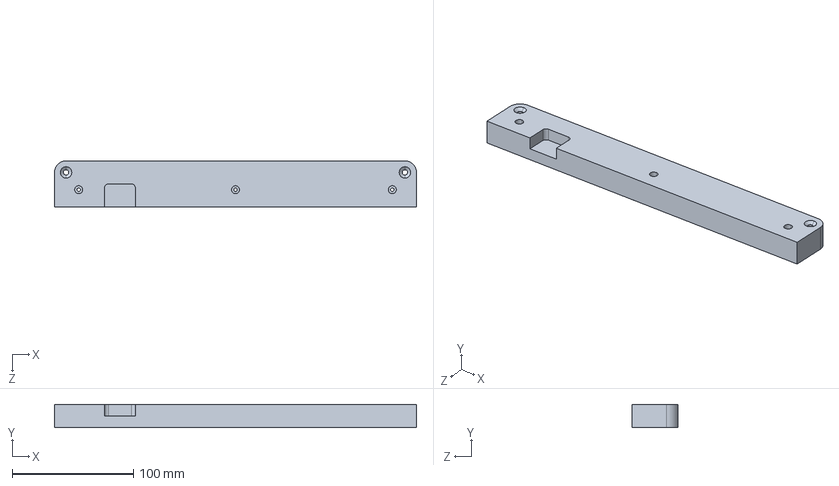
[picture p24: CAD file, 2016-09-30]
case/parts/For_UM_Machine_Shop/solar_mount/3D/solar_mount.STEP
298.4 x 19.1 x 38.1 mm

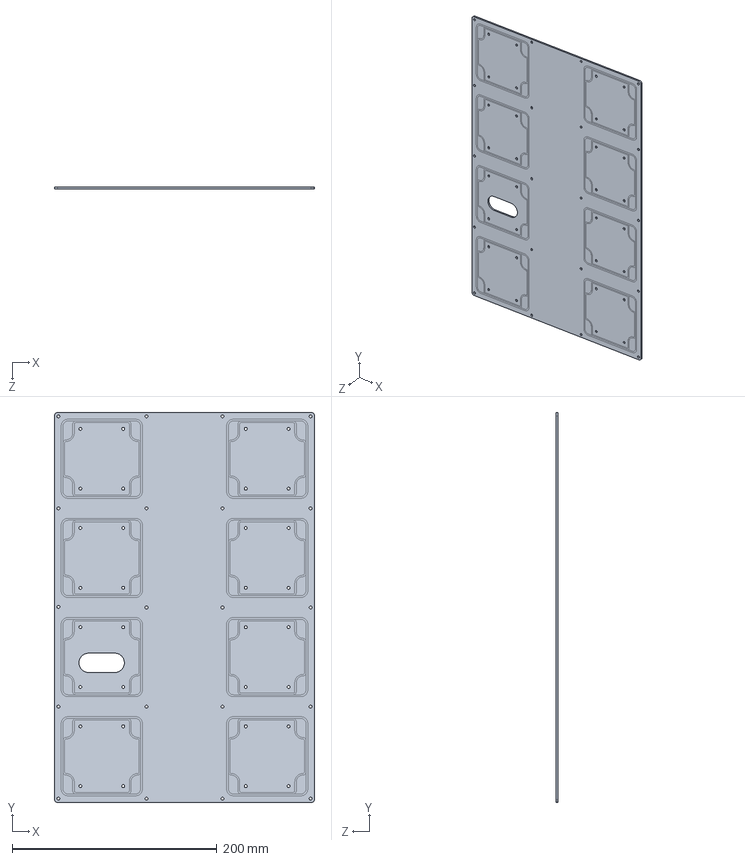
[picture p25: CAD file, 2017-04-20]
case/parts/pcb.SLDPRT
254.0 x 381.0 x 2.08 mm

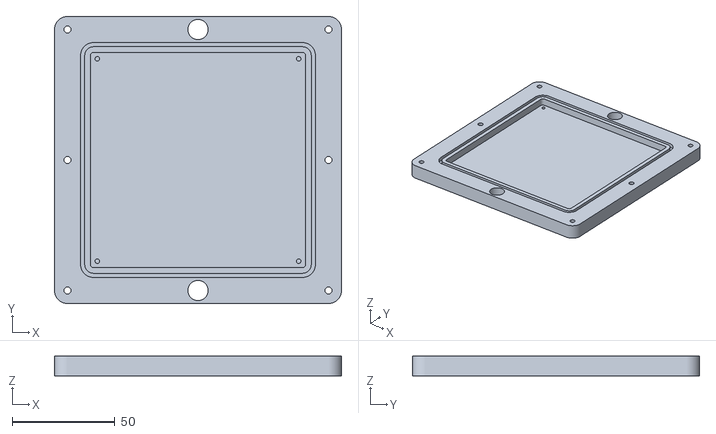
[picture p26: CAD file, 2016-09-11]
case/parts/printer/back_panel_small2.STL
139.6 x 139.6 x 9.53

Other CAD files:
case/parts/Product_files/sunpe_04_28_2017/battery_case_top.STEP
case/parts/back_panel_cover.SLDPRT
case/parts/Product_files/sunpe_04_28_2017/back_panel_cover.STEP
case/parts/Product_files/sunpe_04_28_2017/solar_mount_top.STEP
case/parts/17W Panel.SLDPRT
case/parts/COTS_hardware/1-8-ips-3-4-long.SLDPRT
case/parts/COTS_hardware/10-32_heat_set.SLDPRT
case/parts/COTS_hardware/4061T118_SQUARE-PROFILE O-RING.SLDPRT
case/parts/COTS_hardware/4548K111_STD-WALL TYPE 316-316L SS THRD PIPE NIPPLE.SLDPRT
case/parts/COTS_hardware/8-32_press_in.SLDPRT
case/parts/COTS_hardware/8183K500_SUBMERSIBLE LIQUID-TIGHT CORD GRIP.SLDPRT
case/parts/COTS_hardware/90013A225_TAMPER-RST BREAKAWAY NUTS.SLDPRT
case/parts/COTS_hardware/90101A243_TYPE 18-8 SS THIN NYLON-INSERT LOCKNUT.SLDPRT
case/parts/COTS_hardware/90128A635_ZNC-PLTD ALLOY STL SCKT HEAD CAP SCREW.SLDPRT
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

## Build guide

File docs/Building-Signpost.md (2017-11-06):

Building a Signpost Platform
============================

Coming soon! If you want more information, please file an issue or
email us at <signpost-admin@eecs.berkeley.edu>.

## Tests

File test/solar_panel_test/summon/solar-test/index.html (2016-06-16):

S O L A R T E S T

# deviceId

Waiting for data...

Voltage (V): | 0
Current (A): | 0
Estimated Power (W): | 0

## Log

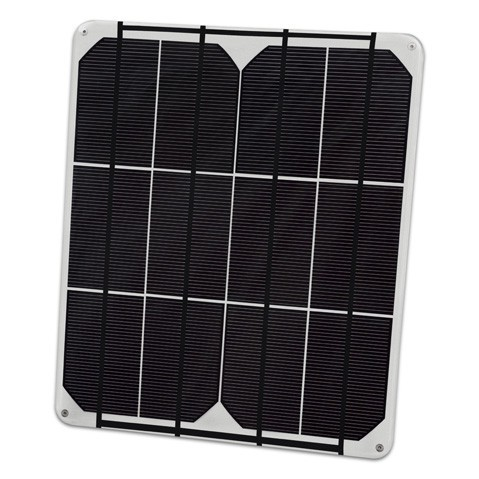
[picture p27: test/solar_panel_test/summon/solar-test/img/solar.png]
solar_img


Solar Test: Estimating solar panel output power.

Find out more at https://github.com/lab11/sign-post (https://github.com/lab11/blees).

- About
- Log

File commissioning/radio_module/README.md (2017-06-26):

This commissioning script writes trusted root certificates to the radio module.

It takes them from the /certs folder and runs the correct AT commands to put
them onto a ublox sara U260.

To use the script hook a USB to serial converter up to the TX/RX pins of
the UBLOX SARA U260 on the radio module.

To add certificates, place them in the ./certs fold in der  or pem format.

At the end it prints the list of certificates installed on module.

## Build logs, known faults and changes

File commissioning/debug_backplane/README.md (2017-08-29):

Debug Backplane Commissioning
=============================

These scripts name the serial ports of the debug backplane.

The individual scripts are suitable for programming one FTDI chip, and
only work properly if one FTDI chip is currently attached to your computer.

The commissional_all.py script will reprogram multiple FTDI chips attached to
a hub such is the case with the new version of the debug backplane. It
finds all devices and names the ftdi chips based on their location on 
the debug backplane hub.

Both scripts utilize [ft232r_prog](http://rtr.ca/ft232r/) which uses libftdi-dev
to rename the devices.  

You probably want to install libftdi-dev and run these scripts 
on a linux computer due to mac problems with libftdi.

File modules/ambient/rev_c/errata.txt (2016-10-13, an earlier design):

Need pull up resistors for SWDIO and SWDCLK lines
Random trace on pin32?

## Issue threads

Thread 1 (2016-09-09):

Backplane RevA updates

bradjc, 2016-09-09:
- [x] Numbers in silkscreen for modules
- [x] Move part labels off of vias (korea is ok when the vias are small, these vias are big)
- [x] Fix U30 package (and the other 5)
- [x] Minimize plane area (?)
- [x] USB data muxes have wrong control signals. Should be fed with `MODn_USB_!EN`, not `MODn_ISO_USB`
- [x] Also, it seems like the unused port should have pull downs: https://e2e.ti.com/support/interface/digital_interface/f/130/p/367935/1295211#1295211
- [x] Pull `!BACKPLANE_RESET` high instead of low
   - [x] ~~Add jumper spot for !backplane_reset to VCC~~
- [x] Fix stubs on USB pull-down resistors (see 4.1 of http://www.usb.org/developers/docs/hs_usb_pdg_r1_0.pdf)
- [x] Update power module for battery / solar attachment
- [x] Add pullup `!OVR` for unused USB port

ppannuto, 2016-09-09:
* USB data muxes have wrong control signals. Should be fed with `MODn_USB_!EN`, not `MODn_ISO_USB`

bradjc, 2016-09-09:
I also think we should revisit this somewhat bizarre decision to reset by default. Do we really want the controller to say "If I can't work then nothing can work!!! Muwahahahaha!"?

ppannuto, 2016-09-09:
It wasn't so malicious as that sounds. The idea behind it was protection of
the system. If the controller resets itself, dies, or w/e, then while the
controller is out of commission a wayward module can't bleed the system
dry.

What would you prefer the default behavior to be if there's no active
controller, turn everything on?

On Fri, Sep 9, 2016 at 10:50 AM Brad Campbell <notifications@github.com>
wrote:

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

bradjc, 2016-09-09:
In the case that the controller is gonezo, then everything is broken and I don't think it matters what happens. But in case that controller resets briefly, everything would break, even in the case the controller comes back in a few milliseconds. Things like USB to linux, and I2C to radio can all keep happening while the controller resets. And the power supply should still be aggregating the energy of each module.

ppannuto, 2016-09-09:
That's almost already the situation.

Because all of the modules are on GPIO extenders, they wouldn't change state when the controller goes away. The missing bit is that `!BACKPLANE_RESET` will trip because the controller isn't holding it any more (which will then cause all the GPIO extenders to reset).

Perhaps the right solution then is to latch/buffer `!BACKPLANE_RESET` the same way. That way the signpost still "boots up" to a sane state when all power is lost, but if the controller disappears for a bit things will keep on keeping on (and the controller can read all the GPIO extenders to learn the state on reset).

bradjc, 2016-09-09:
What about just pulling !RESET high and calling it a day? Who knows what state everything is in during reset, but everything should be fine in the default, just resetted state. The controller can reset everything if it wants. All the modules will still default to disabled.

Also, it seems like the unused port should have pull downs: https://e2e.ti.com/support/interface/digital_interface/f/130/p/367935/1295211#1295211

ppannuto, 2016-09-11:
Currently, the debug LEDs for the backplane live in the corner on each module, but are covered by the backplane case when it's installed.

The original thoughts for this were
  - You likely won't populate the debug LEDs on a deployed board b/c they burn power
  - There are no components anywhere under modules so module creators can consider the full vertical space under the module as theirs

Thinking more
  - It sucks a little that you don't have the option for debug LEDs and case
  - It's unlikely that an smd LED and an 0603 resistor are going to break the bank for vertical space for module makers (though it does become something they may have to think about in corner cases)

I'm leaning towards moving these more in the middle of the module space but wanted to see if anyone thought that was a terrible idea for some reason

bradjc, 2016-09-12:
At first I was opposed to this, then for it, and now I'm against it again. While I agree having the LEDs visible inside the case would be useful (particularly for a demo), they are only useful for populated modules, but once the module is populated you won't be able to see the LEDs anymore.

ppannuto, 2016-09-12:
Yeah, that's the same back and forth I went through the first time. Eventually concluded that having unpopulated parts visible wasn't a great aesthetic, happy to leave that conclusion.

ppannuto, 2016-09-12:
@adkinsjd can you send me any hole / mounting / plating requirements for the new power connectors you're looking at? I just need enough dimensions to put holes in the right place on the PCB

ppannuto, 2016-09-13:
@adkinsjd I removed the jumper terminals and put one hole at `(1.749, 5.751) drill 1.125`.

Do I need to do anything else?

ppannuto, 2016-09-20:
Most recent commit removes a lot of metal. Hopefully that should make things more manageable.

@bradjc is there anything worth trying to do to the footprint of U20-25 to make that part more solderable? Smaller planes will help, but it's necessarily in the middle of the planes for the USB traces, so there's still non-trivial metal around them.

I think it's about ready to pull the trigger on Rev B

Closed 2016-09-29.

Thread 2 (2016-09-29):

Controller RevA Updates

ppannuto, 2016-09-29:
Issue to track fixes for controller RevA
- [x] There are two pins labeled `USB_D+` and none `USB_D-`

brghena, 2016-09-29:
Other issues with Controller Rev A

  - [ ] VR1 doesn't have a Pin 1 marker
  - [ ]
  - [ ]
  - [ ]
  - [ ]

ppannuto, 2016-09-30:
@brghena when you fix "D1 has basically no markings on it's package and is really hard to tell orientation on", can you poke me to fix on seinduino somehow?

brghena, 2016-10-01:
- [ ] GND pads extremely hard to solder on controller module headers

brghena, 2016-10-23:
- [ ] Need ability to reset GPS

brghena, 2016-11-02:
- [ ] USB_ID connection for Edison is incorrect. Needs to be Grounded in normal case (acts as host) and Floating in programming case (acts as peripheral). (https://www.maximintegrated.com/en/app-notes/index.mvp/id/1822)

nealjack, 2016-12-06:
- [ ] Edison on controller draws 2x-4x the current of an Edison on the breakout board
- [ ] Controller draws over 100mA on its own. We think it's the GPS
- [ ] Power gate GPS, add reset line
- [ ] Power gate everything

brghena, 2017-01-18:
The vast majority of this has been handled in Control Module rev B (ca164b0e88493279cb7291171baee575391ca474)

The issues with D1 and C25-C27 have been ignored. The large power draw of the Edison will be further investigated when the new board is complete

Closed 2017-01-18.

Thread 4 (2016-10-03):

Still having problems with Baud rate not matching the setting

adkinsjd, 2016-10-03:
In tock, I am still having to manually adjust my baud rate up to 125000 to get an actual baud rate of 115200.

bradjc, 2016-10-03:
Yeah I don't know what's up with that. Is it possible Michael did actually calibrate the RC32K clock for every firestorm, and we never actually overwrote the bootloader so it wasn't an issue? Do we have any untouched firestorms we could look at address 0xfe04 of?

prabaldutta, 2016-10-03:
Why are you using the RC oscillator for a BRG???  373 fail!  RC oscillators
have terrible tempco!

- Prabal

On Mon, Oct 3, 2016 at 11:58 AM, Brad Campbell <notifications@github.com>
wrote:

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

alevy, 2016-10-03:
On what I _think_ is an untouched Firestorm I'm reading `0x1d001a` from address `0xfe04`

alevy, 2016-10-03:
@prabaldutta The UART's baud rate generator is _not_ sourced from the RC32K, it's sourced from the CPU clock (which is the setup to use the DFLL).

@adkinsjd & @bradjc I'm not sure why we decided this might be related to the RC32K... is it possible the divider for the DFLL is off by a bit or something? Resulting in a frequency of about 44Mhz instead of 48Mhz?

bradjc, 2016-10-03:
`0x1d001a` differs from what we had (which was `0x1d0015`). It may be time to dig into the clock land again...

Closed 2016-10-14.

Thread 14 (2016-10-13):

Convert ltc output to uAh and check for i2c errors

bradjc, 2016-10-13:

nealjack, 2016-10-13:
What i2c errors are you talking about?

bradjc, 2016-10-14:
Mostly if the ltc2941 address was NAKed.

nealjack, 2016-10-15:
Note: what I added works when only the controller and power supply are on the backplane. Had issues last night with the radio module. Adding configuration writes to the ltcs in signpost_energy_init would cause the controller to freeze up. Assuming a yield that never got a callback.

Closed 2016-10-15.

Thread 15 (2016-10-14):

Power Supply Module: update paste layer

bradjc, 2016-10-14:
Modify the paste layer on the ICs to have a smaller square in the center of the pad instead of the entire pad.

ppannuto, 2017-03-10:
@nealjack did this get fixed on the current rev?

nealjack, 2017-03-10:
yeah it's on my list

nealjack, 2017-03-12:
So which ICs actually have too large squares on the paste layers? Why is it particular to the power module? It seems like a lot of our ICs have huge paste layers.

Closed 2017-03-12.

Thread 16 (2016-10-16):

Backplane RevB updates

ppannuto, 2016-10-16:
So far just nits but a place to collect things.
- [x] Add a space on silkscreen to write in an identifier (i.e. Backplane no. 12)
- [x] Move `R46` and `R47` to be near `R48`. (Or vice-versa and move the test points too)
- [x] ~Software resettable fuses for modules~
  - Moved to the power module's responsibility
- [x] ~TVS diodes on all module I/O ?~
  - I'm not convinced this is needed, can revisit if stuff actually breaks
- [x] ~Deal with USB Hub Reset problem~
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
   - Resolved by adding GPIO extender for reset line control. Debug backplane may still add PoR circuitry, but not really needed for signpost proper

adkinsjd, 2016-10-17:
I2C bypass jumpers in case the isolators aren't working

adkinsjd, 2016-10-20:
- [ ] Large annular rings around all mechanical holes!
- [ ] Don't route any traces near mechanical holes

bradjc, 2016-10-26:
[ ] All traces on middle layers?

adkinsjd, 2016-11-17:
A generally thicker, more sturdy pcb

bradjc, 2016-11-23:
If the PCB gets thicker, we have to keep in mind the through-hole parts and make sure they are still solderable.

ppannuto, 2017-03-06:
- [ ] replace GPIO extender package with version from debug backplane

brghena, 2017-03-06:
- [ ] Add GPIO extender to reset / monitor the USB hub

ppannuto, 2017-03-07:
- [ ] Validate all component heights are < 0.080" (for compat w/ thicker pcb)

ppannuto, 2017-03-07:
> All traces on middle layers?

Where are we at on this - superfluous or worth the effort? I kinda don't want to do it just because it'll take a while to do, but if it's worth it I will

brghena, 2017-03-07:
I think it's unnecessary

adkinsjd, 2017-03-07:
I think as long as you are especially careful to keep traces away from
screws and edges you are fine. The removal of internal module seals should
make this even less of an issue

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

ppannuto, 2017-03-08:
I think I've now addressed everything here.

Do we have other changes or additions to the backplane?

ppannuto, 2017-03-10:
- [ ] Connect the watchdog from controller to power module
   - [ ] @brghena update controller module in library to add watchdog pin
   - [ ] @nealjack update power module in library to add watchdog pin

nealjack, 2017-03-17:
- [ ] Step up the vbat+/- and vsol+- traces to at least 100mil

Closed 2017-06-26.

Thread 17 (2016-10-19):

Timer callbacks getting lost somehow (probably)

bradjc, 2016-10-19:
With watchdog timer firing at 250 ms, app watchdog timer firing at 30 s, and app timer firing at 6 s, every 235 s the app seemingly stops getting a callback for the 6 s app timer. 30 s the app watchdog fires and resets the MCU.

Disabling the HW watchdog and watchdog timer (the 250 ms one) seems to make this problem go away. Changing the app timer interval does not seem to have any effect.

bradjc, 2017-01-18:
Oooh this is what Branden was thinking of. Yeah hopefully this is fixed with the bug fix to virtual_alarm.rs.

ppannuto, 2017-03-01:
@bradjc is this still an issue?

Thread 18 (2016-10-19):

Microwave Radar PCB fixes

bradjc, 2016-10-19:
- Hole sizes too small for radar module
- TX/RX silkscreen backwards
- PCB board name label too small
- MSGEQ7 schematic
- SAM4L switching power supply doesn't work

ppannuto, 2016-10-19:
- Module silkscreen for `I2C_C` runs into the pin and cuts off, hard to read difference from `I2C_D`. Change to `SCL` and `SDA`.

bradjc, 2016-10-26:
Also need to fix the false positive issue, where there is noise (or something) on the IF pin and that leads to motion detection when nothing is happening.

ppannuto, 2017-07-18:
- [ ] Check that caps are on `VDDCORE` not `VDDOUT`

adkinsjd, 2017-09-30:
Fix the damn microwave radar hole sizes

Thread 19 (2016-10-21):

Radio module reliability

brghena, 2016-10-21:
We want to improve radio module reliability. This has two prongs: detecting errors and resetting cleanly
1. We want to be able to detect errors on the Nucleum and iM880B. For the Nucleum, the `ble_error` function seems like it should be able to do this. However, while testing I could not seem to get this function to be run... For the iM880, we should read its responses. The console `getauto` function can probably do this adequately. Upon detecting an error, the `app_watchdog_reset_app` function can be called to reboot the module.
2.  We want the radio board the reliably reset even if the Nucleum or iM880B have gotten into a bad state. The power gate on the Nucleum is toggled at start, getting it into a reliable state. Something needs to be done for the iM880B too. Using its power gate, however, seemed to lead to system problems and was being tested when the iM880 on my radio board gave up the ghost, leading to worries on my part that it might have been doing bad things for the board. @adkinsjd suggested there is a reset line that can be used instead.

adkinsjd, 2016-11-17:
This is fixed. Nulceum fixed by power gate. IM880B software reset.

Closed 2016-11-17.

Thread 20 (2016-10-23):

Summon demo app

brghena, 2016-10-23:
Thomas added a summon app which can be viewed at [j2x.us/signp](http://j2x.us/signp). This issue is for tracking updates that are needed for it. @tzachari
- [x] Add time and date to the `Controller` view
- [x] Add the UC Berkeley logo to the signpost
- [x] Either add the UCSD logo to the `Air Quality` view or rename to `UCSD Air Quality`
- [x] Make `SIGNPOST` name bigger. Might have to move it

ppannuto, 2016-10-23:
- [ ] Resolve mixed security content

The j2x url currently redirects to https rawgit, but the websocket uri isn't over secured websockets. Manually going to the http version of the rawgit page allows the websocket to connect, but this should be consistent.

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

brghena, 2016-10-23:
- [ ] the '2' in 'CO2' doesn't load right on android
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

bradjc, 2016-10-24:
- [ ] add controller energy to power supply box

Closed 2016-11-22.

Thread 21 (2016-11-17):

Fix i2c probing lines on the audio module so that you can really solder them.

adkinsjd, 2016-11-17:

brghena, 2017-01-26:
Fixed with rev C

Closed 2017-01-26.

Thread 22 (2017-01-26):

Controller Rev B Fixes

brghena, 2017-01-26:
List for tracking problems discovered with Rev B of the controller

 - [x] Swap C12 and C25 locations

brghena, 2017-01-27:
- [ ] Clearance on Edison mounting holes is insufficient
- [ ] Pull-up on LINUX_ENABLE_POWER is not working

ppannuto, 2017-02-14:
- [ ] Connect !BACKPLANE_RESET to a SAM4L

ppannuto, 2017-02-19:
- [ ] Label the usb ports on the *top* of the board

brghena, 2017-02-20:
- [ ] Better isolation for things touching the Linux power domain
- [ ] Mod_in/out pins for the Storage Master too

ppannuto, 2017-02-22:
- [ ] connect module i2c (and may as well do smbus while we're at it) pins to gpio inputs as well so controller can monitor

ppannuto, 2017-02-22:
- [ ] PPS should also be input to controller (and storage master while we're at it)

brghena, 2017-03-07:
- [ ] Interrupt pin to the Edison

brghena, 2017-03-07:
- [ ] Interrupt pin from Storage Master to Controller

adkinsjd, 2017-03-23:
Individual reset buttons for each MCU

adkinsjd, 2017-04-25:
- [ ] Add POR chips for both SAM4Ls. Backplane power nets are too large to fulfill necessary voltage rise rates, meaning SAM4Ls need POR.

Closed 2017-06-28.

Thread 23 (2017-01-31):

Debug Backplane Fixes

adkinsjd, 2017-01-31:
[ ] Switch module 1 and 0 programming silkscreen (light is still correct)

adkinsjd, 2017-01-31:
- [ ] Probably should put default off resistors on the debug LEDs

adkinsjd, 2017-01-31:
- [ ] Nit - put the programming signals in order
 - [ ] Move silkscreen out to accommodate a knurled knob

adkinsjd, 2017-01-31:
- [ ] A big 5V warning. maybe  a protection circuit

ppannuto, 2017-02-14:
Moving from #26 here:

 - [ ] Add LED for fake radio module.

ppannuto, 2017-02-14:
- [ ] Deal with USB Hub Reset problem

brghena, 2017-02-14:
## USB Hub Reset

Reboot: Hub still good
Power cycle (with ten seconds physically powered off): Hub still good

I'm guessing just asserting BackplaneReset at boot will be sufficient

bradjc, 2017-02-20:
[ ] Doesn't say "Signpost"
[ ] Module 0, Module 1, Controller font are not the same size.
[ ] "MEM" -> "Storage"
[ ] What is the empty programming switch position for?
[ ] Move the JTAG header to the top of the board.

brghena, 2017-02-20:
- [ ] No easily accessible ground post for probing

adkinsjd, 2017-02-20:
Literally every screw? Or the 4 gnd testpoints at various spots on the
board?

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

brghena, 2017-02-20:
Sorry, first message was unclear. I edited it to include the real intent, which is the ground connections on oscilloscope leads, which are too big and would short to other pins on the 0.1" headers and cannot latch on to round-headed screws.

ppannuto, 2017-02-20:
I'm a fan of the ground bar-like thing. Draw a rectangular poly of exposed ground metal along the edge so that leads can just clip to the pcb.

adkinsjd, 2017-02-20:
You should unscrew one of the feet for now

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

bradjc, 2017-02-21:
- [ ] Mod0 and Mod1 debug headers should be identical.

brghena, 2017-02-21:
- [ ] Enable programming of modules even without a valid controller app

Currently, when you just plug a module in to the debug backplane, you can't program it unless the controller has disabled isolation for that module. One solution to this would be powering modules explicitly even when the programming switch is set to it.

bradjc, 2017-02-21:
- [ ] Bigger !RESET button switches.

adkinsjd, 2017-02-21:
I am actually pretty strongly against this unless you can enable and
disable it strictly when the jlink is actually flashing. I think that a
module staying on when the controller wants it off would be more
problematic in the long run, and I don't think requiring turning the switch
to be selecting none of the boards is viable, as you would inevitably
forget.

There is probably a jlink signal that could switch on/off for the duration
of programming that could make this happen though.

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

ppannuto, 2017-02-21:
Yeah, the whole flashing / dev story needs a little work. Currently we have
the annoying problem where flashing one quite often tends to leave other
boards in the "i2c lines stuck low until reset" state that the SAM4L likes
to get into.

The big hammer is obviously to put all boards into reset during a flash,
power on the target module forcefully, and then take things out of reset -
but that could be obnoxious in practice. I'd rather understand this buggy
i2c state

On Tue, Feb 21, 2017 at 3:37 PM Joshua Adkins <notifications@github.com>
wrote:

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

adkinsjd, 2017-02-21:
The buggy I2C state is a separate issue, which I worry we will never be
able to fix because it's a chip bug (although the first thing I would try
is adding a few extra jlink resets at the end of the flashing script).

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

ppannuto, 2017-02-21:
Yeah.. adding jlink resets won't help. It's _other_ SAM4Ls that aren't
being flashed that tend to hold low it in my experience.

On Tue, Feb 21, 2017 at 4:00 PM Joshua Adkins <notifications@github.com>
wrote:

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

adkinsjd, 2017-02-21:
Really? That's not what I've found. Usually if I hit the reset button on
the one I'm flashing it works.

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

adkinsjd, 2017-02-21:
I just assumed something about pressing the button reset the chip
differently

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

ppannuto, 2017-02-21:
Often is too strong. I'd say.. 75% of the time the one I flashed, maybe 25%
of the time another chip on the network somewhere. But at this point I'm
just in the habit of resetting all of them, so my empirical evidence isn't
great. Maybe I can unlearn that habit.

On Tue, Feb 21, 2017 at 4:04 PM Joshua Adkins <notifications@github.com>
wrote:

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

bradjc, 2017-02-21:
My experience is basically 100% of the time it's the fault of the one I just flashed and that resetting the just flashed module fixes the issue.

adkinsjd, 2017-02-21:
Have we tried just running JLinkExe and resetting a few times to see if
that fixes it?

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

ppannuto, 2017-02-21:
- [ ] Master reset button that resets everything

ppannuto, 2017-02-22:
- [ ] Another USB hub upstream of the FTDIs so that you can just plug in one USB cable

nealjack, 2017-02-22:
[ ] - Radio Module clock unstable - gpios don't work on cold boot

ppannuto, 2017-03-07:
- [ ] Add GPIO extender to reset / monitor the USB hub. Set to address 3

ppannuto, 2017-04-10:
- [ ] power metering jumpers for modules/controller
 - [ ] eeprom chip

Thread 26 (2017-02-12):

Debug Backplane Updates

bradjc, 2017-02-12:
- [ ] Add LED for fake radio module.

ppannuto, 2017-02-14:
Duplicate issue. Closing in favor of #23.

Closed 2017-02-14.

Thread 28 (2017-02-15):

Edison toFlash.tar.gz firmware fails to reboot

cxbrooks, 2017-02-15:
The signpost/software/edison/toFlash.tar.gz  image seems to not work for me.

I installed git lfs:

```
sudo port install git-lfs
git clone https://github.com/lab11/signpost.git
cd signpost/software/edison                                                                            
git lfs track toFlash.tar.gz                                                                            
git lfs pull toFlash.tar.gz
```

The image size seems correct and the file seems OK:

```
bash-3.2$ ls -l toFlash.tar.gz                                                                                    
-rw-r--r--  1 cxh  staff  158338761 Feb 15 11:39 toFlash.tar.gz                                                   
bash-3.2$ tar -ztvf *.gz | head                                                                                   
drwxrwxrwx  0 root   root        0 Nov 22 01:15 toFlash/                                                          
-rw-rw-rw-  0 root   root  4194304 Nov 22 01:09 toFlash/edison_ifwi-dbg-01-dfu.bin                                
-rw-rw-rw-  0 root   root  4194304 Nov 22 01:09 toFlash/edison_ifwi-dbg-00-dfu.bin                                
-rw-rw-rw-  0 root   root      742 Nov 22 01:09 toFlash/filter-dfu-out.js                                         
-rw-rw-rw-  0 root   root  4194468 Nov 22 01:09 toFlash/edison_ifwi-dbg-01.bin                                    
-rw-rw-rw-  0 root   root  4194304 Nov 22 01:09 toFlash/edison_ifwi-dbg-03-dfu.bin                                
drwxrwxrwx  0 root   root        0 Nov 22 01:09 toFlash/helper/                                                   
drwxrwxrwx  0 root   root        0 Nov 22 01:09 toFlash/helper/images/                                            
-rw-rw-rw-  0 root   root   315857 Nov 22 01:09 toFlash/helper/images/Edison-arduino-blink-led.png                
-rw-rw-rw-  0 root   root   298970 Nov 22 01:09 toFlash/helper/images/Edison-breakout-board.png                   
bash-3.2$
```
When I use the Intel Edison Setup Application to install this file, I see it validate the image, and then there is a message about dfs (not sure about that) and then I get a window that says:

> Uh-oh! Your Intel Edison did not update, This is likely because your Intel Edison did not reconnect properly, You'll need to download the newer firmware and manually update the Intel Edison Board. Detailed instructions are at https://software.intel.com/en-us/flashing-your-firmware-edison

I'm able to download the latest image from Intel and install that.

Should signpost/software/edison/toFlash.tar.gz work on an bare Intel Edison that is just connected to a [SparkFun Base Kit for Intel® Edison KIT-14105](https://www.sparkfun.com/products/14105) ?

adkinsjd, 2017-02-15:
I have never used the Edison Setup Application.

Usually to install our images, we unpack the tar ball, then run the
flashall.sh script from terminal.

This takes a few minutes, and doesn't work every time, but usually works
within 1-3 tries. If you have problems and are in the DOP center, Neal or I
can look at it with you later today.

On Wed, Feb 15, 2017 at 12:08 PM, Christopher Brooks <
notifications@github.com> wrote:

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

cxbrooks, 2017-02-16:
Awesome, that worked.

Follow t[he manual flashing instructions](https://software.intel.com/en-us/flashing-firmware-on-your-intel-edison-board-mac-os-x)

Assuming brew is already installed

```
brew install dfu-util coreutils gnu-getopt
cd signpost/software/edison/
tar -zxf toFlash.tar.gz
cd toFlash
./flashall.sh
```

In the Finder, unmount the Edison partition

Be sure to be plugged in to the otg port, not the console port of the [SparkFun Base Kit for Intel® Edison KIT-14105](https://www.sparkfun.com/products/14105)

Below is a sample run:

```
bash-3.2$ ./flashall.sh
Using U-Boot target: edison-blankcdc
Now waiting for dfu device 8087:0a99
Please plug and reboot the board
Flashing IFWI
Copying data from PC to DFU device
Copying data from PC to DFU device
Flashing U-Boot
Download        [=========================] 100%       237568 bytes
Flashing U-Boot Environment
Copying data from PC to DFU device
Flashing U-Boot Environment Backup
Copying data from PC to DFU device
Rebooting to apply partition changes
Now waiting for dfu device 8087:0a99
Flashing boot partition (kernel)
Copying data from PC to DFU device
Flashing rootfs, (it can take up to 5 minutes... Please be patient)
Copying data from PC to DFU device
Rebooting
U-boot & Kernel System Flash Success...
Your board needs to reboot to complete the flashing procedure, please do not unplug it for 2 minutes.
bash-3.2$
```
My notes are at https://www.icyphy.org/accessors/wiki/Notes/Edison

I'm closing this because I was able to flash the signpost image.

ppannuto, 2017-02-16:
I'm going to reopen this as a reminder to come back and improve the documentation at some point

Closed 2017-02-21.

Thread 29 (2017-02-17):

Ambient Rev C fixes

brghena, 2017-02-17:
Tracking things to fix for the next revision:

- [x] Grounded mounting holes
- [x] Silkscreen labels on header pins
- [ ] ~~Change to 0402 ferrite bead~~
- [x] Remove extraneous pressure sensors. We can't even purchase all of them anymore

ppannuto, 2017-07-18:
- [ ] Check that caps are on `VDDCORE` not `VDDOUT`

Closed 2017-10-16.

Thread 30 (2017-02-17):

Updates for the Edison image

cxbrooks, 2017-02-17:
Below are some updates I'd like to see in the Edison Image:

- [x] Install Node and npm.  Node 6.9.5 is preferred.  See [Edison Node Notes](https://www.icyphy.org/accessors/wiki/Notes/EdisonNodeNotes).  Accessors will require Node.

- [x] Set the date.  When I installed the default Intel-provided image, it seemed like the date was set properly, or at least close to the current time.  I ran into problems using wget and npm because the date was set to 1/1/2000 and the certs were not valid.

- [x] Set up a sbuser with the appropriate keys, see [Set up the sbuser account on the Edison](https://www.icyphy.org/accessors/wiki/Notes/Edison#SetUpSbuser).  Downloading accessors requires the sbuser account.

There is no big rush on these, just when we get around to updating the Edison image, it would be good to consider these.

nealjack, 2017-02-17:
Great. This list is very useful. I'm actually working on making a more
complete image right now. If you think of any other packages you want
installed by default, please add them.

On Feb 17, 2017 11:36 AM, "Christopher Brooks" <notifications@github.com>
wrote:

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

ppannuto, 2017-02-19:
These, in order:

 - [ ] apt install python3 python3-pip
 - [ ] apt install libffi-dev libssl-dev
 - [ ] pip3 install --upgrade pip
 - [ ] pip3 install --upgrade setuptools
 - [ ] pip3 install python-periphery cryptography

ppannuto, 2017-02-19:
- [ ] apt install nfs-common

Related: mounting my machine's dev folder over nfs while working on the python edison stuff has made for a really nice working setup. This is just the client side and won't mount anything by default, so should be a perfectly sane/reasonable thing to include

ppannuto, 2017-02-19:
- [ ] give the edison user access to the I2C device

I recommend:
```
sudo chgrp netdev /dev/i2c-*
sudo chmod g+rw /dev/i2c-*
```

cxbrooks, 2017-02-19:
- [ ] (Optional) Write documentation about how the image was created.
- [ ] (Very optional) Create script that creates the image.

nealjack, 2017-02-20:
@cxbrooks in README.md there is a [link](https://jakehewitt.github.io/custom-edison-image/) to the process for building a debian image for the Intel Edison.

nealjack, 2017-02-20:
- [ ] udev rule for user i2c

ppannuto, 2017-02-20:
- [ ] set up https://github.com/lab11/signpost/blob/master/software/edison/support/edison-i2c.sh to run on every boot

ppannuto, 2017-02-22:
- [ ] apt install links

This is a text based browser that will give people a fighting chance of being able to navigate a captive portal.

ppannuto, 2017-03-01:
The only unchecked boxes are erpc stuff, but pretty sure @nealjack said that made it in - while it may need some love at some point in the future, that feels like a separate issue. The edison image as it currently stands is in a pretty good place.

Closed 2017-03-01.

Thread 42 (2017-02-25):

Generate mbedtls randomness from hardware RNG

alevy, 2017-02-25:
I believe the current implementation relies solely on CPU timing for randomness (specifically for the ECDH key exchange). That's a problem because it's insecure _and_ because we don't get to use our fancy TRNG driver for the SAM4L.

Instead, the signpost user libs can simply define

```c
#define MBEDTLS_ENTROPY_HARDWARE_ALT

int mbedtls_hardware_poll( void *data,
                           unsigned char *output, size_t len, size_t *olen );
```

to call the underlying TRNG driver.

nealjack, 2017-02-25:
I've already written an [entropy abstraction](https://github.com/lab11/signpost/blob/master/software/apps/libs/signpost_entropy.c#L13) that uses the TRGN to as a source to seed the mbedtls PRNG.

alevy, 2017-02-26:
@nealjack Oh yeah, I think that works. I was looking through mbedtls, and there appears to be a supported way to do basically the same with a `#define` and magically named function you're meant to provide, but this seems better.

Closed 2017-02-26.

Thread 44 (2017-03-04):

Are you considering to use newer kernel on Edison?

andy-shev, 2017-03-04:
Just wondering if you are considering to switch to vanilla kernel at some point.

bradjc, 2017-03-06:
I'm not sure what you mean by "vanilla", but we would _love_ to use a newer kernel. If we could get to 4.5+ we could natively support the CC2520 that we have on some of our boards.

andy-shev, 2017-03-06:
[Vanilla](https://en.wikipedia.org/wiki/Linux_kernel#Development_model) is a standard name of upstream available kernel.

v4.11-rc1 supports almost everything important on Intel Edison out-of-the box. The progress on it is described on [community wiki](https://edison.internet-share.com/wiki/Using_a_vanilla_Linux_kernel_with_Intel_Edison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).

ppannuto, 2017-03-06:
@nealjack thoughts? It'd be great to jump up, but the missing power unit and power button support (esp the latter) give me some pause.

andy-shev, 2017-03-06:
@ppannuto
To clarify a bit. There are two power related MCUs inside Atom SoCs:

1. PMU (in some it's called PMC), which takes care of South Complex devices (the driver _is_ in upstream!).
2. Power Unit is another one which controls North Complex devices, that are not used on Intel Edison anyhow (AFAIR), there is a debug support in upstream which allows you to see (read) the current state of those devices. That's why the support of it is low priority.

Regarding power button, I would ask Ingo Molnar or Thomas Gleixner to apply rest of the patches which are needed to enable it (actually one patch is needed) to next v4.11-rcX. I can't promise it will go to it, so v4.12 is for sure.

Don't hesitate to ask any question either by email (public mailing lists, Intel community forums, etc.) or thru GitHub.

nealjack, 2017-03-06:
When I find some time this week, I'll give the new kernel a try. I wasn't aware Intel was still maintaining the Edison kernel. I built the current Signpost image from what is available from [here]( https://downloadcenter.intel.com/download/25028/Intel-Edison-Board-Software-Package?v=t), and used a Debian rootfs.

andy-shev, 2017-03-06:
@nealjack
Even that is old one. Latest official BSP v3.5 is dated 6.06.2016. Yeah, it has v3.10.98 based kernel, but at least a bit newer than initial one.

My kernel is unofficial. I'm doing this most likely as a hobby because I like the hardware and platform.
Same regarding U-Boot support and upstreaming.

andy-shev, 2017-03-20:
Power Button support is in v4.11-rc3 (and so in my branch here on GitHub).

vsobolyev, 2017-03-28:
Hi @andy-shev,
I'd really wanted to try and use your kernel because of the SPI driver and DMA support.
Is there a way of building your kernel using the BSP v3.5 is dated 6.06.2016? I want this mostly because it seems easier to me to include new modules and try them through patches and bitbake.

andy-shev, 2017-03-28:
@vsobolyev
It would be really appreciated, though I have 0 experience with Yocto (bitbake), so I dunno how to answer to your question.

vsobolyev, 2017-03-29:
@andy-shev
Things were breaking as I was writing you hehe.
Thanx for the info. Will give try to the usual build later on.

andy-shev, 2017-03-29:
@vsobolyev
You are welcome. One remark, it might be better to use issue tracker in my repository to avoid noise here. Since there is no automated way to move some comments as new issue in other repository, feel free to create one an put there comments that matters.

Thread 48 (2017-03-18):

Module Time Sync

adkinsjd, 2017-03-18:
To have a hope of tight time synchronization, modules are probably going to need to wire PPS to a timer/counter (TC) pin, so that it can trigger a counter start. This might not really help, because the SAM4L doesn't have a 32bit counter that can take an external trigger anyways, but it's something to think about.

prabaldutta, 2017-03-20:
Why couldn't you connect it to a capture line on a free running timer?

- Prabal

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

adkinsjd, 2017-03-20:
The only 32bit free running timer peripheral does not have any way to
interface with external i/o in hardware, and its fastest clock source is
32khz. I was going to test full accuracy of time-stamping events in
software using this timer today.

I expect to achieve synchronization in the 10s of uS using this method,
which is probably good enough for something like localizing an audio
source, but still much worse than our original expectation of
synchronization given the accuracy of the pps line.

On Mar 20, 2017 7:44 AM, "prabaldutta" <notifications@github.com> wrote:

Why couldn't you connect it to a capture line on a free running timer?

- Prabal

On Saturday, March 18, 2017, Joshua Adkins <notifications@github.com> wrote:

> To have a hope of tight time synchronization, modules are probably going
> to need to wire PPS to a timer/counter (TC) pin, so that it can trigger a
> counter start. This might not really help, because the SAM4L doesn't have
a
> 32bit counter that can take an external trigger anyways, but it's
something
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
lLeQVFRWu6WIw1NwqF5dGFwks5rm2Z7gaJpZM4MhTAW>
> .
>

—
You are receiving this because you authored the thread.
Reply to this email directly, view it on GitHub
<https://github.com/lab11/signpost/issues/48#issuecomment-287780626>, or mute
the thread
<https://github.com/notifications/unsubscribe-auth/AGIJULATo3Lyead3X38Gx3xfTzJUVTWpks5rnpC4gaJpZM4MhTAW>
.

prabaldutta, 2017-03-20:
Wow...that's interesting and a bit disappointing that the MCU is missing
this pretty basic functionality.  I'm surprised that there isn't a 32-bit
timer block that can be configured to be free running and that also gives
you a capture line.

- Prabal

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

adkinsjd, 2017-03-20:
Yeah, I was pretty shocked. Usually you can at least chain two 16bit timers
together in hardware, and I can't even find a way to do that.

I might resort to running our synchronization evaluation code on the
cc2538, but I haven't looked into it much yet.  Hopefully that would at
least allow us to demonstrate the capabilities of the platform, even if
most of the modules we currently have can't achieve that accuracy.

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

prabaldutta, 2017-03-20:
Probably not a bad idea.  Our module selection kinds undercuts the basic
claim.

It might be useful to just do this on some third-party module that runs its
own ecosystem (e.g. mbed, Arduino, TI, etc.) to demonstrate both the timing
and the modular compatibility.

- Prabal

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

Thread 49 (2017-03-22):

Power Module Rev D Fixes

nealjack, 2017-03-22:
- [ ] U19 pin 1 indicator
- [ ] Better precision resistors for solar charger divider (Input and output regulation)
- [ ] More space monitors and sense resistors
- [ ] More space around charger/regulators
- [ ] U27 wrong package
- [ ] D3 wrong package
- [ ] Add reset button on watchdog

brghena, 2017-03-22:
Before you spin Rev D, it would be good to check if the watchdog firing actually turns off and back on the power rails correctly. (Probably a deadbugged chip and some wires)

nealjack, 2017-03-22:
U27 is the watchdog - so I don't have a good way

nealjack, 2017-03-22:
- [ ] VSOL- must be connected to VBAT-. Watchdog only shuts off battery connection to ground, solar panel could still power device. Change charger GND connections to VSOL-/VBAT-.

brghena, 2017-04-07:
- [ ] Think about Load Switches on a per module basis

brghena, 2017-10-10:
- [ ] WHY IS THE RESET BUTTON SO HARD TO PRESS??

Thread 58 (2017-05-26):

RF Spectrum A Issues

adkinsjd, 2017-05-26:
- [ ] R8 and C7 Labels are switched (which is bad if you want a working regulator)

ppannuto, 2017-07-18:
- [ ] Check that caps are on `VDDCORE` not `VDDOUT`

adkinsjd, 2017-07-18:
This isn't a sam4L...

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

ppannuto, 2017-07-18:
Yeah.. sorry, got trigger happy, I'd already deleted that comment

On Tue, Jul 18, 2017 at 3:06 PM Joshua Adkins <notifications@github.com>
wrote:

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

brghena, 2017-10-10:
- [ ] Add a ground debug pin (so that the other pins have something to be referenced against)

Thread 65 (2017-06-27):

Backplane Rev C Errata

ppannuto, 2017-06-27:
- [ ] USB !BUSPWR is wrong: Currently tied to GND, which states that the hub and all downstream devices are powered from the upstream port. Should be tied high, stating that the hub has an "external" power supply. In both modes, the hub still will perform overcurrent and poweroff protections.
   - Symptom: This limits the hub to 500mA max total draw, and each port has a minimum 100mA allotment (USB spec), so the hub disables higher ports (cannot use USB in Module 5 or Module 7 slot)
    - Remedy: Cut trace at pin 10 (!BUSPWR) and short pins 10 and 9.

ppannuto, 2017-07-13:
- [ ] Between power module and backplane isolation circuitry, something needs to protect against shorts.
   - Currently, the power module has a limiter downstream of the regulator, which protects the regulator by limiting to no more than 2A (?) sustained draw. The backplane module power switches are rated for 1.5A (?), so shorting a module will cause the isolation to blow.

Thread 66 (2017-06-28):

Controller Rev D todos

brghena, 2017-06-28:
- [ ] Better isolation for things touching the Linux power domain
- [X] PPS connection to Storage Master
- [X] Output Enable pulldown on logic level converter
- [ ] `PWRBTN#` net needs isolation from SAM4L. Doesn't currently allow Edison to run without powering the SAM4Ls
- [ ] Keep more space around Edison mounting holes

ppannuto, 2017-07-18:
- [ ] Check that caps are on `VDDCORE` not `VDDOUT`

nealjack, 2017-07-19:
- [ ] add debug pinout for modstorage_out/in

brghena, 2017-10-10:
- [ ] Can we fit GND and TX pins for debugging after breaking the header off

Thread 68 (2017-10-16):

Ambient RevD Errata

ppannuto, 2017-10-16:
- [ ] Move temperature sensor off of ground plane

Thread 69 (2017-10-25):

Possible Reset Clock Issues

adkinsjd, 2017-10-25:
I am experience a problem on the microwave radar board where spurious resets occur if the clock in tock is set to 16MHz. Touching the reset line/adding any capacitance seems to solve the issue. Notable changing the clock seems to change the pull up resistance on the SAM4L from 30kohm to 25kohm. This problem is unresolved - clocks should be set to 48MHz to not experience the problem.

We tried to solve the problem by writing the PPCR register of the SAM4L to 0x1FF instead of 0x1FE to "enable the reset pullup". That seems to disable the reset pullup instead and did not solve the issue.

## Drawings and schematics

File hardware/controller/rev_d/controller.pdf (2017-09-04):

# Headers

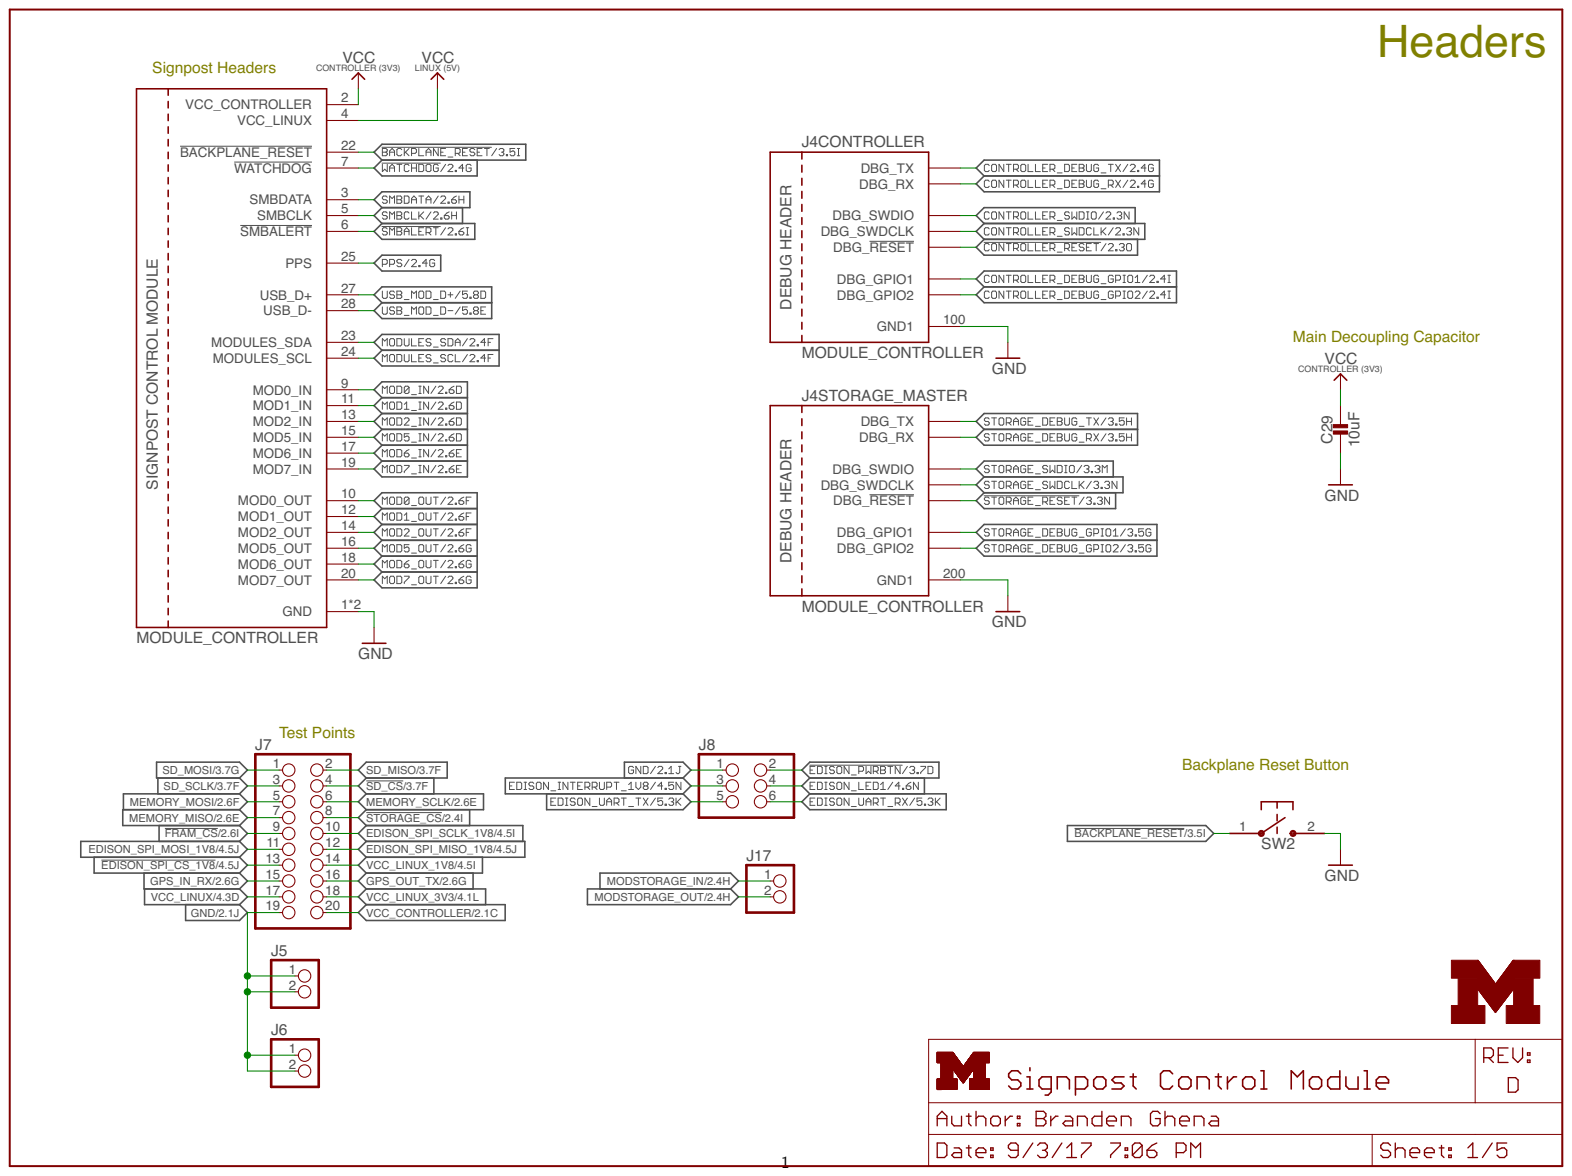
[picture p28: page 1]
Test Points; Backplane Reset Button; Signpost Headers; SIGNPOST C; ONTROL M; ODULE; MODULE_CONTROLLER; GND; 10uF GND; VCC_CONTROLLER; 2 VCC_LINUX 4; SMBDATA; 3 SMBCLK 5; MOD0_IN; 9 MOD1_IN 11 MOD2_IN 13 MOD5_IN 15 MOD6_IN 17 MOD7_IN 19 MOD0_OUT; 10 MOD1_OUT 12 MOD2_OUT 14 MOD5_OUT 16 MOD6_OUT 18 MOD7_OUT 20; MODULES_SDA; 23 MODULES_SCL; 24 USB_D+; 27 USB_D-; 28 PPS; 25 SMBALERT; 6 BACKPLANE_RESET; 22 WATCHDOG 7; C29 VCC CONTROLLER (3V3); J4CONTROLLER; GND1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

VCC LINUX (5V) VCC CONTROLLER (3V3)

DEBUG HEADER

Main Decoupling Capacitor

# RSTU3

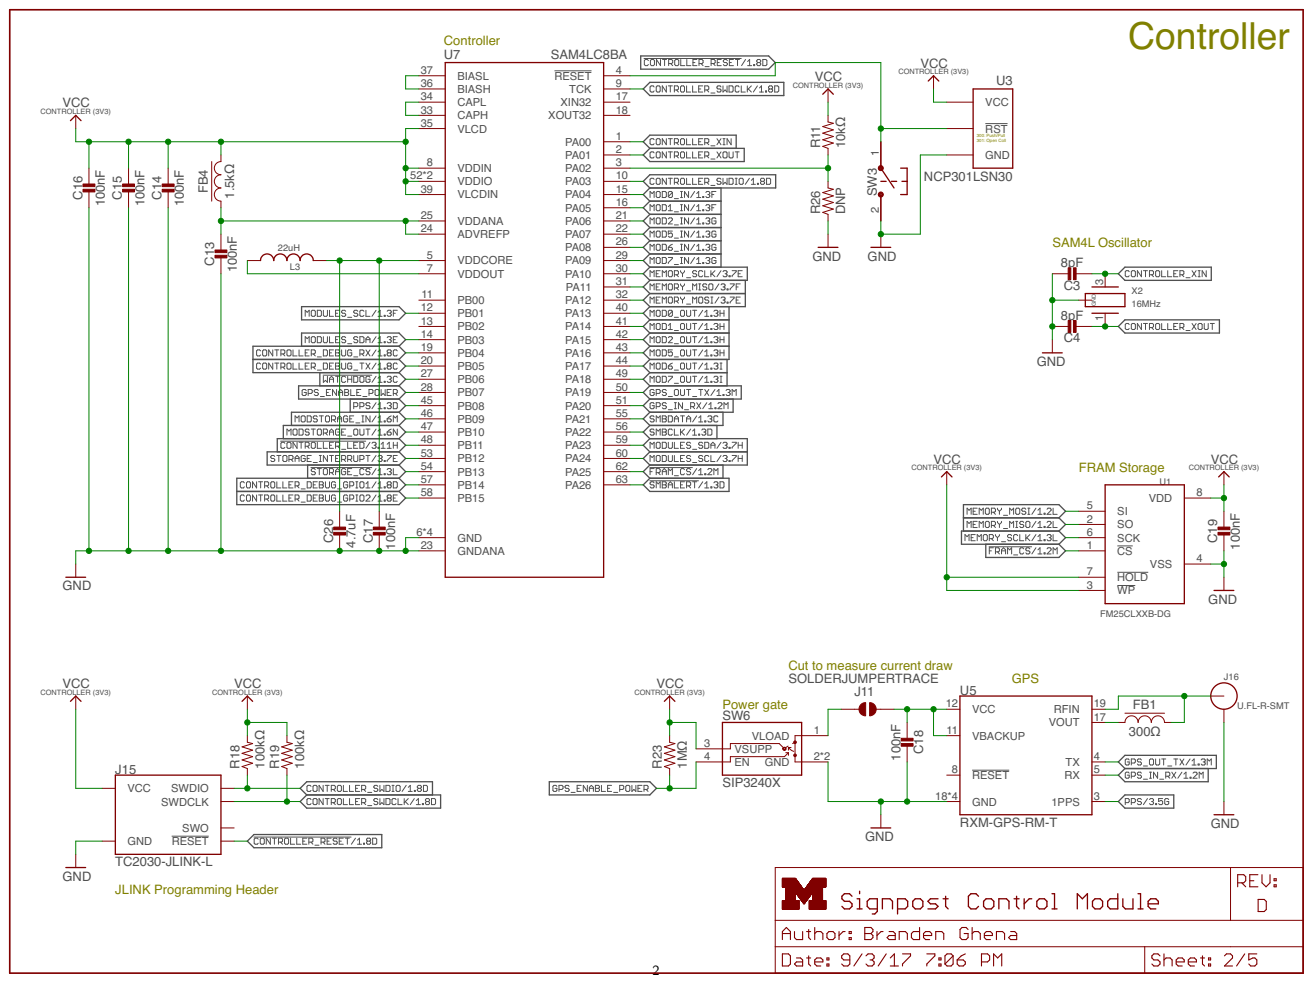
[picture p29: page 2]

R11 VCC CONTROLLER (3V3) VCC CONTROLLER (3V3)

300: Push/Pull 301: Open Coll
GND

Cut to measure current draw
SOLDERJUMPERTRACE

# Storage Master

# RSTU4

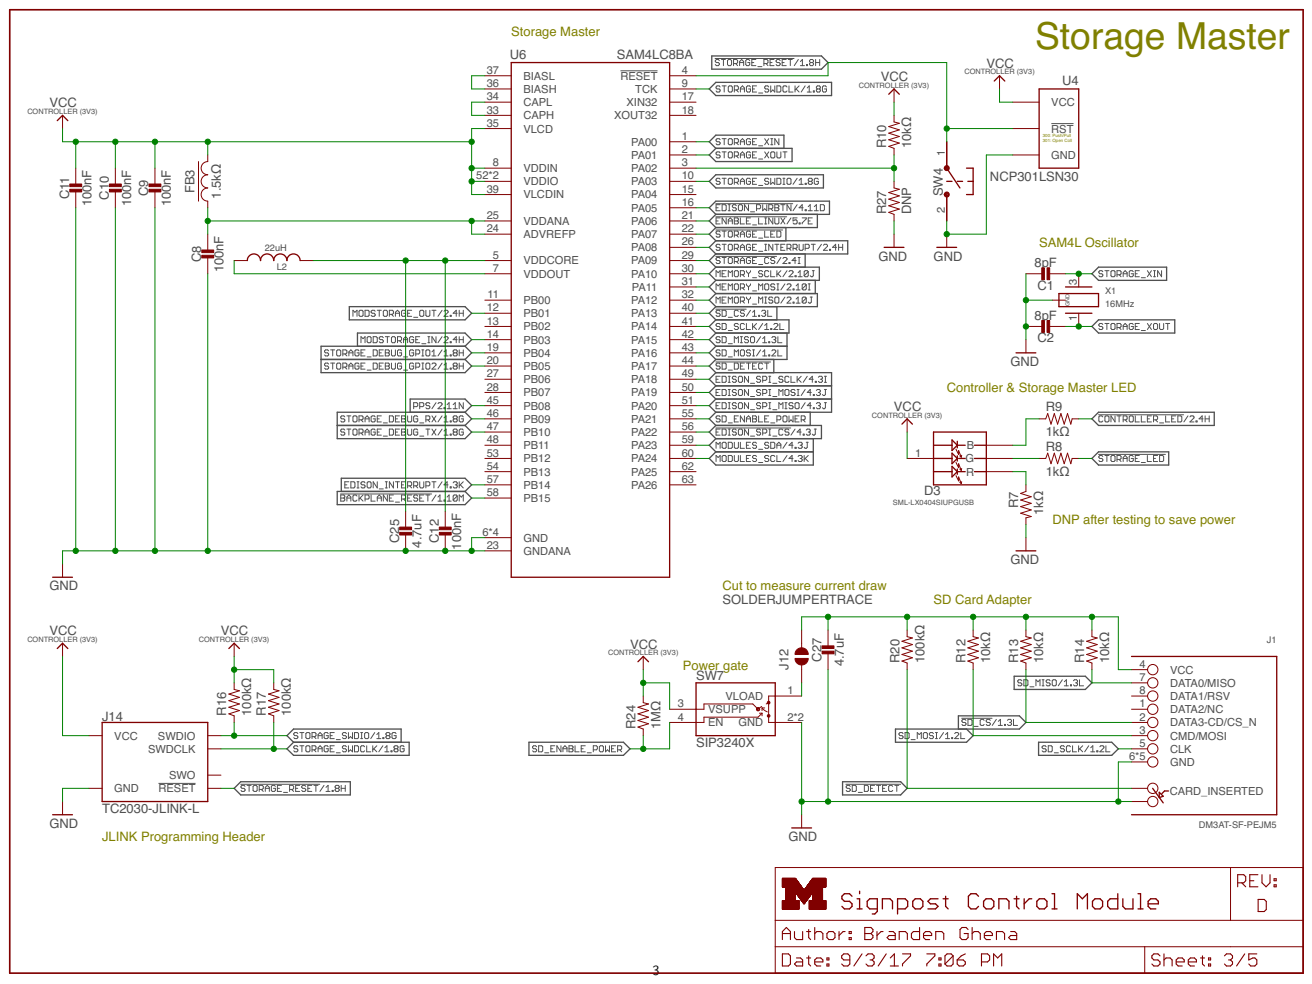
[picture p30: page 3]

300: Push/Pull 301: Open Coll
GND

Controller & Storage Master LED

DNP after testing to save power

Cut to measure current draw
SOLDERJUMPERTRACE

# Edison

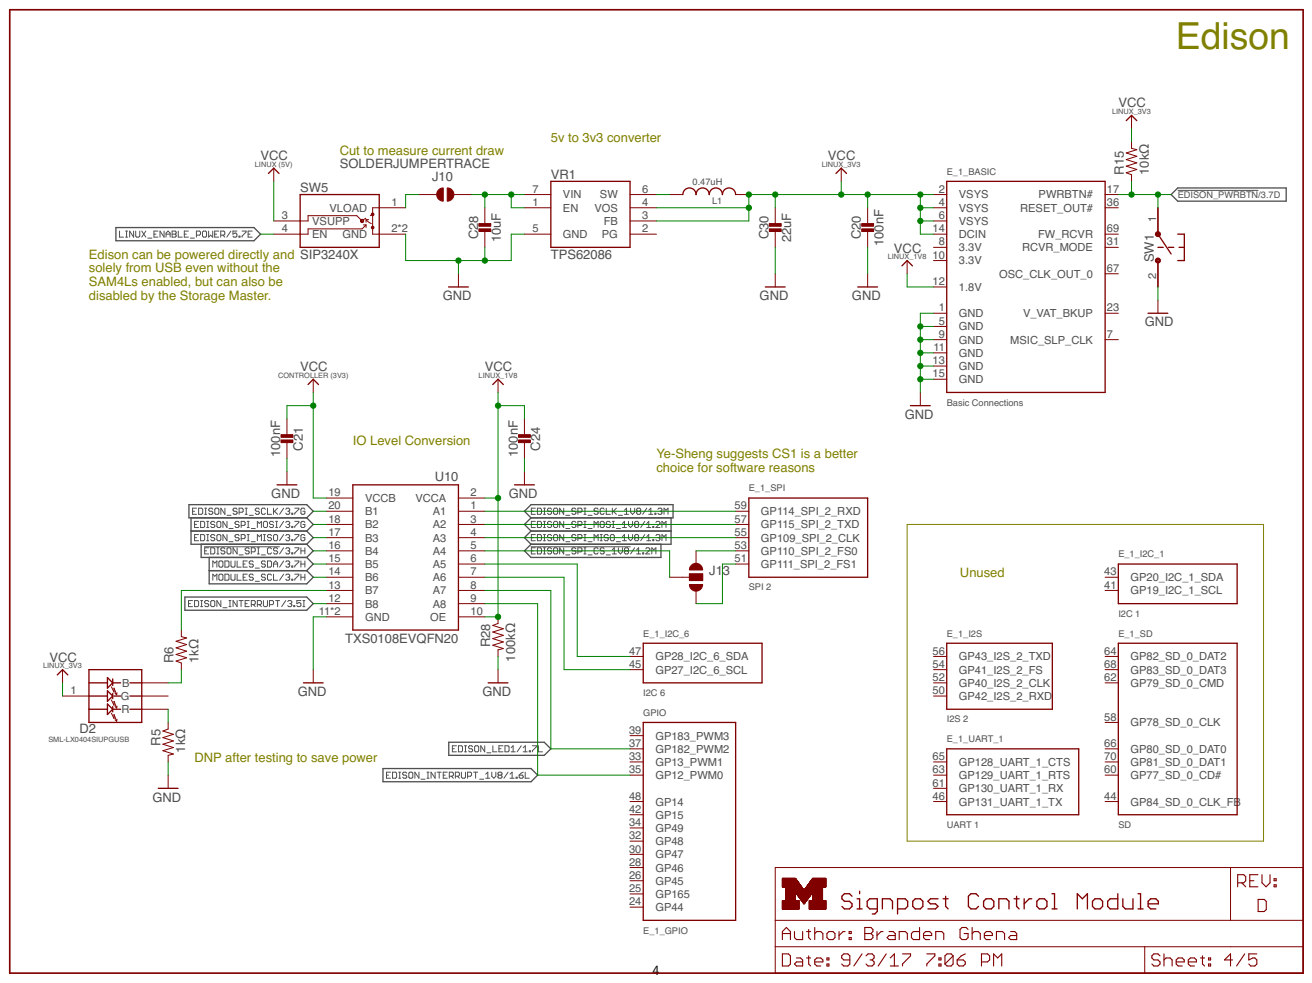
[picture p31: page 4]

Cut to measure current draw
SOLDERJUMPERTRACE

Edison can be powered directly and
solely from USB even without the SAM4Ls enabled, but can also be

disabled by the Storage Master.

Ye-Sheng suggests CS1 is a better choice for software reasons

DNP after testing to save power

# USB

# VCC LINUX (5V) R²⁵

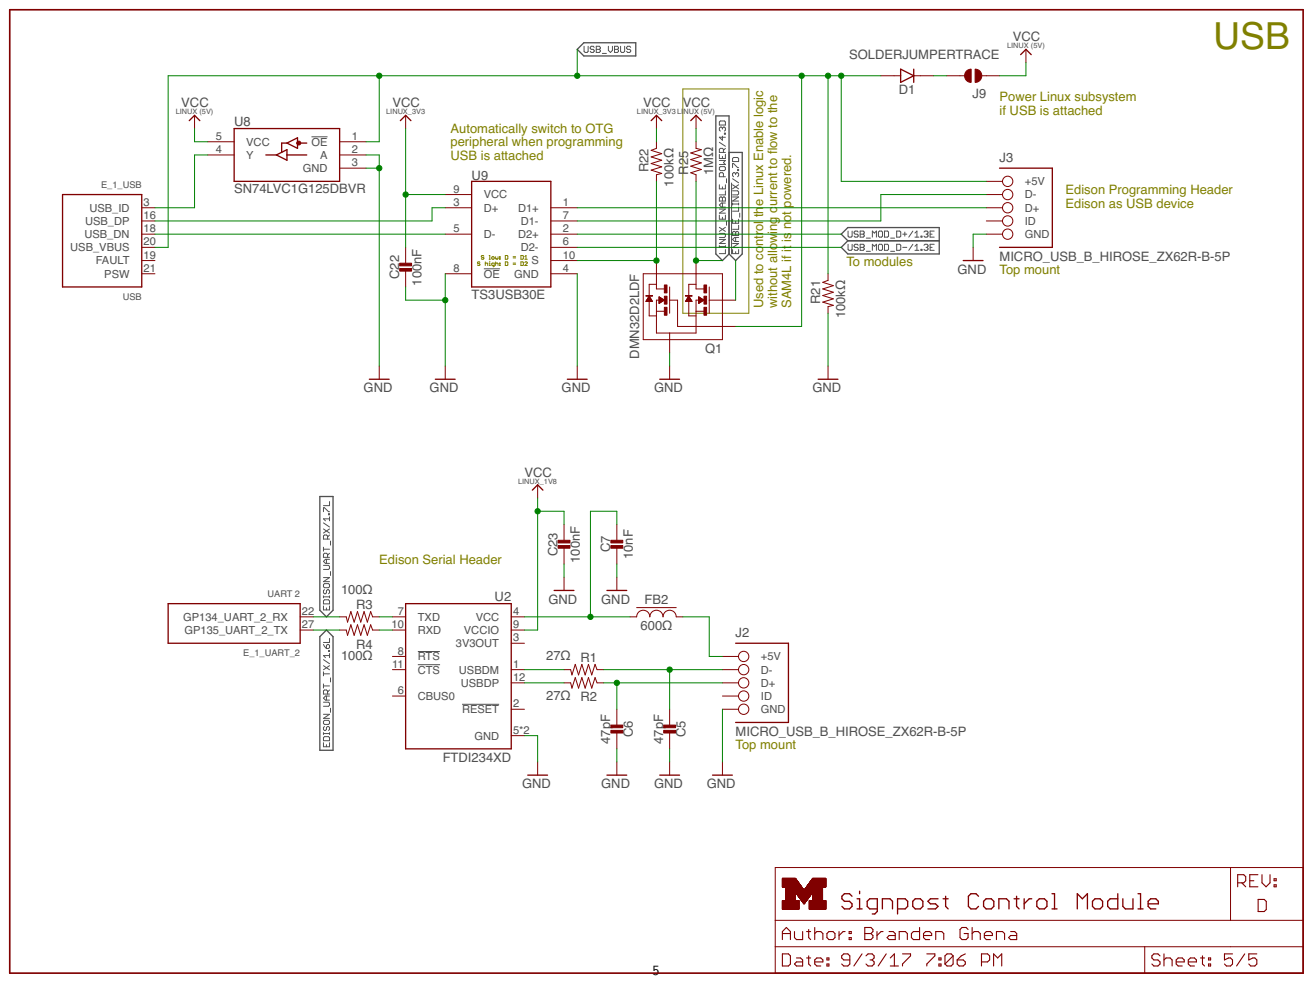
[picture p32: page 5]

Used to control the Linux Enable logic without allowing current to flow to the SA

Power Linux subsystem
if USB is attached

Automatically switch to OTG
peripheral when programming
USB is attached

M4L if it is not powered.

Edison Programming Header Edison as USB device

## Top and Bottom Layers

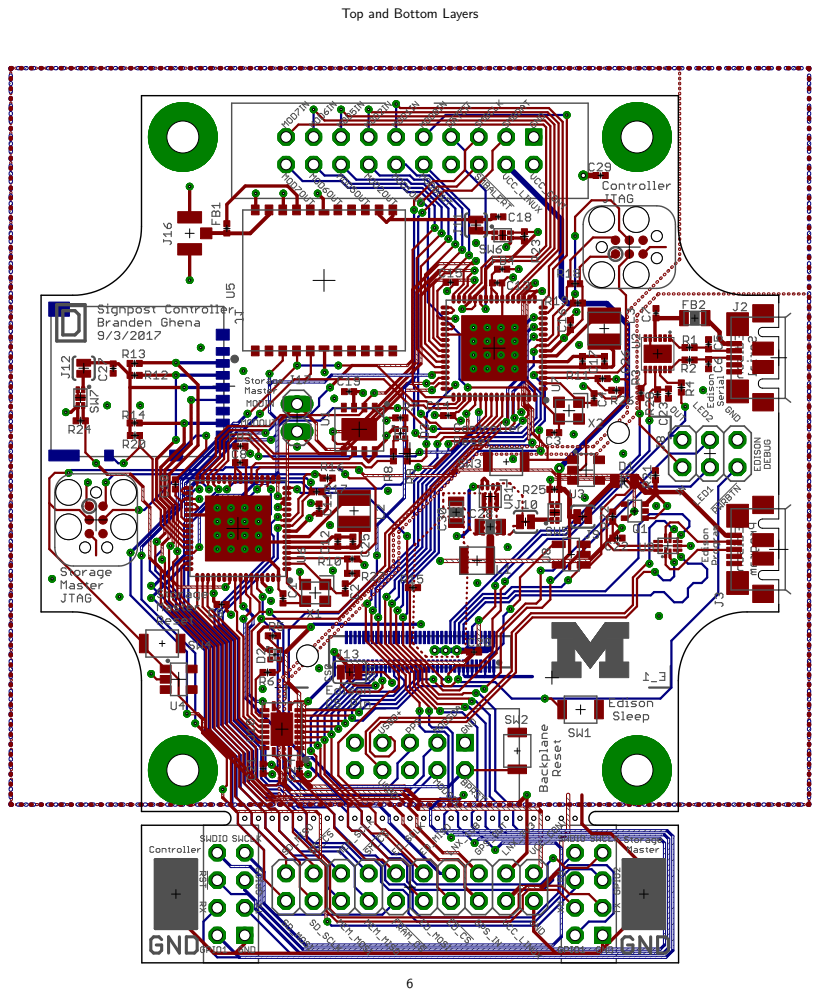
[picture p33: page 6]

## Top Layer

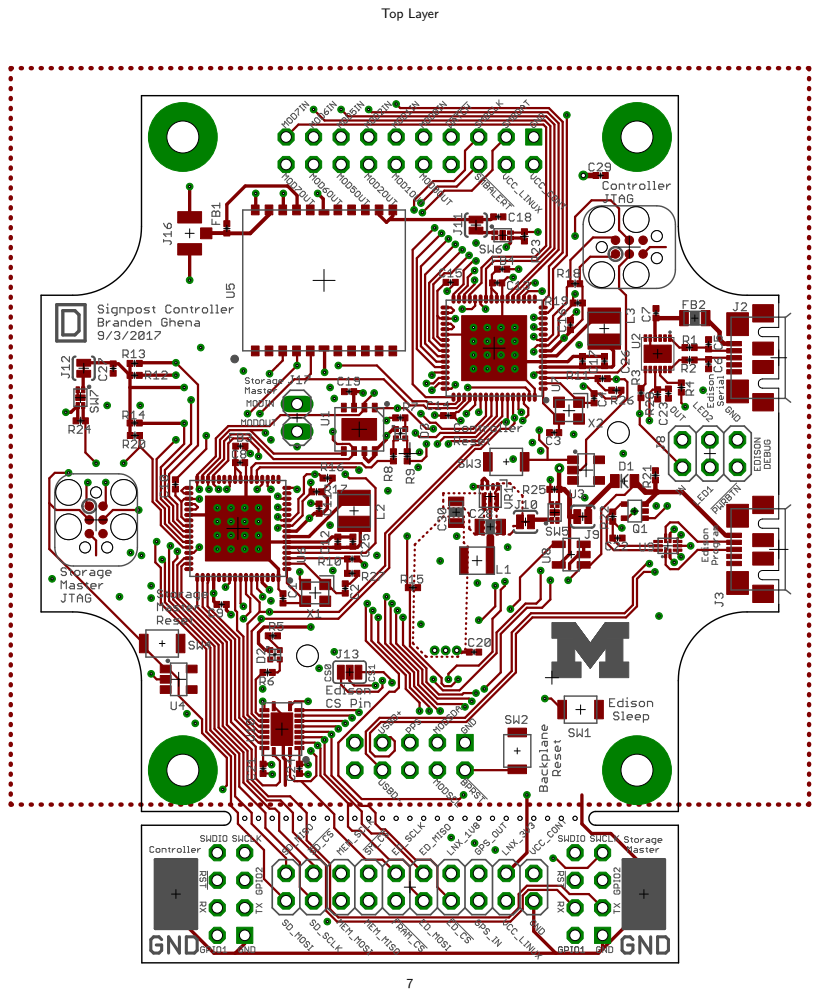
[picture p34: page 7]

## Bottom Layer

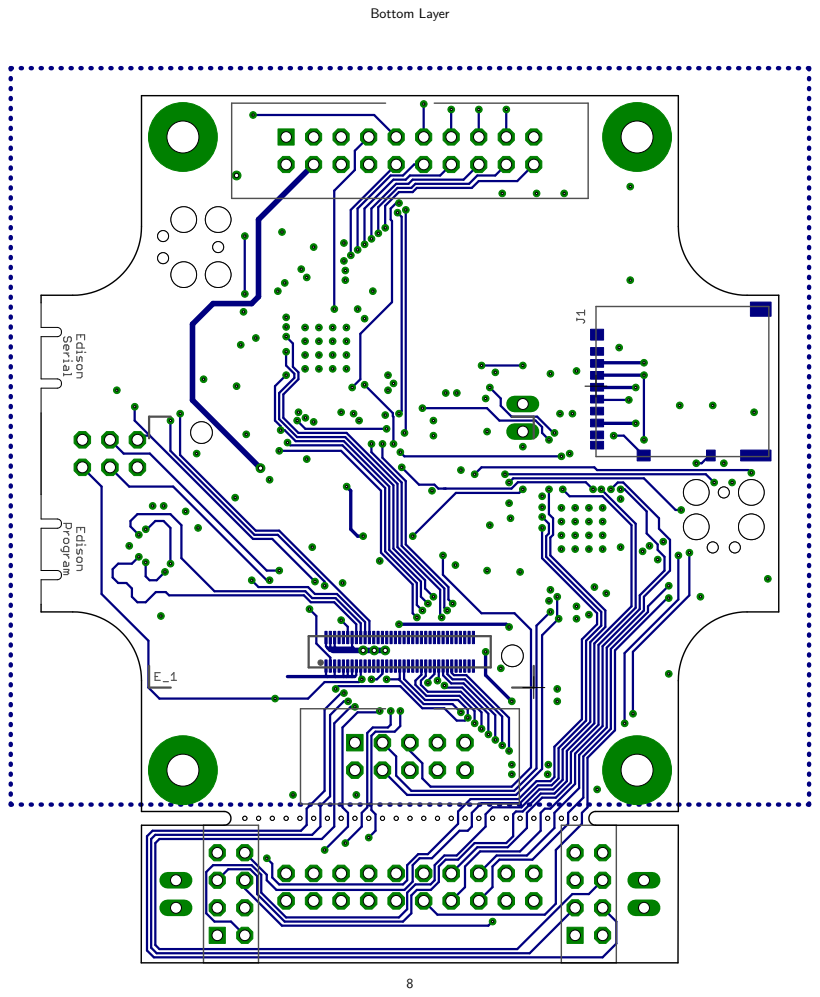
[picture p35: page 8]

## Top Copper Layer

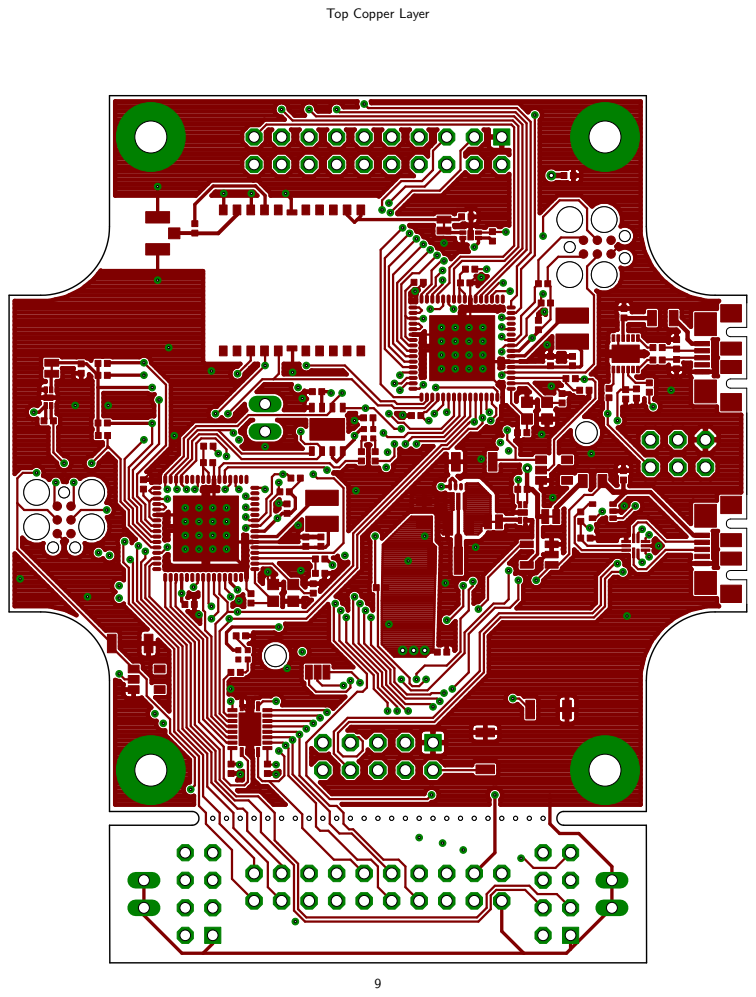
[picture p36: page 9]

## Layer 2 Copper

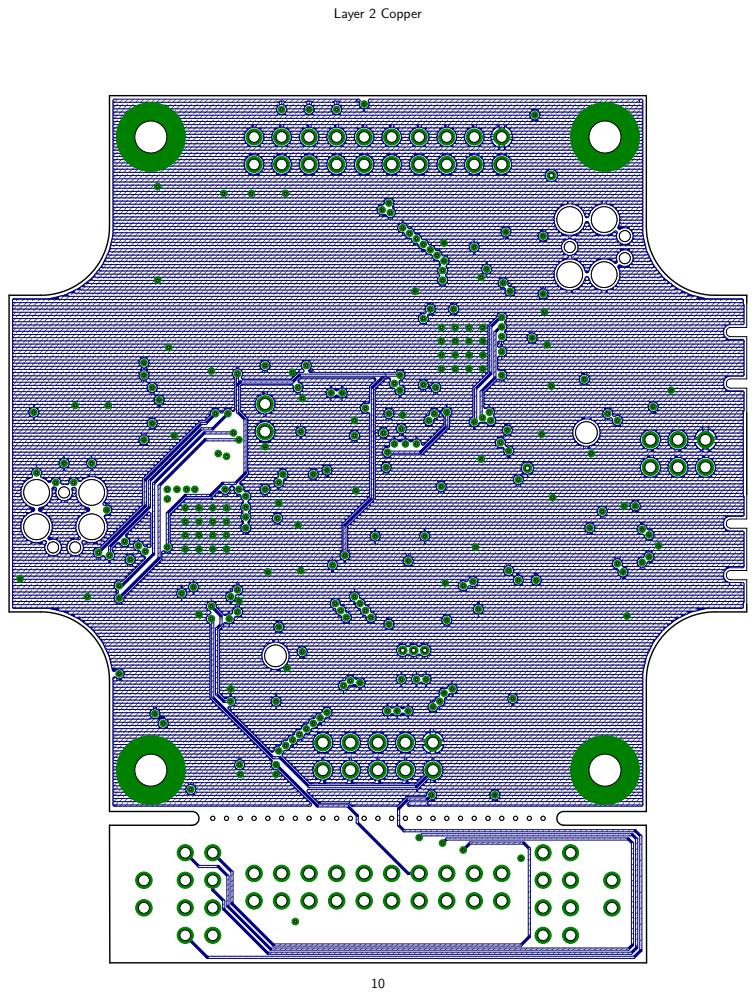
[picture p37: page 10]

## Layer 3 Copper

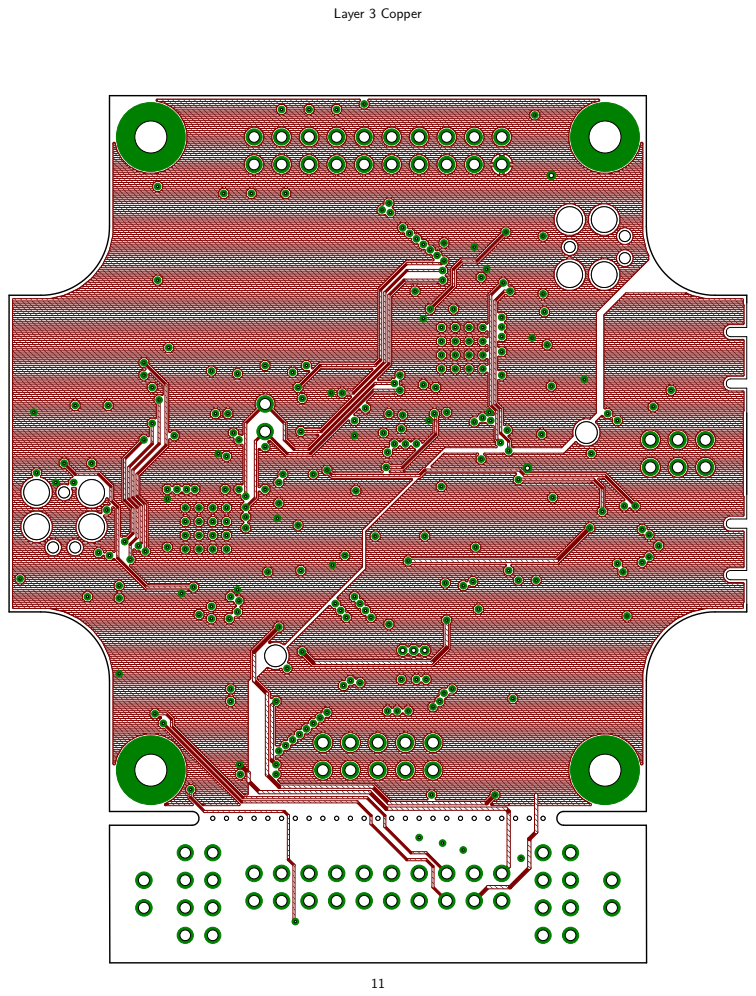
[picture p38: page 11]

## Bottom Copper Layer

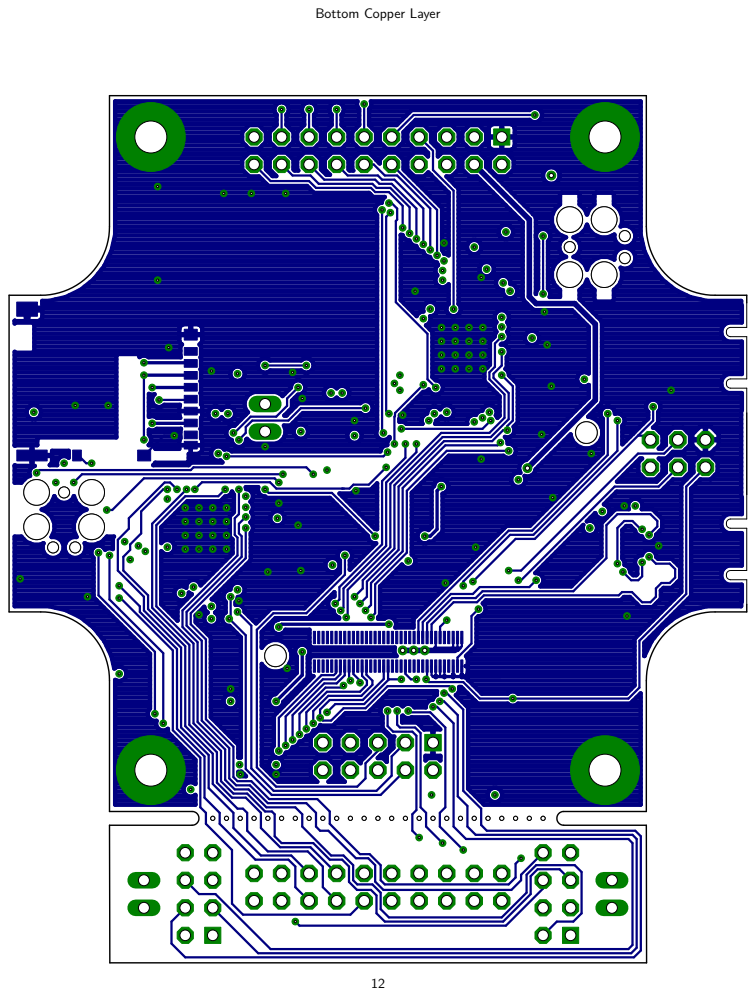
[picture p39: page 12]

## Top Paste Layer with Silkscreen


## Bottom Paste Layer with Silkscreen


## Top and Bottom Layers 1:1 Scale


## Top Layer 1:1 Scale


## Layer 2 Copper 1:1 Scale


## Layer 3 Copper 1:1 Scale


## Bottom Copper Layer 1:1 Scale


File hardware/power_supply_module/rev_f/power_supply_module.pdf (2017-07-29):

# Power Module Header

SIGNPOST PO; WER M; ODULE; VBAT-; MOUNT-PAD-ROUND3.0; MODULE_POWER; GND; SMBALERT; SMBCLK; 5 SMBDATA; VBATT+; 17 VBATT-; 18 VCC_BACKPLANE; 13 VCC_CONTROLLER; 2 VCC_LINUX; VCC_MOD0; 7 VCC_MOD1 8 VCC_MOD2 9 VCC_MOD5 10 VCC_MOD6 11 VCC_MOD7 12; VSOL+; 19 VSOL-; 20 WDI; VCC BACKPLANE (3V3) VCC LINUX (5V); VCC MOD0 (5V) VCC MOD1 (5V) VCC MOD2 (5V) VCC MOD5 (5V) VCC MOD6 (5V) VCC VSOL; MOD7 (5V) VCC BATTERY

INT/4 SCL/4 SDA/4 WDI/4


# Solar Charger


VCC BATTERY VCC BACKPLANE (3V3)

# Monitors and Watchdog


800nF = 4s reset periodConnect to GND to disable WDT

of regulator output, as well as a
(resistor) delayed short from VCC
Backplane to GND.

# EEPROM ID

0.1 uF GND; M24C01WMN; 2 VCC BACKPLANE (3V3); GND; 4 SCL; 6 SDA; 5 VCC; SCL/6 SDA/6



# Debugging


## Top and Bottom Layers


## Top Layer


## Bottom Layer


## Top Copper Layer


## Layer 2 Copper


## Layer 3 Copper


## Bottom Copper Layer


## Top Paste Layer with Silkscreen


## Bottom Paste Layer with Silkscreen


## Top and Bottom Layers 1:1 Scale


## Top Layer 1:1 Scale


## Layer 2 Copper 1:1 Scale


## Layer 3 Copper 1:1 Scale


## Bottom Copper Layer 1:1 Scale


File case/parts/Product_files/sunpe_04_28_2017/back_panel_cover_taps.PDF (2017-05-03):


Applies to the 26 marked holes

Applies to the 32 marked holes

SOLIDWORKS Student Edition.
For Academic Use Only.

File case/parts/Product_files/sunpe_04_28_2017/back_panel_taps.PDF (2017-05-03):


Applies to the 4 marked holes

Applies to the 20 marked holes

SOLIDWORKS Student Edition.
For Academic Use Only.

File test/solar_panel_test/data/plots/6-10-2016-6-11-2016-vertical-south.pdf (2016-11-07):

5 06/10

Average = 0.63 W; Time; , 19% efficiency

Solar Panel Test, south, vertical, 0.055m²

Estimated Max Power (W)

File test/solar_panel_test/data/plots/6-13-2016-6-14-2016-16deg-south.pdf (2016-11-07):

12 06/13

Average = 1.79 W; Time; , 19% efficiency

Solar Panel Test, south, 16deg, 0.055m²

Estimated Max Power (W)

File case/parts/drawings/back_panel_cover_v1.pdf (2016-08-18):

SHEET 1 OF 1; SCALE: 1:5; WEIGHT:; DWG. NO.; REV

UNLESS OTHERWISE SPECIFIED: | | NAME | DATE
DIMENSIONS ARE IN INCHES TOLERANCES: FRACTIONAL ANGULAR: MACH BEND TWO PLACE DECIMAL THREE PLACE DECIMAL | DRAWN

CHECKED | | | TITLE: back_panel_cover

ENG APPR.
MFG APPR.

INTERPRET GEOMETRIC TOLERANCING PER: | Q.A.

DO NOT SCALE DRAWING

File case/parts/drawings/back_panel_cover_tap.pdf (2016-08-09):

8-32 tap x22; 4-40 tap x32; SHEET 1 OF 1; SCALE: 1:5; WEIGHT:; DWG. NO.; REV

UNLESS OTHERWISE SPECIFIED: | | NAME | DATE

DIMENSIONS ARE IN INCHES TOLERANCES: FRACTIONAL ANGULAR: MACH BEND TWO PLACE DECIMAL THREE PLACE DECIMAL | DRAWN

CHECKED | | | TITLE: back_panel_cover_tap

ENG APPR.
MFG APPR.

INTERPRET GEOMETRIC TOLERANCING PER: | Q.A.

SOLIDWORKS Student Edition.
For Academic Use Only.

DO NOT SCALE DRAWING

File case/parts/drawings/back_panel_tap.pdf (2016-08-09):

# #4-40 tap x20

B

SHEET 1 OF 1; SCALE: 1:5; WEIGHT:; DWG. NO.; REV; SIZE; COMMENTS:; FINISH; MATERIAL

UNLESS OTHERWISE SPECIFIED: | | NAME | DATE

DIMENSIONS ARE IN INCHES TOLERANCES: FRACTIONAL ANGULAR: MACH BEND TWO PLACE DECIMAL THREE PLACE DECIMAL | DRAWN

CHECKED | | | TITLE: back_panel_tap

ENG APPR.
MFG APPR.

INTERPRET GEOMETRIC TOLERANCING PER: | Q.A.

SOLIDWORKS Student Edition.
For Academic Use Only.

DO NOT SCALE DRAWING



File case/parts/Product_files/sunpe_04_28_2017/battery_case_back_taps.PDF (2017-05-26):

M8x1.0 Thru

SOLIDWORKS Student Edition.
For Academic Use Only.

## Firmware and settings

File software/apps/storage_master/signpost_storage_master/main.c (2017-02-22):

#include <inttypes.h>
#include <stdbool.h>
#include <stdint.h>
#include <stdio.h>
#include <stdlib.h>
#include <string.h>
#include <unistd.h>

#include <i2c_master_slave.h>
#include <sdcard.h>
#include <timer.h>
#include <tock.h>

#include "app_watchdog.h"
#include "signpost_api.h"
#include "signpost_energy.h"
#include "signpost_storage.h"
#include "storage_master.h"

static void storage_api_callback(uint8_t source_address,
    signbus_frame_type_t frame_type, signbus_api_type_t api_type,
    uint8_t message_type, size_t message_length, uint8_t* message) {
  int err = SUCCESS;

  if (api_type != StorageApiType) {
    signpost_api_error_reply_repeating(source_address, api_type, message_type, true, true, 1);
    return;
  }

  if (frame_type == NotificationFrame) {
    // XXX unexpected, drop
  } else if (frame_type == CommandFrame) {
    printf("Got a command message!: len = %d\n", message_length);
    for (size_t i=0; i<message_length; i++) {
      printf("%X ", message[i]);
    }
    printf("\n");

    //XXX do some checking that the message type is right and all that jazz
    //XXX also figure out what module index this is, somehow
    int module_index = 0;

    printf("Writing data\n");

    // get initial record
    Storage_Record_Pointer_t write_record = {0};
    write_record.block = storage_status.status_records[module_index].curr.block;
    write_record.offset = storage_status.status_records[module_index].curr.offset;

    // write data to storage
    err = storage_write_record(write_record, message, message_length, &write_record);
    if (err < SUCCESS) {
      printf("Writing error: %d\n", err);
      //XXX: send error
    }

    // update record
    storage_status.status_records[module_index].curr.block = write_record.block;
    storage_status.status_records[module_index].curr.offset = write_record.offset;
    err = storage_update_status();
    if (err < SUCCESS) {
      printf("Updating status error: %d\n", err);
      //XXX: send error
    }
    printf("Complete. Final block: %lu offset: %lu\n", write_record.block, write_record.offset);

    // send response
    err = signpost_storage_write_reply(source_address, (uint8_t*)&write_record);
    if (err < SUCCESS) {
      //XXX: I guess just try to send an error...
    }

  } else if (frame_type == ResponseFrame) {
    // XXX unexpected, drop
  } else if (frame_type == ErrorFrame) {
    // XXX unexpected, drop
  }
}

int main (void) {
  printf("\n[Storage Master]\n** Main App **\n");

  // set up the SD card and storage system
  int rc = storage_initialize();
  if (rc != SUCCESS) {
    printf(" - Storage initialization failed\n");
    return rc;
  }

  // Install hooks for the signpost APIs we implement
  static api_handler_t storage_handler = {StorageApiType, storage_api_callback};
  static api_handler_t* handlers[] = {&storage_handler, NULL};
  do {
    rc = signpost_initialization_storage_master_init(handlers);
    if (rc < 0) {
      printf(" - Error initializing bus access (code: %d). Sleeping 5s\n", rc);
      delay_ms(5000);
    }
  } while (rc < 0);

  // Setup watchdog
  //app_watchdog_set_kernel_timeout(30000);
  //app_watchdog_start();

  printf("\nStorage Master initialization complete\n");
}

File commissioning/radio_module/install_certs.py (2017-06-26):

#!/usr/bin/env python


import argparse
import binascii
import os
import re
import struct
import sys
import time
import subprocess


import serial
import serial.tools.list_ports
import serial.tools.miniterm

class InstallCertificates:
    def __init__ (self, args):
        self.debug = args.debug

    # Open the serial port to the chip/bootloader
    def open (self, port):

        # Check to see if the serial port was specified or we should find
        # one to use
        if port == None:
            print('No serial port specified. Discovering attached serial devices...')
            ports = list(serial.tools.list_ports.grep('FT232R'))
            if len(ports) > 0:
                # Use the first one
                print('Using "{}"'.format(ports[0]))
                port = ports[0][0]
            else:
                return False

        # Open the actual serial port
        self.sp = serial.Serial()
        self.sp.port = port
        self.sp.baudrate = 115200
        self.sp.parity=serial.PARITY_NONE
        self.sp.stopbits=1
        self.sp.xonxoff=0
        self.sp.rtscts=0
        self.sp.timeout= 1.0
        # Try to set initial conditions, but not all platforms support them.
        # https://github.com/pyserial/pyserial/issues/124#issuecomment-227235402
        self.sp.dtr = 0
        self.sp.rts = 0
        self.sp.open()

        return True


    def run (self):

        #clear the serial ports
        self.sp.write("AT\r")
        ret = self.sp.read(8)
        time.sleep(0.1)
        
        #turn off the echo
        self.sp.write("ATE0\r")
        ret = self.sp.read(10)
        time.sleep(0.1)

        #get a list of all the files in the certs folder
        certList = os.listdir("./certs")
        
        print("\nConverting der format to pem format...")

        #If there are *.cer certs convert them to pem certs
        for file in certList:
            if(file[-3:] == "cer"):
                subprocess.call(['openssl','x509','-inform','der','-in','./certs/'+file,'-out','./certs/'+file[:-3]+'pem'])

        #now for all the pem certificates, write them to the ublox devices
        certList = os.listdir("./certs")
        for file in certList:
            if(file[-3:] == "pem"):
                #get the length of the file and the number of newlines
                length = subprocess.check_output(['wc','-c','./certs/'+file]).split()[0]
                
                #open the file
                cert = open('certs/'+file,'r');

                print("Writing " + file + " with length " + str(length))
                
                #send the command
                self.sp.write('AT+USECMNG=0,0,"'+file+'",'+str(length)+'\r')
                time.sleep(0.5)

                #send the contents of the file
                cert_str = cert.read()
                self.sp.write(cert_str)
                time.sleep(1)

            time.sleep(1)
        
        #clear the serial buffer
        self.sp.read(5000)

        #now print off all the files on the module
        self.sp.write('AT+USECMNG=3\r')
        certs = self.sp.read(5000)
        print("\nCertificates now on device:")
        print(certs)

################################################################################
## Setup and parse command line arguments
################################################################################

def main ():
    parser = argparse.ArgumentParser()

    # All commands need a serial port to talk to the board
    parser.add_argument('--port', '-p',
        help='The serial port to use')

    parser.add_argument('--debug',
        action='store_true',
        help='Print additional debugging information')

    args = parser.parse_args()

    install_certificates = InstallCertificates(args)
    success = install_certificates.open(port=args.port)
    if not success:
        print('Could not open the serial port. Make sure the board is plugged in.')
        sys.exit(1)

    install_certificates.run()

if __name__ == '__main__':
    main()

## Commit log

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2016-10-13 Use 2kOhm resistors for gauges. Fixes #13
    [power_supply_module.brd, power_supply_module.sch, power_supply_module_bom.xlsx]
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2016-10-14 Fix i2c address in kernel and add i2c functionality
    [main.c]
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2016-10-14 slight fix to grounnd plane
    [ambient-B.Cu.gbr, ambient-B.Mask.gbr, ambient-B.SilkS.gbr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]
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2016-10-15 the current radio demo code
    Will crash given time
    [main.c]
2016-10-15 Update GPS app
    Calculates coordinates correctly now
    Also adds a single-sample mode
    [main.c]
2016-10-16 add test app for missing ambient module
    [main.c]
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2016-10-17 fixed up radio module gpio
    used the fix to reset nucleum on reset
    [main.c]
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2016-10-17 Flipped mod in/out from controller's perspective
    [main.c]
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2016-10-17 more fixes, better script
    [main.c]
2016-10-18 move solar panel test to test
    no longer conflict with software
    [6-10-2016-6-11-2016-vertical-south.csv, 6-13-2016-6-14-2016-16deg-south.csv, 6-15-2016-6-15-2016-16deg-south.csv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]
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2016-10-19 get feedback from i2c master about errors
    [main.c]
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2016-10-19 call sample from main
    doesn't seem to help anything
    [main.c]
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2016-10-21 Fix typo: barometirc -> barometric
    [main.c]
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2016-10-21 No changes. Just fix bad formatting
    [main.c]
2016-10-21 Add app watchdog to audio module
    Kernel watchdog is not started for now. It seems to cause errors
    [main.c]
2016-10-22 callback and app resets seem to be working
    added a lora receive function using auto rdv
    also parse a few more bytes than the original
    pass the status byte up to the app
    [main.c]
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2016-10-23 Fixed pressure parsing in app and script Pressure reports in 3 bytes, not 2
    [main.c]
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2016-11-24 fixed the erpc test example - works with serial
    [main.c]
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2016-11-25 fixed up the storage master
    assigned some of the necessary pins
    still missing all of the spi busses
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2016-11-27 added a read ready function.
    I'm not convinced this is the right way to do this, but it works.
    Going forward we should either 1) remove the need for read_ready()
    entirely or 2) fix the underlying i2c code so that you can clock
    stretch on a read call, call
    read_ready() from the callback, then finish the read.
    I think Brad intended number 2 originally.
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2016-11-28 this code allows multiple reads
    everything after the first read is correct
    [main.c]
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2016-12-02 Added hmac/hash functions, aes not working
    [main.c]
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2016-12-03 RSA almost works, crashes at end of operation
    [main.c]
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2016-12-04 fixed memcpy bug in rpc proxy
    [main.c]
2016-12-05 Correcting CSV file to make github happy
    [controller_bom.csv]
2016-12-05 Actually correcting to make github happy
    [controller_bom.csv]
2016-12-05 Fix bom for github, maybe?
    [hail_bom.csv]
2016-12-05 Update mistaken digikey part numbers
    [hail.brd, hail.sch, hail_bom.csv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]
2016-12-05 Fix autogenerated boms
    [hail_bom.csv]
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2016-12-23 more routing, moved crystal, fixed gsm power trace
    [radio_module.brd]
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2016-12-23 Fixed tx rx to the gsm module.
    [radio_module.brd, radio_module.sch]
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2017-01-11 pulled up SIM_DETECT. Fixed resistor for GSM pg
    [radio_module.brd, radio_module.sch]
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2017-01-18 changed mcp23008 to qfn, fixed enabled leds/resistors
    [debug_backplane.brd, debug_backplane.sch]
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2017-01-19 added correct usb headers
    [debug_backplane.brd, debug_backplane.sch]
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2017-01-19 renumbered parts, fixed silk
    [battery_pack.brd, battery_pack.sch]
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2017-01-19 fixed a few part numbers in the BOM and board
    [battery_pack.brd, battery_pack.sch, battery_pack_bom.csv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]
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2017-01-19 update to fix comments
    [audio_spectrum.brd, audio_spectrum.sch]
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2017-01-20 fixed debug backplane schematic, vtref problem, usb problem
    also checked usb spacing and lined them up with the board
    also added power supply loops
    [debug_backplane.brd, debug_backplane.sch]
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2017-01-20 Checkpoint. 35 airwires
    Okay, I know that doesn't sound like an impressive change from the last
    commit, but actually some parts moved around that are a pretty big deal
    for getting more future progress so stop judging me.
    [controller.brd]
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2017-01-21 fixed up silk screen, renamed parts
    [debug_backplane.brd, debug_backplane.sch]
2017-01-21 fixed some drc errors
    [debug_backplane.brd]
2017-01-22 fixed a part label
    [debug_backplane.brd]
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2017-01-22 Cosmetic fixes
    [controller.brd]
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2017-01-22 Package up the gerbers
    There was already a zip file, but it was named wrong and I wasn't sure
    if it had the right files in it
2017-01-22 BOM updates for Controller and Ambient
    Fixing digikey part numbers
    [ambient_BOM.csv, controller.brd, controller.sch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]
2017-01-23 fixed a lot of little things
    [debug_backplane.brd, debug_backplane.sch]
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2017-01-24 fixed the SIM card part (it was backwards)
    [radio_module.brd, radio_module.sch]
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2017-02-01 added pull downs on the LEDs and fixed prog lights
    [debug_backplane.brd, debug_backplane.sch]
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2017-02-02 fixed up the header and debug info
    [debug_backplane.brd, debug_backplane.sch]
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2017-02-02 found a bug
    [debug_backplane.brd, debug_backplane_bom.xlsx, debug_backplane_bom_digikey.xlsx]
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2017-02-04 fix warnings
    - %d -> %ld format specifiers
    - void main() -> int main()
    - add missing header
    [main.c]
2017-02-04 fix warnings: missing headers, printf format
    [main.c]
2017-02-04 fix missing / remove unused headers
    [main.c]
2017-02-04 ltc2941_selecter_test: fix benign warnings
    - add missing / remove unused imports
    - unused attribute
    [main.c]
2017-02-04 audio_test: add missing header
    [main.c]
2017-02-04 module_i2c_test: add missing header
    [main.c]
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2017-02-06 swapped SO/SI and add test points for flash chip
    [audio_spectrum.brd, audio_spectrum.sch]
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2017-02-09 Re-ran gerbers after fixing error
    DRC wasn't set up with proper clearance for the inner layers
    [audio_spectrum.brd]
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2017-02-10 bump to tock master
    picks up a bunch of new warnings - should help us catch missing statics
    and misconfigured headers
    [main.c]
2017-02-11 bump to tock master
    the mbedtls library is a little noisy in warnings, which we could
    maybe turn off, but I actually think are really low hanging fruit
    and are just worth fixing
    [main.c]
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2017-02-15 WIP: get rid of build error from incomplete impl
    [main.c]
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2017-02-16 fix signpost entropy warnings
    @nealjack the missing prototype stuff comes from gcc wanting (void)
    instead of just () for functions w/ no arguments. A bit pedantic,
    but that same warning lets us catch things that are missing `static`
    qualifiers, which has caused headaches a few times, so it feels worth
    it.
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2017-02-17 fixup global entropy changes
    need to call entropy init in appropriate places now
    also the drbg buffer thing seems to be stored in the ctx, so that
    needs to be static, not on the stack
    [main.c]
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2017-02-17 pass length back up recv path correctly
    [main.c]
2017-02-17 fix app_send/recv_test for key fn
    attn @nealjack
    [main.c]
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2017-02-17 add missing const qualifiers
    attn @adkinsjd
    [main.c]
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2017-02-17 fix up gpio and leds in audio/microwave
    [main.c]
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2017-02-18 fix -94 issue. oh crap, this'll only work for me
    [main.c]
2017-02-18 Storage message API
    Not currently working. Drops message with HMAC failure
    [main.c]
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2017-02-18 Update storage master test
    Doesn't actually work with 1200 bytes
    [main.c]
2017-02-19 fixed warning in fake_radio
    [main.c]
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2017-02-19 added a reset call to tell the receiver it reset
    [main.c]
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2017-02-20 WIP: signpy stuff
    next up a mixin or some such? need to fix
    AttributeError: 'FrameType' object has no attribute 'to_bytes'
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2017-02-20 fixed it so now we can print out gps_console
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2017-02-20 fix headers / warnings
    [main.c]
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2017-02-21 Got storage master to initialize with controller
    since it doesn't have dedicated i/o lines for this, it simply tries
    every 5 seconds
    TODO need to make sure controller shuts off i2c
    Also fixed some apps that use the underlying network stuff
    [main.c]
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2017-02-21 fix for travis build
    [main.c]
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2017-02-22 READMEs all over apps!
    Tried to explain from a high level what was going on in each high-level
    folder. This doesn't yet go down into individual apps to explain them.
    [main.c]
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2017-02-22 commit these changes in case doc folk come through
    warning fixes coming next
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2017-02-22 handle transport errors in controller
    [main.c]
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2017-02-22 jk, there's one more in storage family to fix
    [main.c]
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2017-02-22 Check signpost_initialize error codes
    [main.c]
2017-02-22 fix two more unchecked returns
    [main.c]
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2017-02-22 Ensure radio module gets initialized first
    HACK for debug backplane
    Added delay for debug backplane "radio" clock to stabilize. Without it
    GPIOs were not stabilizing. #23
    [main.c]
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2017-02-24 added a simple command to send bytes to a destination.
    You can listen for these bytes with the networking API
    Also fixed up debug radio to print these types of messages
    with a new escape character
    [main.c]
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2017-03-07 Delete README.md
    This is just lies currently. Should replace with something accurate when erpc actually works
2017-03-07 backplane: clean up MOD7 USB traces a bit
    MOD7 USB didn't work on one board. I didn't actually debug that
    board, but may as well clean these up while we're doing things.
    [backplane.brd]
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2017-03-08 backplane: replace USB caps with shorter package
    [backplane.brd, backplane.sch]
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2017-03-08 debug_backplane: add debug USB hub **sch only**
    attn @adkinsjd: @brghena had the good idea to add a second FTDI for
    the debug radio, giving one serial connection for the "radio uplink"
    and one for "radio debug", where the former handles all the data
    tunneling and the latter is for debugging the fake radio itself.
    I've added that because the marginal cost of another FTDI chip is
    minimal and we still have another open port on the USB hub if we
    want it for something, but wanted to bring that change to your
    attention.
    TODO: Deal with the power-on-reset and possible runtime reset for
    the USB hub.
    [debug_backplane.brd, debug_backplane.sch]
2017-03-08 debug_backplane: replace switches w/ easier to press *sch only*
    Use the octoprog switches instead of the miniature hail switches
    [debug_backplane.brd, debug_backplane.sch]
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2017-03-08 debug_backplane: add missing connections to gpio extender
    oops
    [debug_backplane.brd, debug_backplane.sch]
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2017-03-09 bat cable gland to M8, more solar mount clearance
    [battery_case.SLDASM, battery_case_back.SLDPRT, solar_mount_top.SLDPRT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]
2017-03-09 added missing parts to BOM, changed some sizes
    specifically:
    added cable gland, hey waterproof cable entires
    changed solar mount screw to 7/16 len
    reduced solar standoff to 1/2 len
    [signpost_case_bom.xlsx]
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2017-03-09 debug_backplane: WIP
    - explain module USB host port
    - replace debug LED 2x1NFETs with the Q11 2NFET array
    - general schematic cleanup
    - start laying out bottom debug area
    [debug_backplane.brd, debug_backplane.sch]
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2017-03-12 debug_backplane: WIP - mostly laid out
    - lay out power supply section
    - add terraswarm logo
    - clean up original USB layout
    - replace debug LED resistors with array
    - reorder DBG USB ports for layout & lay out hub
    - use supply symbols in schematic (lbr update)
    - use headers and resistor array for enabled blocks
    - finish layout out left edge text and components
    - pretty much everything placed but fake radio, and there's a good space for it
    [debug_backplane.brd, debug_backplane.sch]
2017-03-12 double checking rx/tx/rts/cts - fixed nucleum+labels
    [radio_module.brd, radio_module.sch]
2017-03-12 debug_backplane: WIP
    - put top-level debug hub on 3v3_unmetered, not vcc_backplane
    - power module discretes 0402 -> 0603, also chip resistors for some
    - layout: most of the coulomb counter region
    - lbr: fix name font for i2c address translator
    [debug_backplane.brd, debug_backplane.sch]
2017-03-12 WIP routing watchdog
    Fixed #15 paste layer for pm ICs
    [power_supply_module.brd, power_supply_module.sch]
2017-03-12 Routed watchdog
    TODO need to add momentary button for manual reset
    [power_supply_module.brd]
2017-03-12 Fix up silk + add testpoint for vbatt-monitor
    [power_supply_module.brd, power_supply_module.sch]
2017-03-12 debug_backplane: WIP
    - Clean up ERC warnings
    - Renumber C's and R's
    - Update controller for !WATCHDOG
    - Assign fake radio GPIO/LED pins
    - Route lower chunk
    - Add power-on-reset for top-level USB hub
    [debug_backplane.brd, debug_backplane.sch]
2017-03-14 debug_backplane: WIP
    - add extra pin1 indicator for D8 (covered by silkscreen ring)
    - replace usb hub resistors with chip resistors
    - add global reset
    - place all components onto board
    - add copy of controller bottom header (TODO: position!)
    - relayout top debug header
    - some idle routing
    [debug_backplane.brd, debug_backplane.sch]
2017-03-14 debug_backplane: WIP
    - replace power-on-reset with open collector, fixed time variant
    - rotate the last headers at the top of the board
    - more routing
    [debug_backplane.brd, debug_backplane.sch]
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2017-03-14 added attributes, renumbered, fixed up labels
    [radio_module.brd, radio_module.sch]
2017-03-15 fixed nano sim part, cleaned up radio board
    [radio_module.brd, radio_module.sch]
2017-03-15 trying to get ts demo working w/ signpost api
    ported the radio_demo app to a new singpost api one
    modified sense and send to just use the networking send function
    nordic stuff doesn't seem to be working on the newest kernel
    [main.c]
2017-03-15 added eeprom, fixed some issues
    [power_supply_module.brd, power_supply_module.sch]
2017-03-15 Fix up labels, mounting holes
    [power_supply_module.brd, power_supply_module.sch]
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2017-03-15 fixed radio module kernel - works now.
    I need to fix the uart output for debug in io.rs
    I needed to add the debug interface to main.rs - it wasn't fully added, and
    this was causing a panic.
    I also had to double the app size limit
2017-03-15 this seems to be working if I comment out BLE
    It has a memory error otherwise
    [main.c]
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2017-03-15 debug_backplane: WIP
    - replace vias with #4 hole parts
    - add labels to every sheet
    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
    [debug_backplane.brd, debug_backplane.sch]
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2017-03-16 signpost.lbr: fix !WATCHDOG pin for backplane power module
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2017-03-17 fix up 0 widths
    [power_supply_module.brd, power_supply_module.sch]
2017-03-17 fix ohm symbol
    [power_supply_module.brd, power_supply_module.sch]
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2017-03-17 fix resistor 240->240k
    [power_supply_module_bom.xlsx]
2017-03-18 changed app watchdogs to 1 minutes
    If a module resets, then it could take up to 10 seconds for unisolation
    Modules need to not reset just due to i2c starvation
    [main.c]
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2017-03-22 app not hanging now - fixed bonus timer (command_num++)
    [main.c]
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2017-03-24 Prototype FAT FS in userspace for storage module (#47)
    * Prototype FAT FS in userspace for storage module
    Uses the elm FatFS library (http://elm-chan.org/fsw/ff/00index_e.html)
    to mount, format and traverse the root directory of an SD card with the
    FAT file format.
    * Fat test: fix f_mkfs size bug
    [main.c]
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2017-03-26 changed to delay while amit fixes timer bug
    [main.c]
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2017-03-26 backplane: add power-on-reset to USB Hub
    [backplane.brd, backplane.sch]
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2017-03-28 fixed up energy printing app
    [main.c]
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2017-03-28 reverted this to an older version
    [main.c]
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2017-03-29 fixed a bug with taking the max motion confidence
    [main.c]
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2017-03-29 fixed queue length calculation
    [main.c]
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2017-03-29 initialization with watchdogs is hard
    had to add provisions so that you don't try to send until radio is
    initialized but so that the watchdog still gets tickled enough that the
    controller doesn't reset during initialization (indefinitely hanging
    that module in the current library)
    [main.c]
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2017-04-20 fixed solar mount to better capture bolts and allow for tamper resistance
    [solar_mount_top.SLDPRT]
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2017-04-28 seinduino: fix connection to monostable vibrator
    For this IC, a rising edge trigger should be fed into B, not !A
    [arduino.brd, arduino.sch]
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2017-05-12 fixed some part numbers
    [radio_module.brd, radio_module.sch]
2017-05-12 more part fixes, finalizing routing and silk
    [radio_module.brd, radio_module.sch]
2017-05-12 removed DRC errors
    [radio_module.brd]
2017-05-12 fixed up some schematic aesthetics
    [radio_module.brd, radio_module.sch]
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2017-05-16 fixed a few of the part numbers
    [radio_module.sch]
2017-05-16 fixed a consistency error
    [radio_module.brd, radio_module.sch]
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2017-05-16 fixed pin numbers on the rf spectrum analyzer
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2017-05-16 fixed inner layer vias
    [radio_module.brd]
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2017-05-16 fixed drc
    [rf_spectrum.brd]
2017-05-16 backplane: fix 4.7 uF part number in BOM
    [backplane_bom.csv, backplane_bom.xlsx]
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2017-05-17 Fixed tons of issues
    - drc fixes
    - moved/renamed/added labels
    - lots of other nits
    [power_supply_module.brd]
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2017-05-17 rename passives, fix silk
    [power_supply_module.brd, power_supply_module.sch, power_supply_module_bom.xlsx]
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2017-05-18 fix some part number attributes
    [power_supply_module.brd, power_supply_module.sch, power_supply_module_bom.csv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]
2017-05-18 debug_backplane: fix S14-S18 labels
    [debug_backplane.brd]
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2017-05-20 changed small text error, removed unnecessary via
    [rf_spectrum.brd]
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2017-05-20 fixed bom formatting using eagle script
    [rf_spectrum_bom.csv]
2017-05-23 add missing `void` to quiet warning
    [main.c]
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2017-05-25 Saving future me from having wrong packages at assembly
    [radio_module.brd, radio_module.sch, radio_module_bom.csv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]
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2017-05-27 Add rev e
    Change watchdog/reset behavior
    Now use fet to disable regulators, drain backplane network
    [power_supply_module.brd, power_supply_module.sch]
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2017-05-30 added submodule, fixed readme, removed software folder
    [main.c]
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2017-06-20 Actual version C sent to fab
    Mistakenly forgot OE pull down and PPS to storage master
    [controller.brd, controller.sch]
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2017-06-28 backplane: hub !BUSPWR -> high
    Resolves errata from revC:
    USB !BUSPWR is wrong: Currently tied to GND, which states that the hub and
    all downstream devices are powered from the upstream port. Should be tied
    high, stating that the hub has an "external" power supply. In both modes,
    the hub still will perform overcurrent and poweroff protections.
    - Symptom: This limits the hub to 500mA max total draw, as each
    downstream port has a minimum 100mA allotment (USB spec), so the hub
    disables higher ports (cannot use USB in Module 5 or Module 7 slot)
    - Remedy: Cut trace at pin 10 (!BUSPWR) and short pins 10 and 9.
    [backplane.brd, backplane.sch]
2017-06-28 debug_backplane: module hub !BUSPWR -> high
    mirros the d43e926 fix to the backplane
    [debug_backplane.brd, debug_backplane.sch]
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2017-07-11 debug_backplane: eagle version DRC churn?
    saved after DRC, order of approved errors changed but nothing else
    /shrug
    [debug_backplane.brd]
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2017-07-14 debug_backplane: add missing attrs for caps
    [debug_backplane.brd, debug_backplane.sch]
2017-07-14 debug_backplane: fix numbering/value/attr of DNPs
    [debug_backplane.brd, debug_backplane.sch]
2017-07-14 debug_backplane: add some more missing attributes
    [debug_backplane.brd, debug_backplane.sch]
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2017-07-18 debug_backplane: add more missing attrs
    [debug_backplane.brd, debug_backplane.sch]
2017-07-18 debug_backplane: fix Q numbering; attrs
    [debug_backplane.brd, debug_backplane.sch]
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2017-07-18 Revert "debug_backplane: mass update of attrs via script"
    This reverts commit 00e90df064c4474ec51087fa06a80b5e492eed0b.
    Some missing things should've been done before this
    - renumber C's (could have gone after)
    - double check the mix of 0402/0603 passives (bigger problem)
    [debug_backplane.brd, debug_backplane.sch]
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2017-07-18 debug_backplane: fix VDDCORE/VDDOUT caps
    [debug_backplane.brd, debug_backplane.sch]
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2017-07-18 debug_backplane: fix C1/2 attrs
    [debug_backplane.brd, debug_backplane.sch]
2017-07-18 debug_backplane: fixup some more C 0402/0603 attrs
    [debug_backplane.brd, debug_backplane.sch]
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2017-07-18 debug_backplane: add missing attrs
    [debug_backplane.brd, debug_backplane.sch]
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2017-07-20 debug_backplane: no watchdog pulldown & renumber R
    from @nealjack: the watchdog reset line does not need a pull down resistor, as it is push/pull
    [debug_backplane.brd, debug_backplane.sch, debug_backplane_bom.xlsx]
2017-07-22 debug_backplane: Cut off power on watchdog event
    This better mimics what happens on the actual backplane as opposed
    to simply triggering a reset
    [debug_backplane.brd, debug_backplane.sch]
2017-07-22 debug_backplane: fixup BOM for two new switches
    [debug_backplane_bom.xlsx]
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2017-07-23 added rev_d, fixed cap placement
    [ambient.kicad_pcb, ambient.sch, ambient_BOM.csv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]
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2017-07-24 fixed supply parts
    [microwave.brd, microwave.sch]
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2017-07-29 Fix up component names
    Change gnd symbol to SUPPLY, test points to TP, and switches to S. Works
    better with eagle bom script
    [power_supply_module.brd, power_supply_module.sch]
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2017-08-07 fixed spec reset airwire
    [audio_spectrum.brd, audio_spectrum.sch]
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2017-09-03 added rev_c
    The only major change is to fix the switching regulator
    [radio_module.brd, radio_module.sch]
2017-09-03 fixed outline layer
    [radio_module.brd]
2017-09-03 fixed digikey part numbers
    [radio_module.brd, radio_module.sch]
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2017-09-04 updates to battery board
    Switch for installation
    better solder points
    Thinner to match case
    Flip so text is right side up
    Added digikey part numbers
    [battery_pack.brd, battery_pack.sch]
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2017-09-04 ambient: remove old pressure; prop josh's sch->pcb
    This is a WIP commit. It forwards Josh's fixes for the wrong switching
    caps; it deletes his extraneous extra jtag resistors; and it removes
    the two pressure sensors we aren't using.
    [ambient.kicad_pcb, ambient.sch, ambient_BOM.csv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]
2017-09-04 Changed isolator voltage source
    Left side of the isolator is now connected to VCC_CONTROLLER, which is
    the source of _almost_ all of its I/O lines. The except is the indicator
    LED, which is powered from VCC_LINUX_3V3. In that case though, there's a
    diode preventing current from flowing from Controller to Linux domain if
    Linux is disabled.
    [controller.brd, controller.sch]
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2017-09-04 ambient: DRC fixes
    [ambient.kicad_pcb]
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2017-09-05 ambient: fix plane gap; remove extra silk off board
    [ambient-B.Cu.gbr, ambient-Edge.Cuts.gbr, ambient-F.Adhes.gbr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]
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2017-09-06 fixed pin mapping, added RTS/CTS
    [rf_spectrum.brd, rf_spectrum.sch]
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2017-09-06 fixed up a bit of silk
    [rf_spectrum.brd]
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2017-09-06 fixed BOM line item
    [rf_spectrum.brd, rf_spectrum.sch, rf_spectrum_bom.csv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]
2017-09-06 updated rf spectrum with fixed attribute
    [rf_spectrum.brd, rf_spectrum.sch, rf_spectrum_bom.csv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]
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2017-09-16 debug_backplane: remove GND from iso switches
    The isolation override switches have a momentary short when thrown.
    For the LED control, this was shorting 3v3_unmetered to gnd. Just
    let the LEDs float when they're off; no need to ground them.
    [debug_backplane.brd, debug_backplane.sch]
2017-09-16 debug_backplane: don't reset debug usb hub
    If you want to reset this, you can pretty much just pull the plug
    on the board
    [debug_backplane.brd, debug_backplane.sch]
2017-09-16 debug_backplane: don't reset FTDIs either
    follows the same logic as the last commit
    [debug_backplane.brd, debug_backplane.sch]
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
